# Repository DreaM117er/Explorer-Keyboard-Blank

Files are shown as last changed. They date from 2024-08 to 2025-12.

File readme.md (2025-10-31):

# Explorer Keyboard Blank 探索者3號

|4x6 v1|5x6 v1|
|--|--|
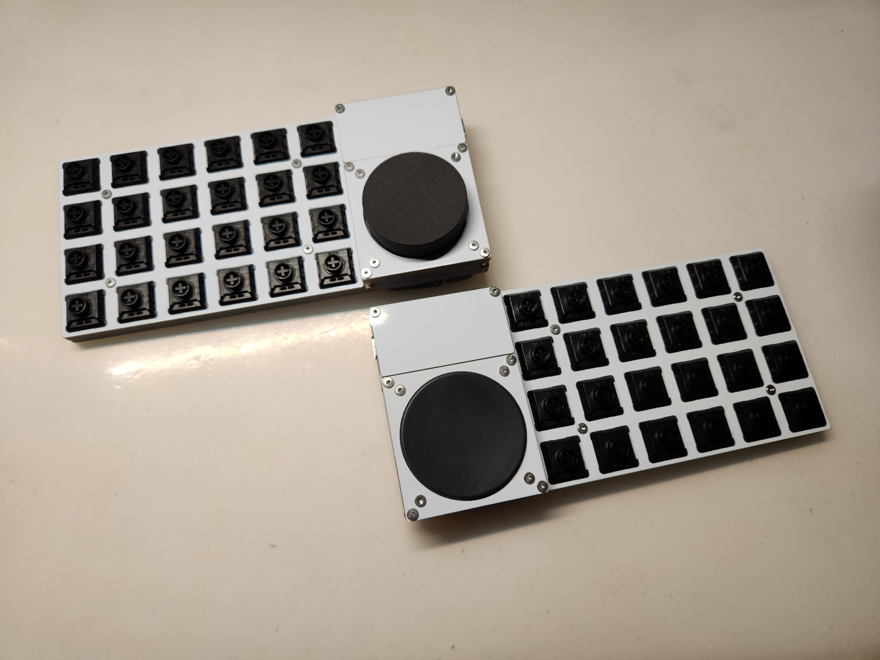
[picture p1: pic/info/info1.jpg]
info1
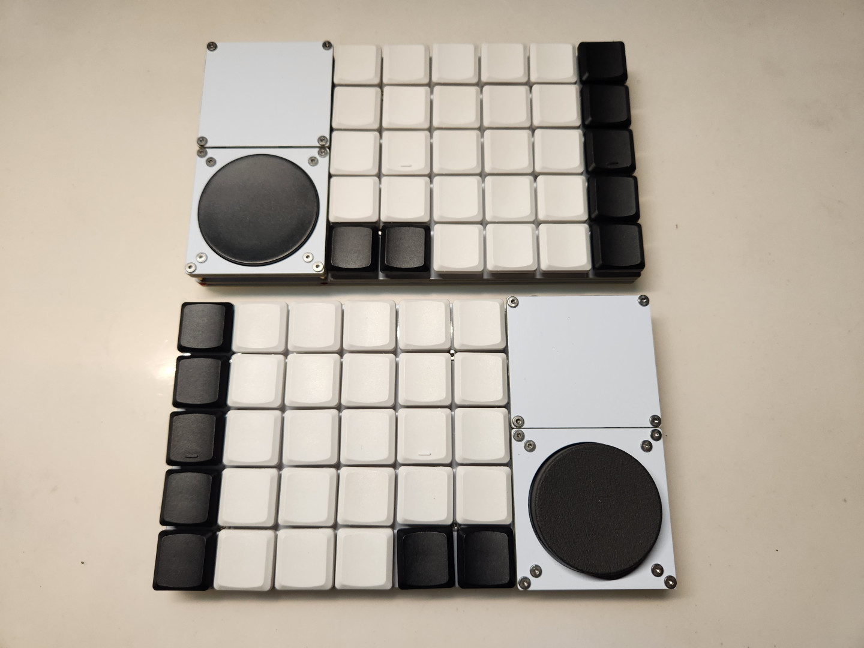
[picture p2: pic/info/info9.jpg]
info9
|||
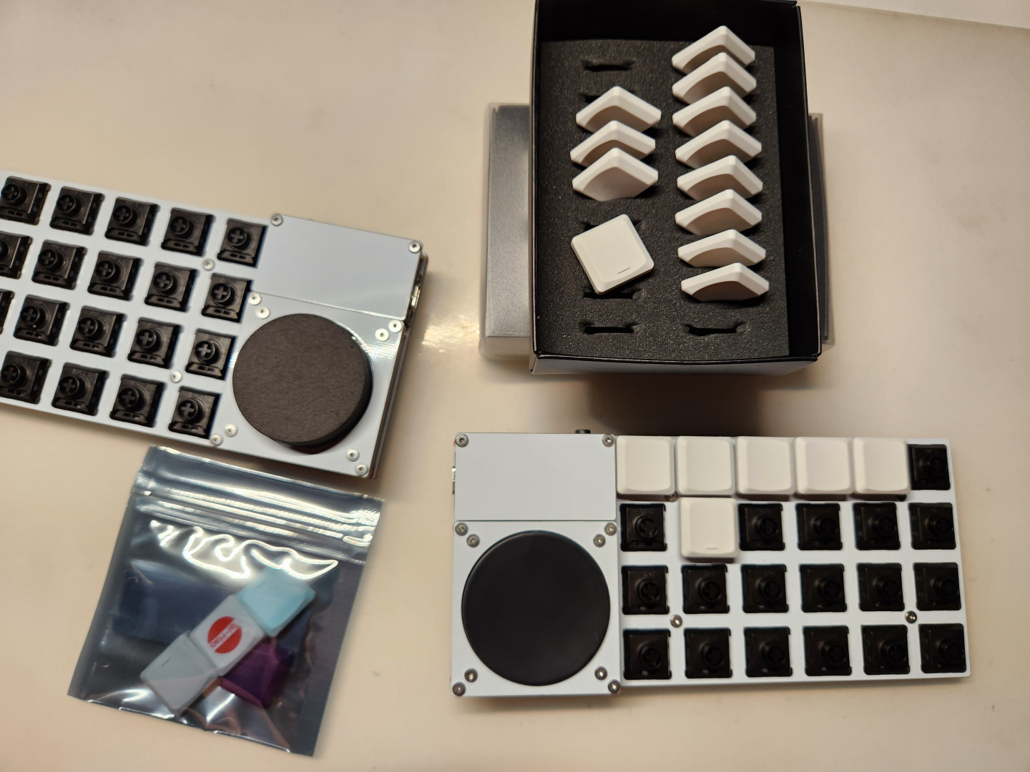
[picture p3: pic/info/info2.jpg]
info2
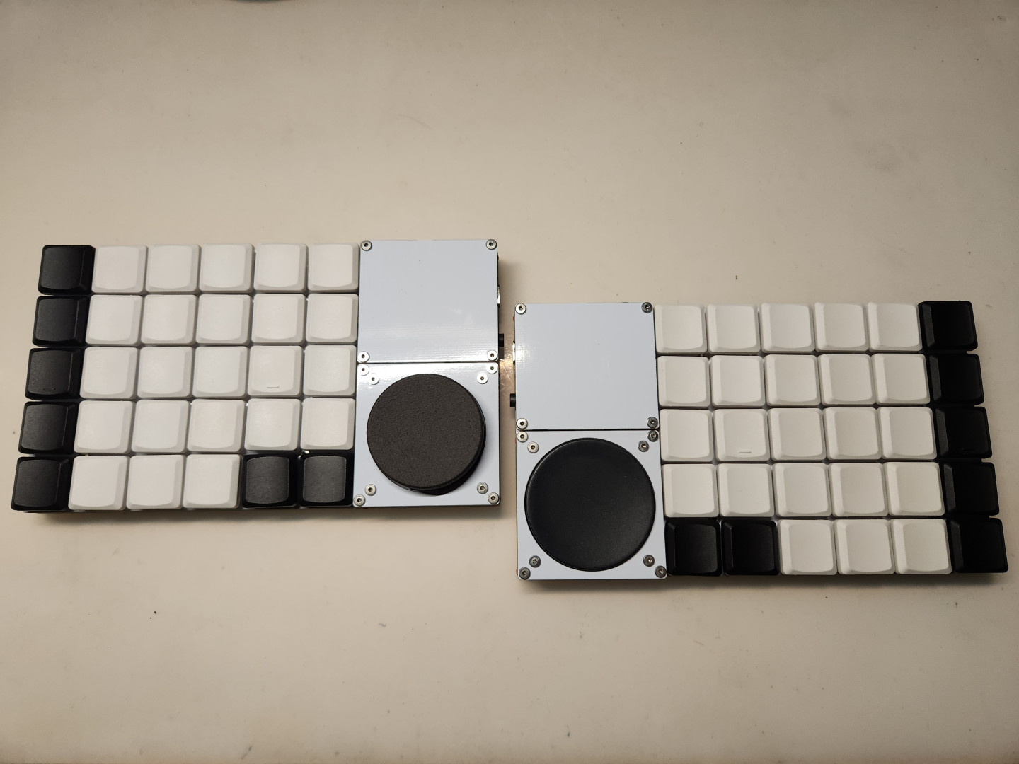
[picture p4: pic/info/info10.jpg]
info10
|||
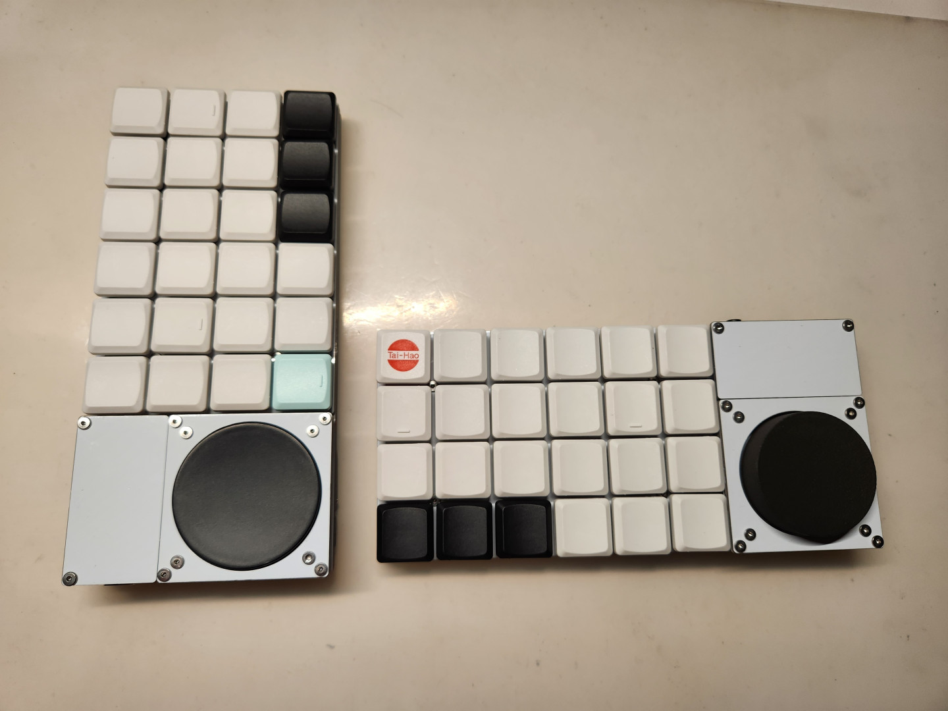
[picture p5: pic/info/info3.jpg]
info3
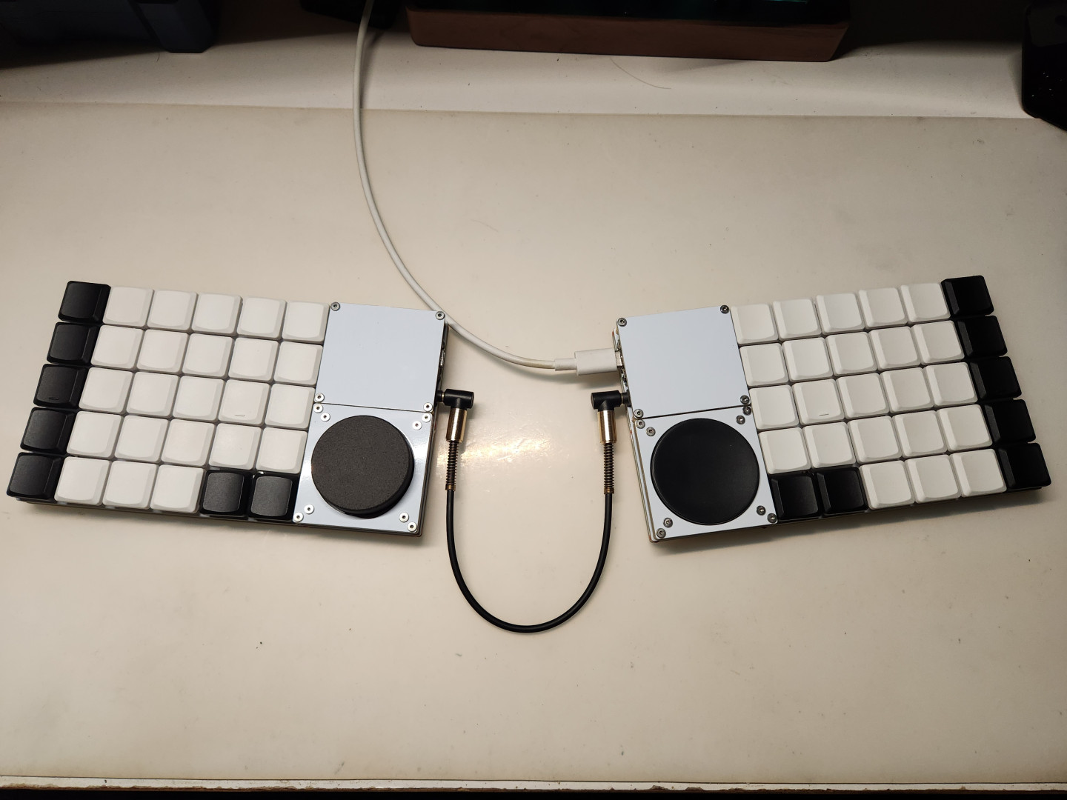
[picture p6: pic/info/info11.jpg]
info11
|||
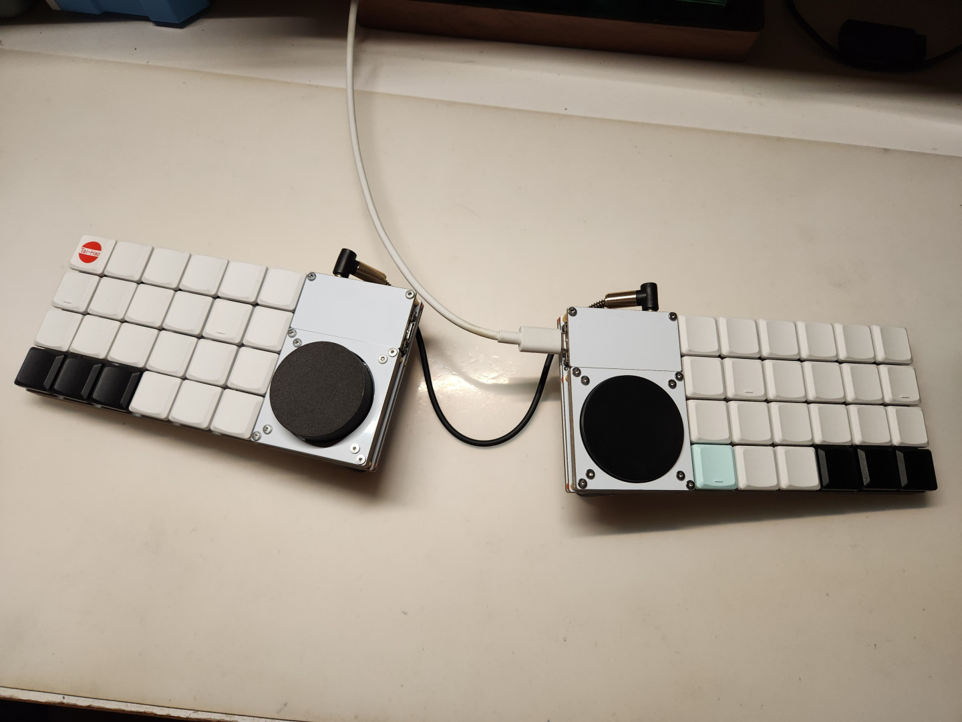
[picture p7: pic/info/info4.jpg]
info4
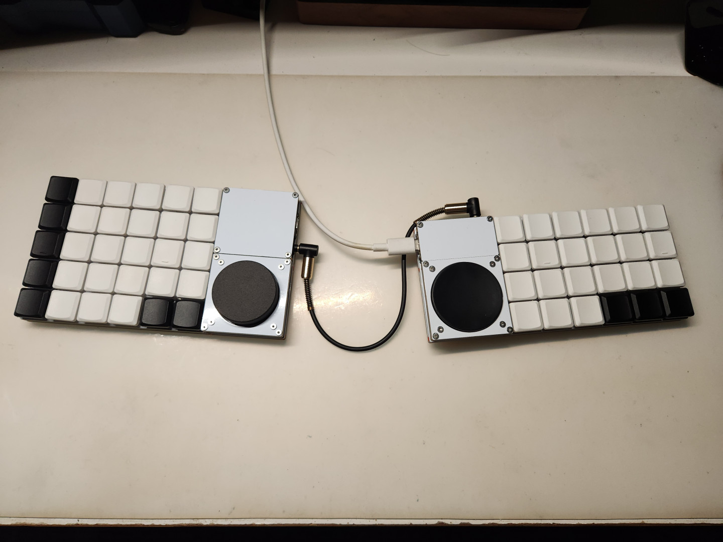
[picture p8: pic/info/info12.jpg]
info12
|||

## 開發者前言

Plank，是大部分人入坑人體工學鍵盤時最常接觸到的鍵盤，因為它方且正，許多的人體工學鍵盤的基礎都是在這個方正的鍵盤上延伸；

Blank，翻譯成中文的意思為空白。結合了Plank所需要的基礎，進而把鍵盤拓展成可分離的版本，你可以只使用單側、也可以使用兩側、可以在你需要的那一側加裝自己需要的特殊元件，也可以將元件放置在手的左或右側...

並且支援Kailh矮軸Choc v1、v2、Gateron矮軸GLP雙熱插拔，選擇自己所喜歡的按鍵軸及鍵帽——

因此將它歸為探索者系列，稱之為Blank，稱之為3號。

## 靈感來源

- 我只是想做一把簡單的鍵盤。
- 開發上一把鍵盤時發現我最多只需要2顆旋鈕。
- 不想思考太多。
- 突然想到自己曾經在beekeeb上看到Cirque 40mm的觸控板模組。
- 試試看做個能同時翻面支援的電路板好了。

如果想知道完整的開發過程，請詳細閱讀[開發日誌](log.md)中的內文。

## 前置作業

### 電路板

||4x6 v1|5x6 v1|
|--|--|--|
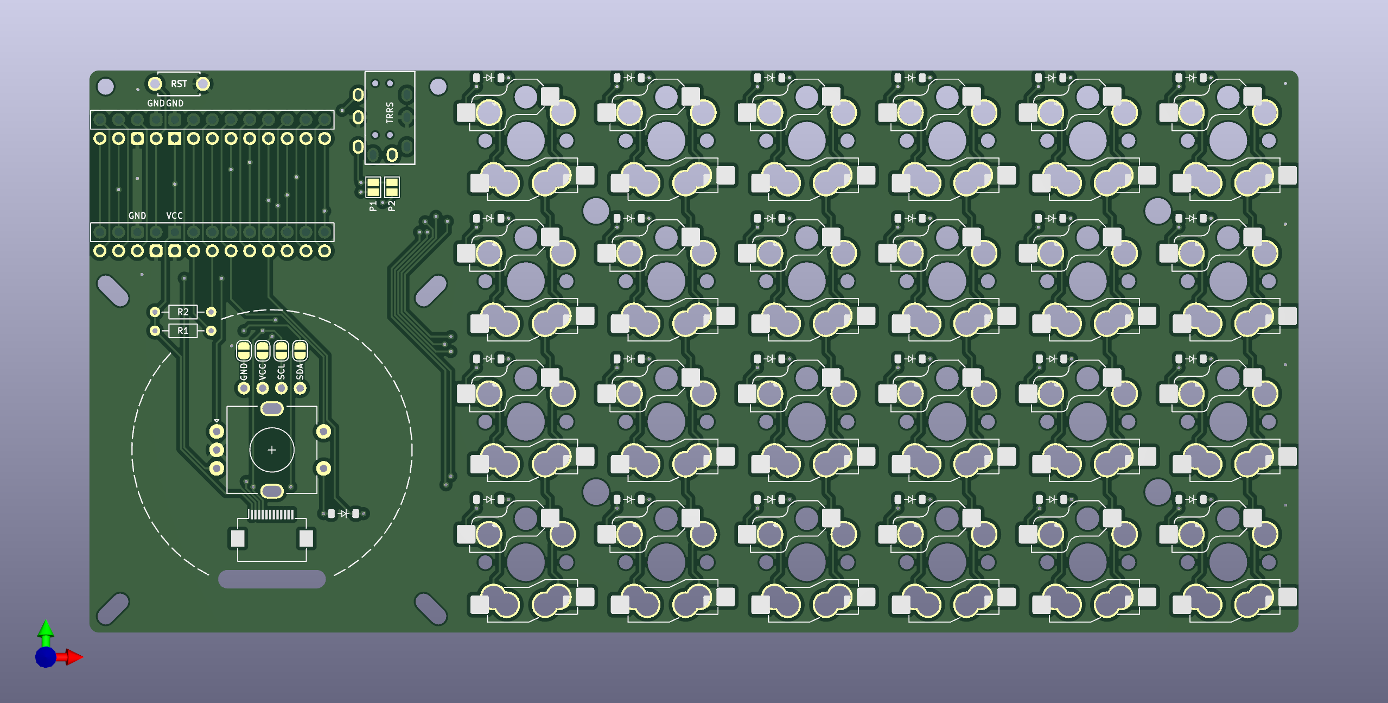
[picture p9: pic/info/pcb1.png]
pcb1
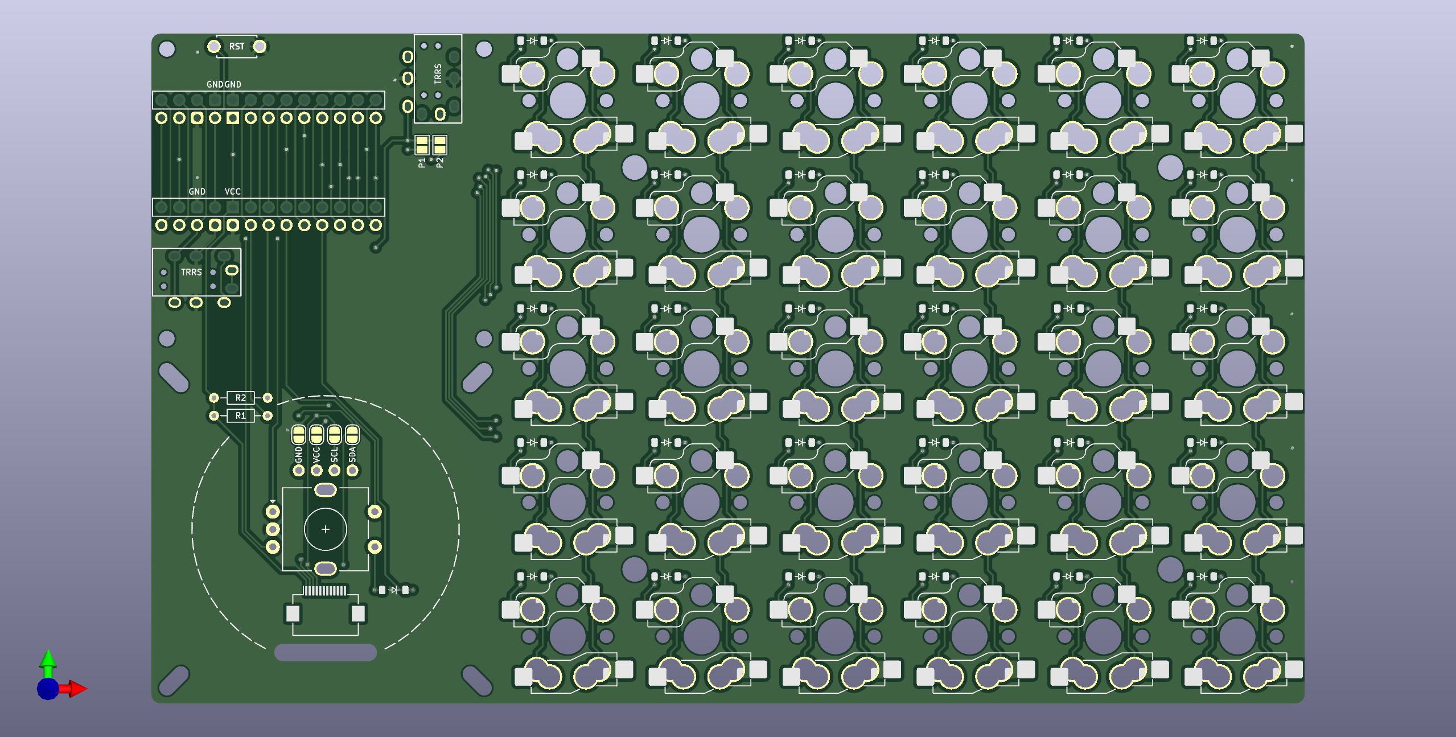
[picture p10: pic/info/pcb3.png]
pcb3
|正面|||
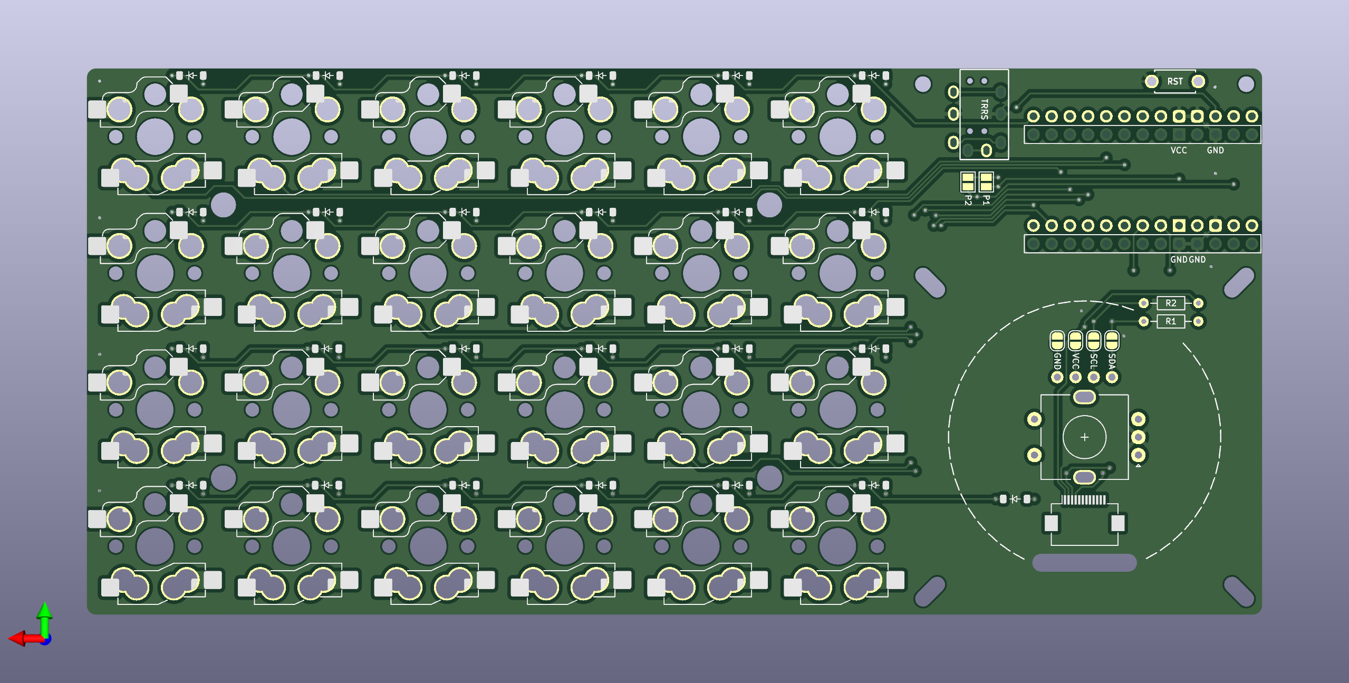
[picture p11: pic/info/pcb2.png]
pcb2
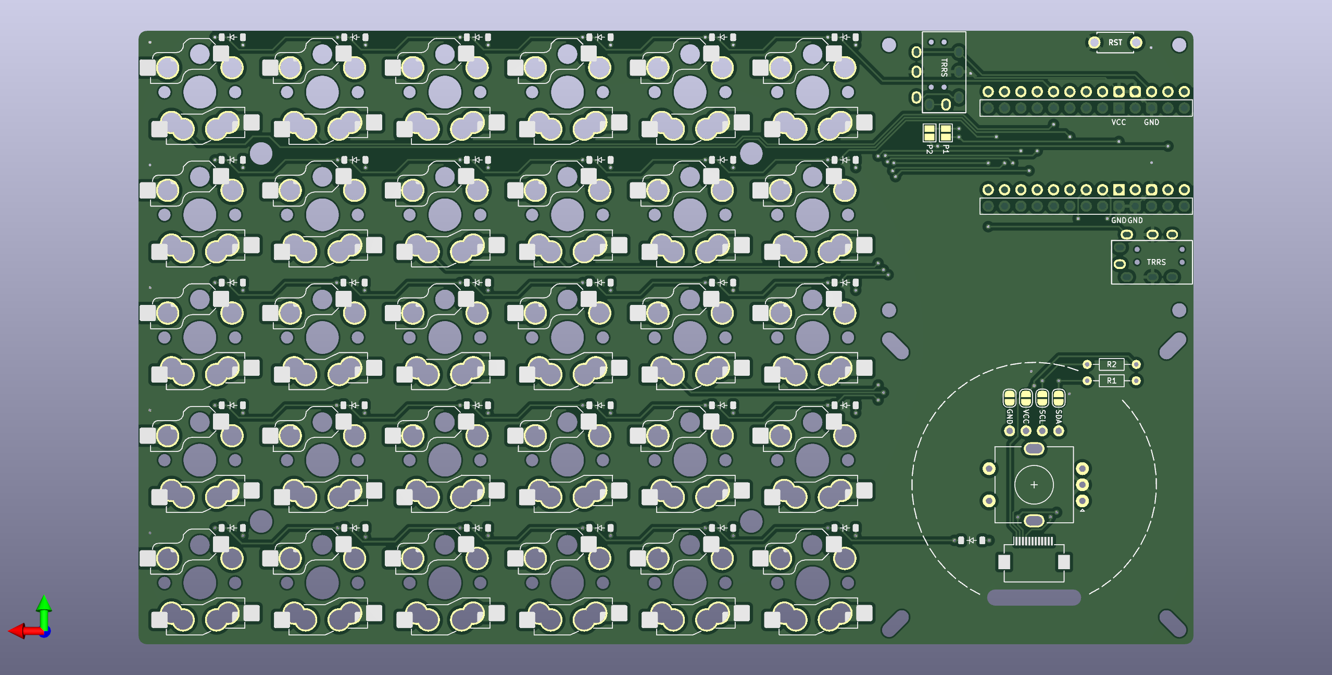
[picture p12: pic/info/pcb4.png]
pcb4
|背面|||

### 外殼

||4x6 v1|5x6 v1|
|--|--|--|
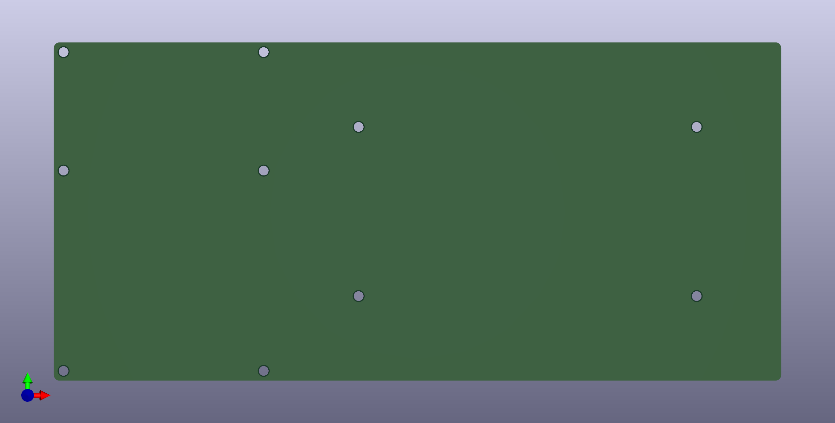
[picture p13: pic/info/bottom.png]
bottom
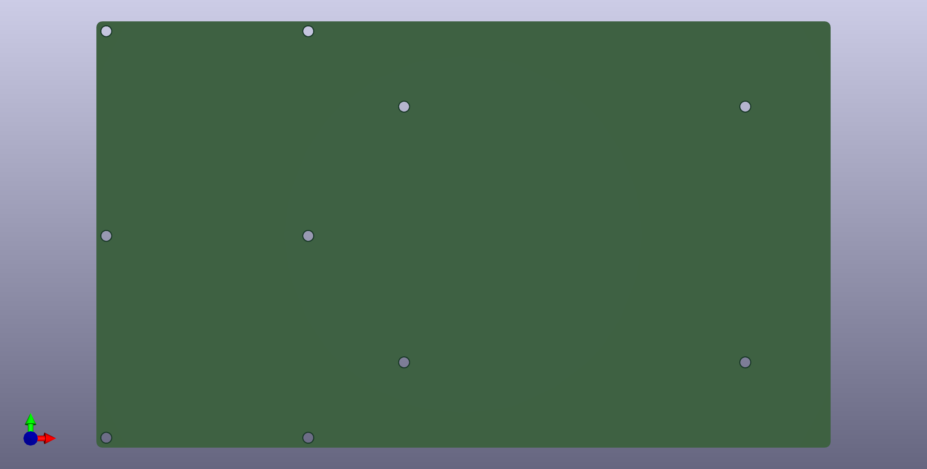
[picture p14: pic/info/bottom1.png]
bottom1
|底板|||
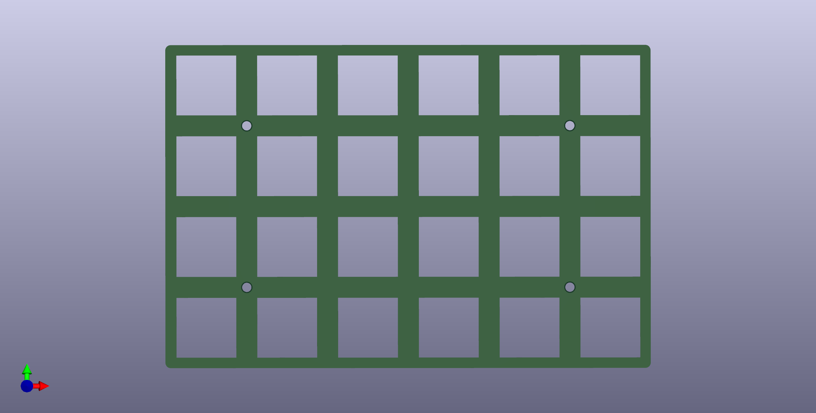
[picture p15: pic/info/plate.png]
plate
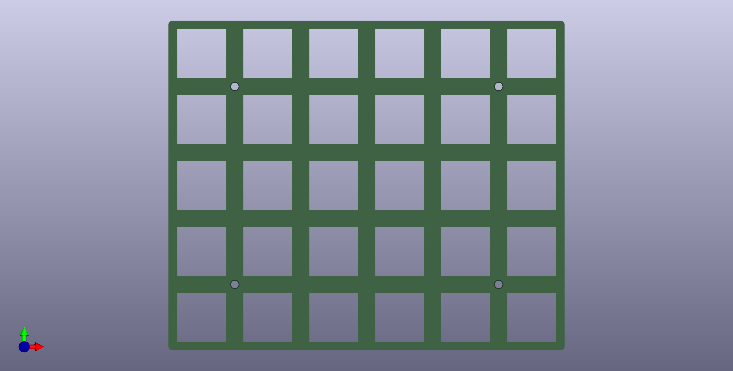
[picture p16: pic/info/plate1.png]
plate1
|定位板|||
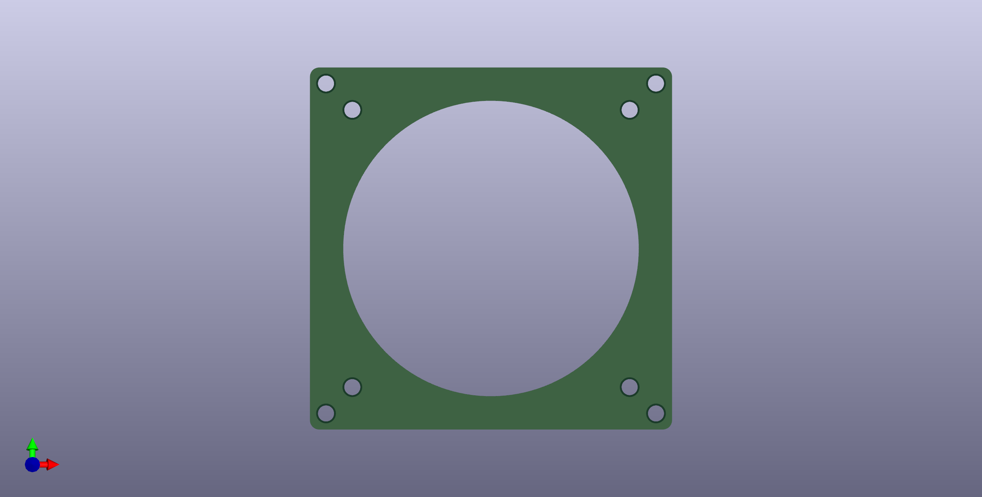
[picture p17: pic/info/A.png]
A
|擋板A||A|
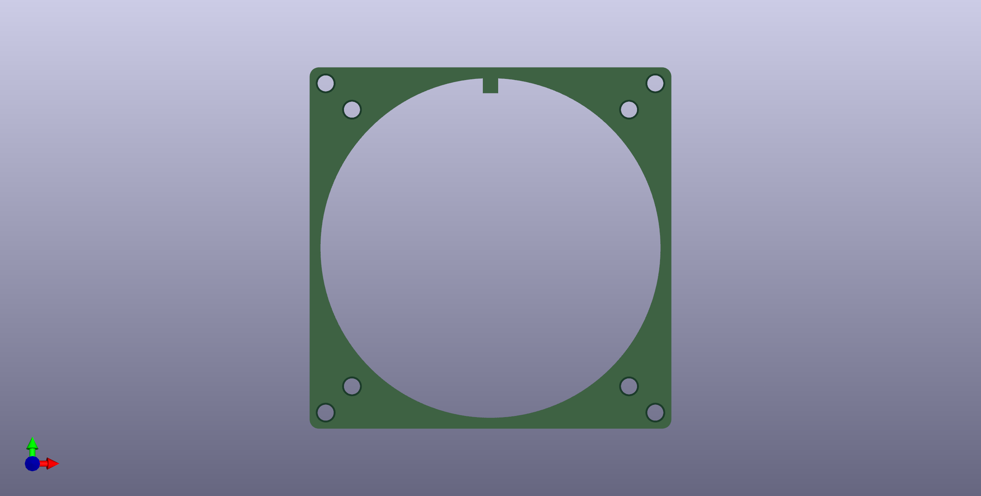
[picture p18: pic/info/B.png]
B
|擋板B||B|
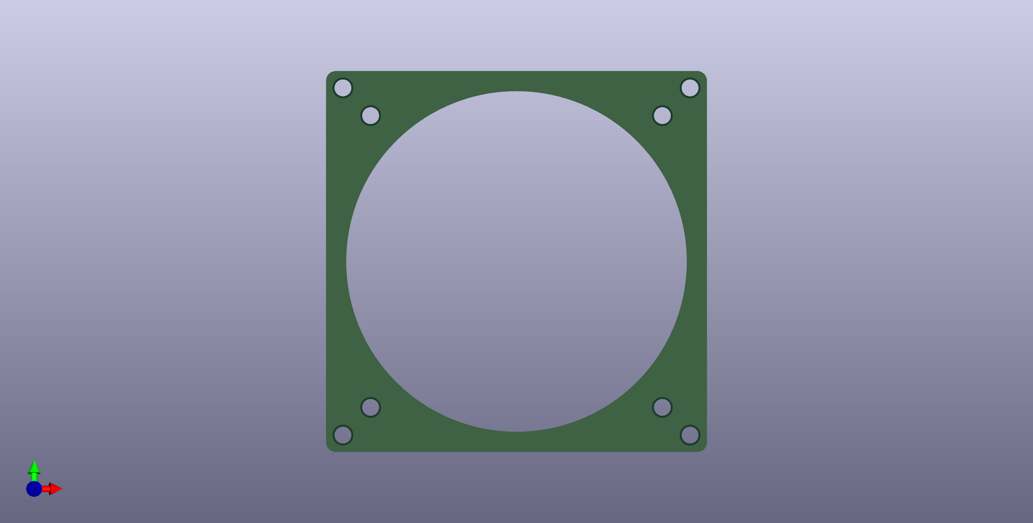
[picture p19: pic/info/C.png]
C
|擋板C||C|
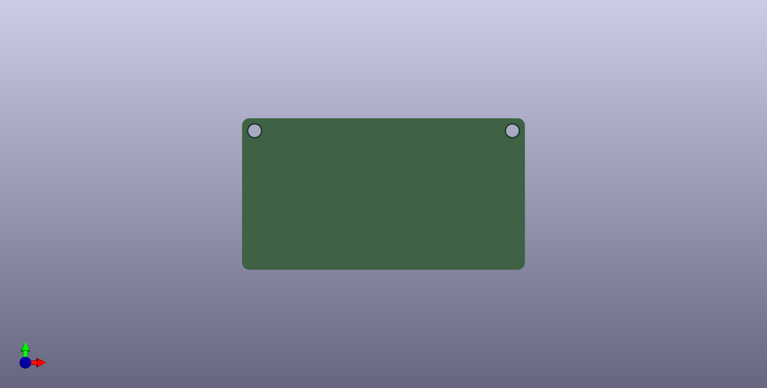
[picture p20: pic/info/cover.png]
Cover
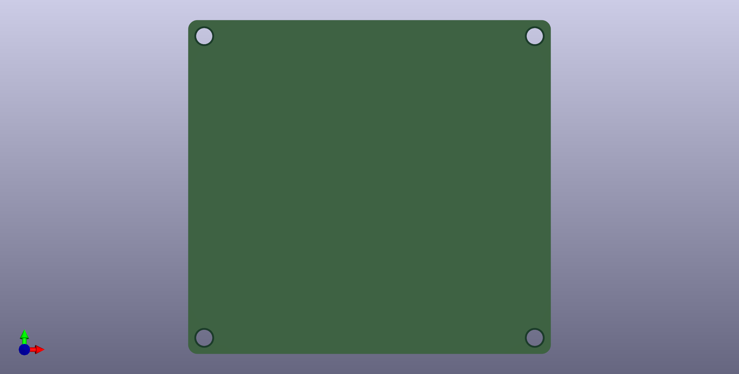
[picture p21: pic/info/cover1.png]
Cover1
|MCU擋板|||

### 會使用到的工具

|名稱|備註|詳細說明|
|--|--|--|
|電烙鐵|-|焊錫、助焊劑等相關工具組|
|防靜電鑷子|-|用於微調貼片元件使用|
|金屬鑷子|-|用於測試電路用|
|加熱台|選配|用於固定貼片元件使用|
|熱風槍|選配|用於固定貼片元件使用|

### 使用材料（單側組裝）

|4x6 v1|5x6 v1|
|--|--|
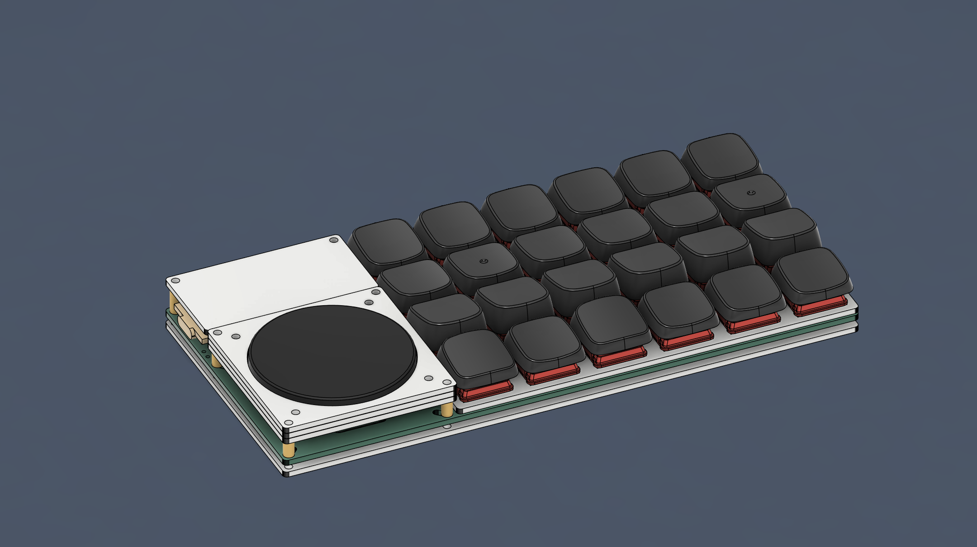
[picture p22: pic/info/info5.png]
info5
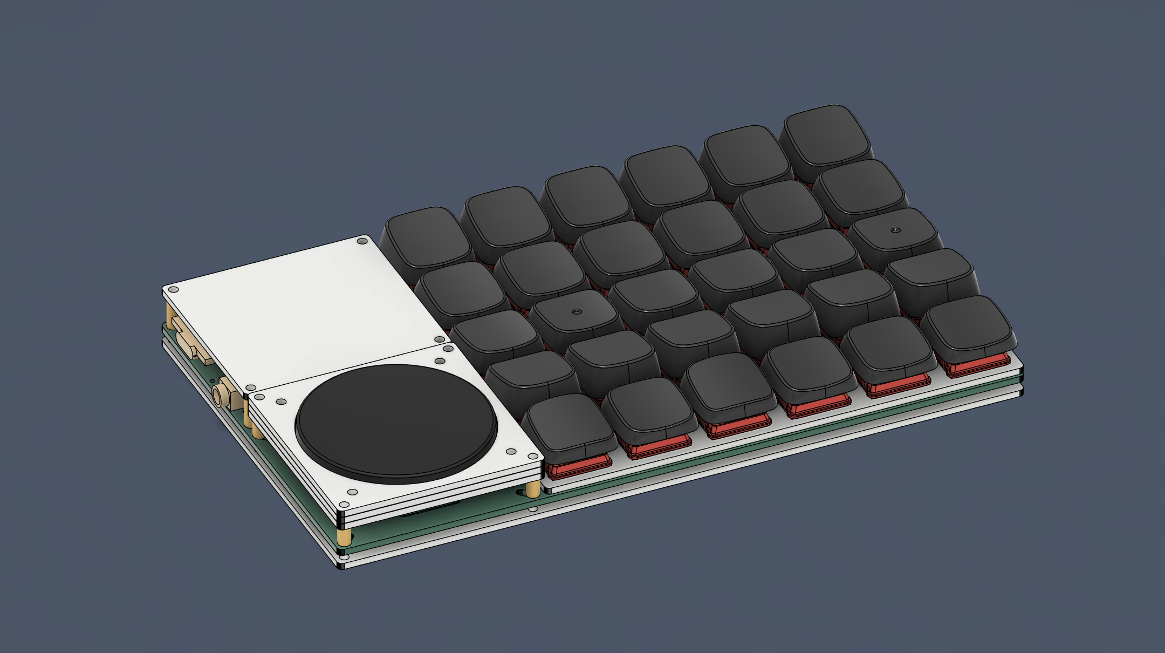
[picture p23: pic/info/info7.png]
info7
|||
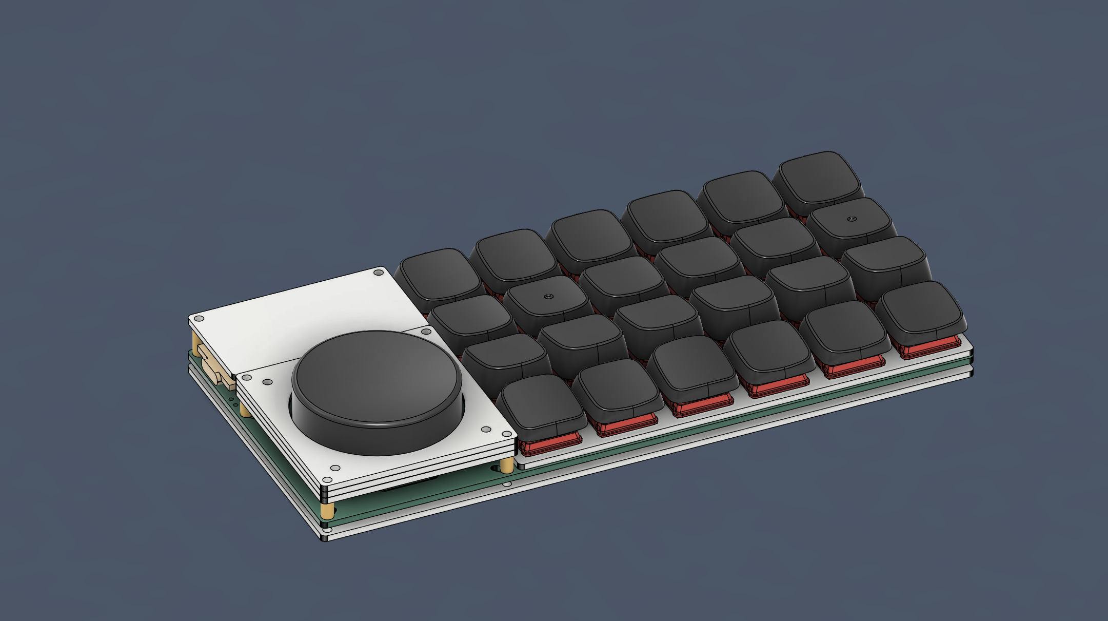
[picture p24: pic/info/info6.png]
info6
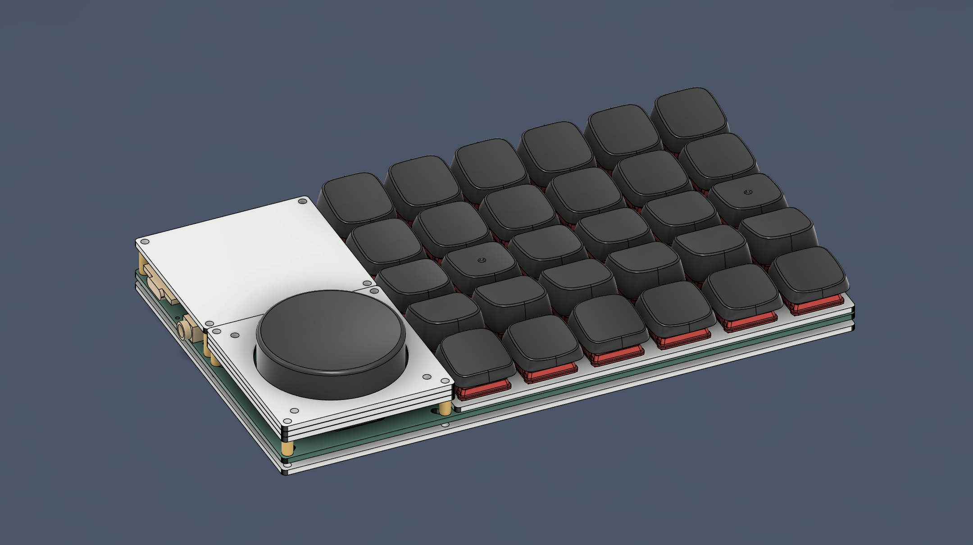
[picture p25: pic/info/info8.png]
info8
|||

|-|名稱|數量|數量|備註|詳細說明|
|--|--|--|--|--|--|
|||**4x6**|**5x6**|||
||PCB|1|-|-|雙面通用，`1.6mm`厚度|
||外殼|1|-|-|左右通用，`1.6mm`厚度|
|*|定位板|1|-|-|左右通用，`1.2mm`厚度|
|*|`ProMicro`|1|-|同腳MCU都可|推薦使用`RP2040`版本|
|*|二極體 `1N4148`|25|31|-|`SMD`貼片式|
|*|熱插拔座|24|30|`Choc`、`GLP`|二選一|
||`2pin`輕觸開關|1|-|-|-|
|*|M2螺絲墊片|6|-|-|穩固鍵盤結構使用|
||M2x`8mm` 扁頭螺絲|6|-|-|-|
||M2x`6mm` 扁頭螺絲|8|-|-|-|
||M2x`4mm` 扁頭螺絲|4|6|-|-|
||M2x`3mm` 扁頭螺絲|6|8|-|-|
||M2螺母|10|-|-|-|
||M2x`8mm` 雙通銅柱|2|4|-|-|
||M2x`5mm` 雙通銅柱|8|-|-|-|
||`ø8mm` `H1mm` 矽膠自黏腳貼|4|-|-|-|
|*|`Cirque` `40mm`觸控板|1|-|選配|推薦帶`曲面`之版本|
||`FFC` `12pin` 排線連接座|1|-|選配|如有`I2C轉接座`可不需使用|
|*|`FFC` `12pin` 軟排線|1|-|選配|`正對正接口`、`50mm`長即可|
|*|`4.7K` 上拉電阻|2|-|選配|`THT`直插式，安裝觸控板才需要使用|
|*|旋鈕編碼器|1|-|選配|`EC11`、`EC12`擇一使用；`L：10mm`、`A：4.5-5.0mm`，推薦`半軸` `D型`|
|*|旋鈕編碼器帽蓋|1|-|選配|`ø39mm`、`軸孔深4.5mm`特製版，推薦3D列印|
||`3.5mm` `TRRS`座|1|2|選配|單側安裝不需使用|

探索者3號支援各大網路商家販售的Cirque 40mm的觸控板模組拓展包，裡頭基本一應俱全，可考慮直接從通路購買：

- [40mm Cirque GlidePoint Circle Trackpad Module DIY Kit for Split Mechanical Keyboard](https://shop.beekeeb.com/product/40mm-cirque-glidepoint-circle-trackpad-module-diy-kit-for-split-mechanical-keyboard/)
- [GlidePoint Cirque Trackpad TM040040 TM035035](https://keycapsss.com/keyboard-parts/parts/211/glidepoint-cirque-trackpad-tm040040-tm035035)

### 注意事項

1. 上面表列材料表為`單片電路板安裝使用`。
2. 列表前標記`*`的材料為極度重要之零組件，請留意是否準備齊全，參照如下：

    - 二極體`1N4148`及`熱插拔座`請務必準備齊全，否則鍵盤會無法正常使用。
    - 旋鈕`編碼器`需搭配`帽蓋`一起安裝。
    - Crique 40mm`觸控板`需搭配`4.7k上拉電阻`、`12pin軟排線`安裝，缺一不可，請特別留意。
    - `M2螺絲墊片`務必準備齊全，有關鍵盤整體的`結構`，務必安裝上去。
 
3. 機械鍵軸務必跟隨熱插拔座的規格進行購買，因為`Choc跟GLP規格不相容`。
4. 使用電烙鐵時務必留意`環境通風`、`用電安全`及`燙傷預防`。
5. 在進入組裝環節之前，務必先將beekeeb及Keycapsss的組裝流程看過一輪：

    - [Cirque Trackpad i2c on Corne Keyboard Build Log](https://beekeeb.com/cirque-trackpad-i2c-on-corne-keyboard/)。
    - [GlidePoint Cirque Trackpad with Adapter PCB](https://keycapsss.com/help/cirque-trackpad/#spi-or-i2c)。

環境及材料都準備完畢之後，就可以開始進入[組裝環節](guide.md)了。

## 無私的感謝

### 工具軟體
- [KiCAD](https://www.kicad.org/) version `7.0.5`。
- [Autodesk Fusion](https://www.autodesk.com/products/fusion-360/free-trial)。
- [QMK](https://qmk.fm/)、[VIAL](https://get.vial.today/)。

### 規格書
- [TM040040 Trackpad](spc/TM040040.pdf)。
- [Resistor_THT](spc/Resistor_THT.png)。
- [molex 781271110 0.5 FPC CONN.](spc/FPC-Conn-781271110.pdf)。
- ALPS [EC11](<spc/Rotray Encoder EC11.pdf>)、[EC12E](<spc/Rotray Encoder EC12E.PDF>)。

### 商家及廠家
- [太豪股份有限公司](https://www.tai-hao.com/tw/)。
- [凱華電子有限公司](http://www.kailh.com/index.html)。
- [nuphy](https://nuphy.com/)及[Gateron](https://www.gateron.co/)。
- [beekeeb](https://shop.beekeeb.com/)。
- [Keycapsss](https://keycapsss.com/)。
- [JLCPCB](https://jlcpcb.com/)。

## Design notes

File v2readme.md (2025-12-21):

# Explorer Keyboard Blank v2 探索者3號 v2

|4x6 v2|5x6 v2|
|--|--|
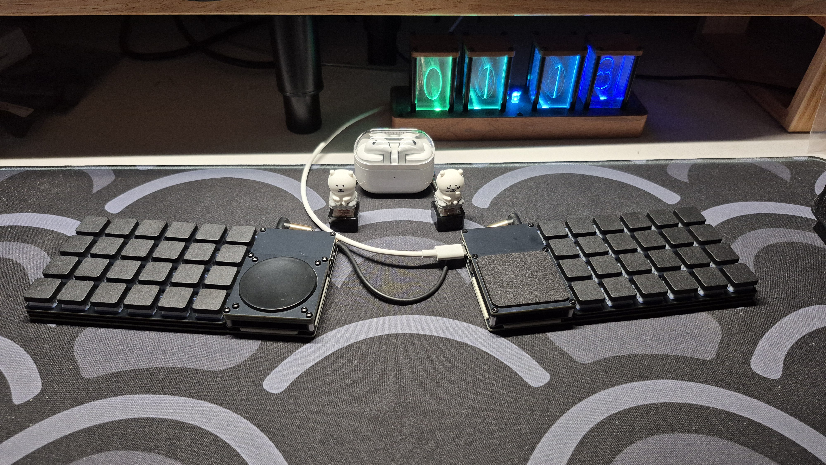
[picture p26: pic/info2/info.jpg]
4x6info
|||

## 說明 (Introduction)

這裡是探索者3號 v2 的說明，我其實也沒想到它會受到這麼多關注，這點我覺得真的要感謝**beekeeb**，我之後會慢慢打開這個市場，讓更多人認識我設計的鍵盤。

——首先，我**爲什麼**要設計Blank v2？

v1 的產生是有經過思考的成果，但我經過學習電路學，正式開始硬體設計鍵盤的時候再回頭看這把鍵盤，它還是不夠深思熟慮，有很多地方是沒有考慮到的。

——那麼，它**升級了什麼？**

我直接列表格讓大家看過之後再來比較看看我到底升級了什麼吧：

|項目|說明|v1|v2|
|--|--|--|--|
|`ProMicro`腳位開發板|`ATMEGA32U4`|&#9989;|&#9989;|
|-|`RP2040`|&#9989;|&#9989;|
|-|`NRF52840`|&#10060;|&#9989;|
|通訊方式|`Half Duplex`|&#9989;|&#9989;|
|-|`Full Duplex`|&#10060;|&#9989;|
|電源保護|針對`TRRS`座|&#10060;|&#9989;|
|配列調整|-|&#10060;|&#9989;|
|螺絲螺母|使用量|多|少|
|銅柱|最大規格支援度|ø3mm|**ø4mm**|
|觸控板模組|`TM040040`|&#9989;|&#9989;|
|-|`TPS43`|&#10060;|&#9989;|
|鍵軸開關|`MX`|&#10060;|&#9989;|
|-|`Choc v1`|&#9989;|&#9989;|
|-|`Choc v2`|&#9989;|&#9989;|
|-|`GLP1.0-2.0`|&#9989;|&#10060;|
|-|`GLP3.0`|&#10060;|&#9989;||

我覺得不用寫太多說明大家都可以理解升級的內容是什麼，會放棄`GLP1.0-2.0`矮軸也是因爲`3.0`的腳位跟MX軸相同，所以我想都沒想就決定要改腳位。

無線開發板的想法也是，我個人不喜歡無線設備，但因爲這把鍵盤關注度提升了很多，是時候要增加新的可能性讓大家去玩、去探索，這也是**探索者鍵盤系列**的終極目標，而且`ZMK`能夠支援指向裝置（Pointing Device）也是個原因之一。

——有人說我一次把鍵盤的功能升級過頭了。

思考一下，如果你哪天真的踏入了`QMK`、`ZMK`韌體的設計領域了，你想嘗試或已經更改了什麼、增加了什麼新功能，這把鍵盤的電路板上的分支路線都能夠支援，你會怎麼想呢？

反正我不在意誰怎麼說，我只在意**你探索到哪裡了？**

## A. 使用材料 (Bill of Materials)

|4x6-LP|4x6-MX|4x5-LP|4x5-MX|
|--|--|--|--|
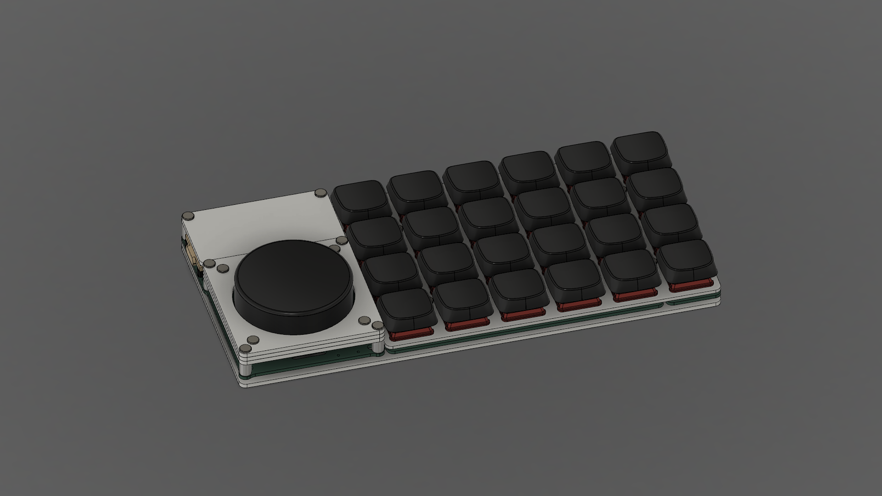
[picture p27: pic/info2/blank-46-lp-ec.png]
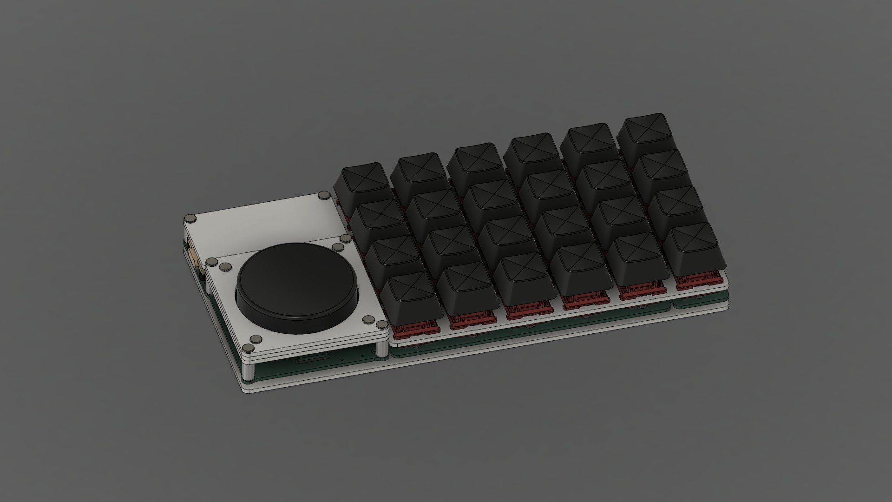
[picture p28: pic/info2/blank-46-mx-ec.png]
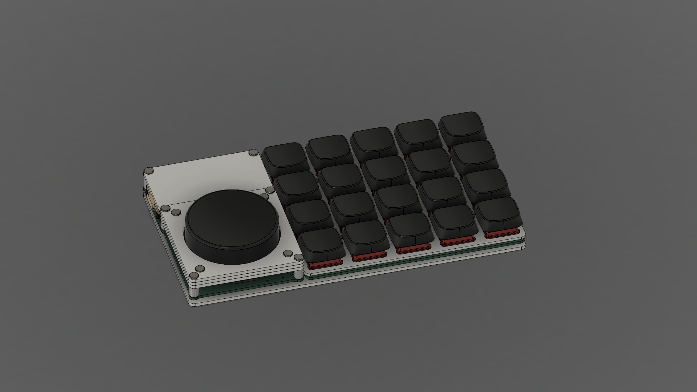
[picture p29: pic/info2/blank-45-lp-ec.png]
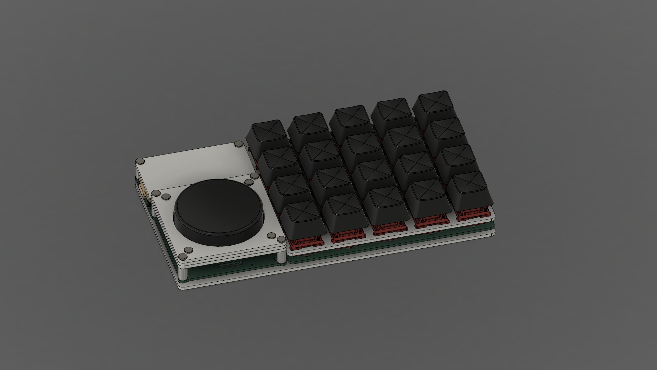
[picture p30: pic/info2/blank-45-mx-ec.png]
|||||
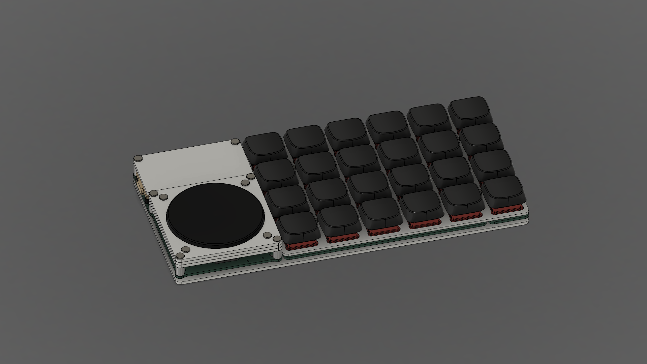
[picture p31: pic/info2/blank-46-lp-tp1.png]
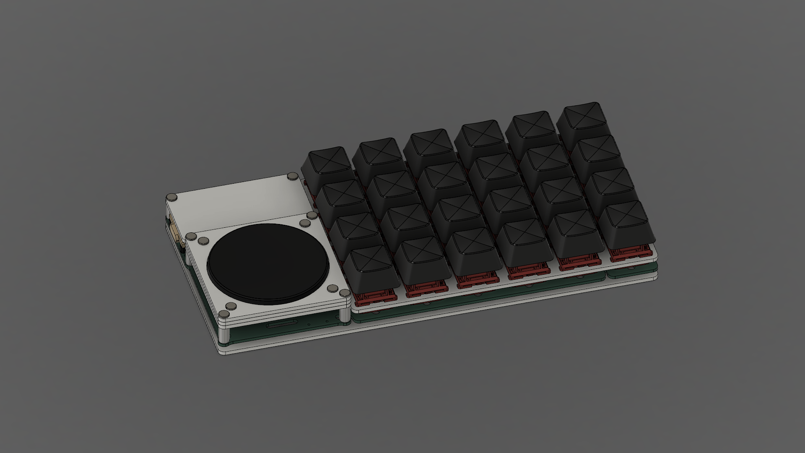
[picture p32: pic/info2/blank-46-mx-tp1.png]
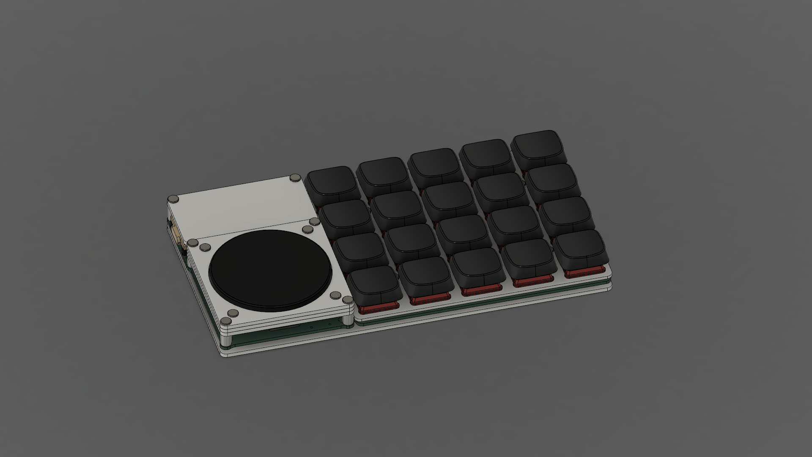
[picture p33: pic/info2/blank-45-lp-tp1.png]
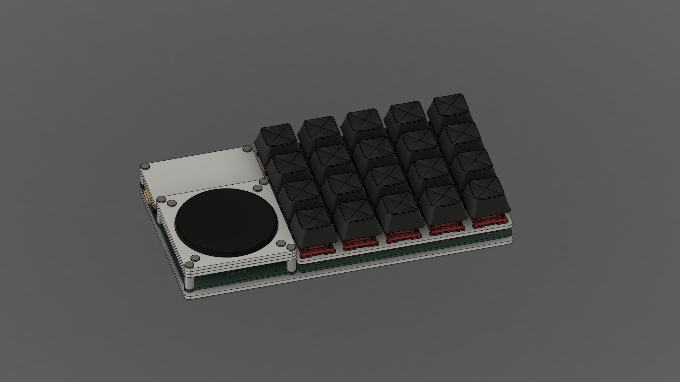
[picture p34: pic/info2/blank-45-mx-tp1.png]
|||||
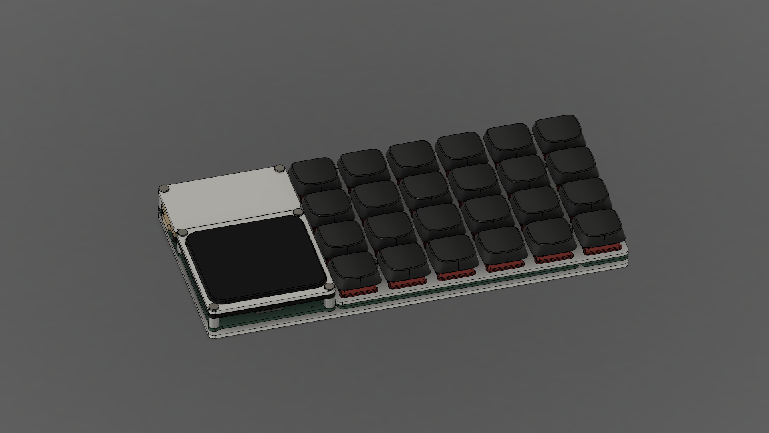
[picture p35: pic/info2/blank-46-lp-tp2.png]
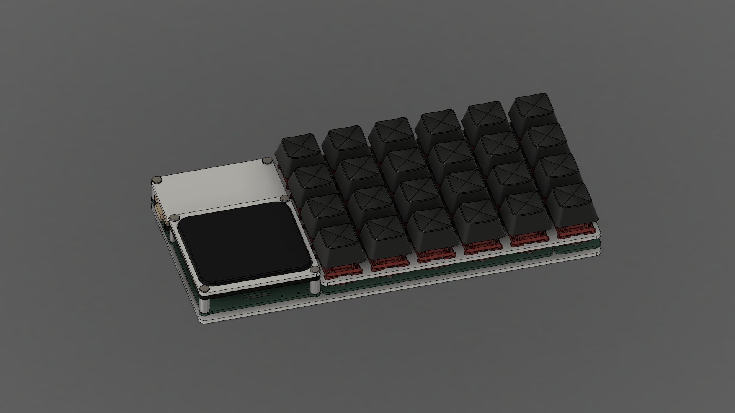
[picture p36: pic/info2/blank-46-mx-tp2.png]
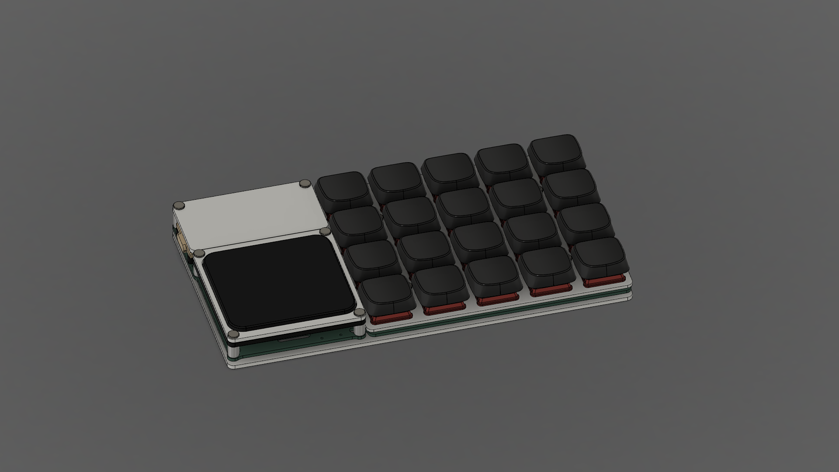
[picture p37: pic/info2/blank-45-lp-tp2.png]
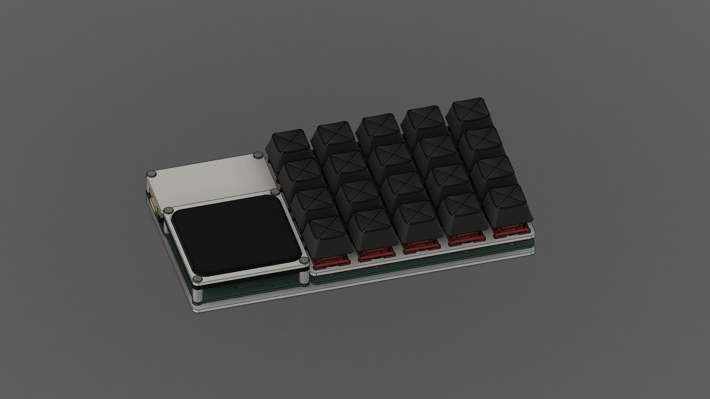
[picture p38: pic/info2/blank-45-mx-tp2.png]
|||||

|5x6-LP|5x6-MX|5x5-LP|5x5-MX|
|--|--|--|--|
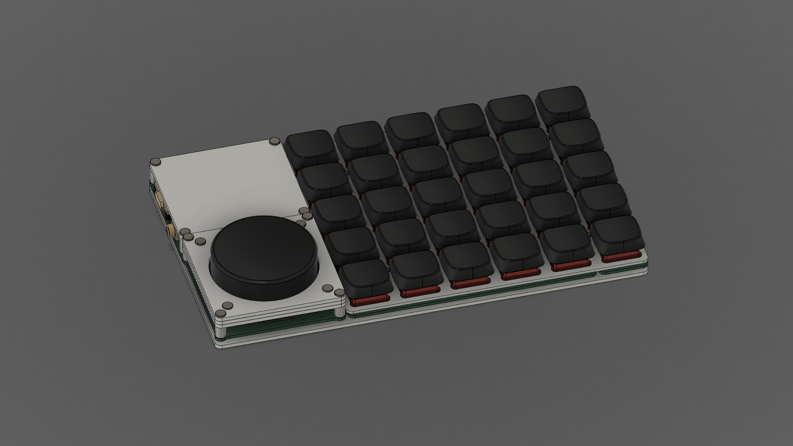
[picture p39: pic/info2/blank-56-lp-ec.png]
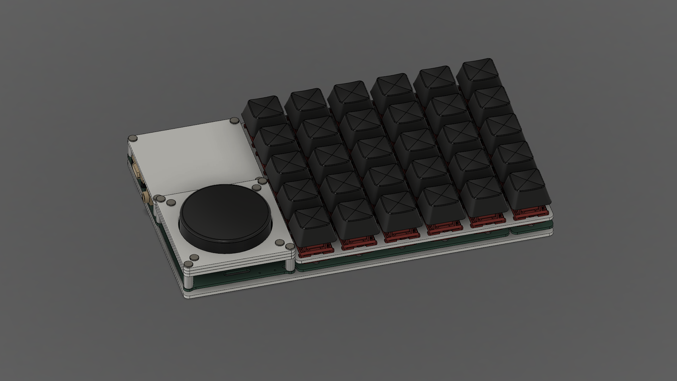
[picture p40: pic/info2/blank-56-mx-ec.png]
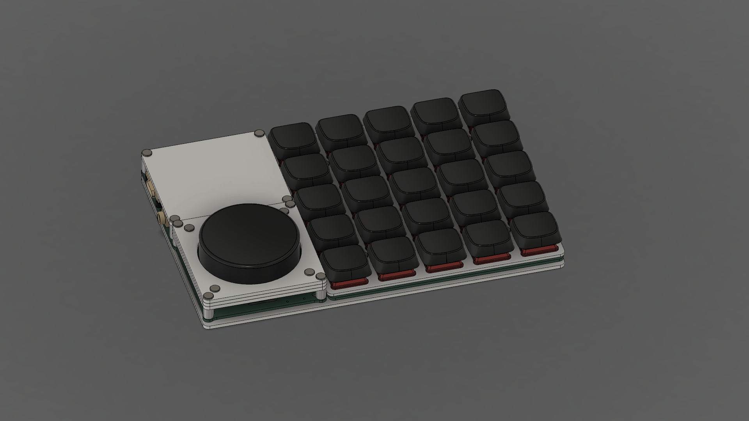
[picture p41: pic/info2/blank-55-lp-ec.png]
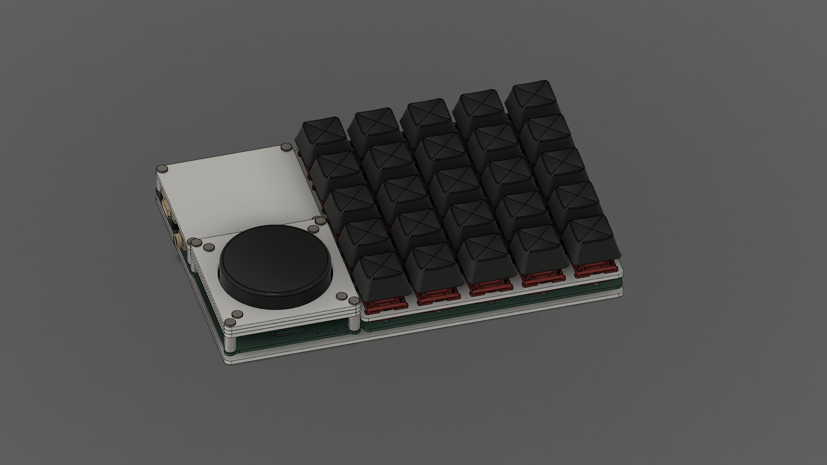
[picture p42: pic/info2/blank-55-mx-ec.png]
|||||
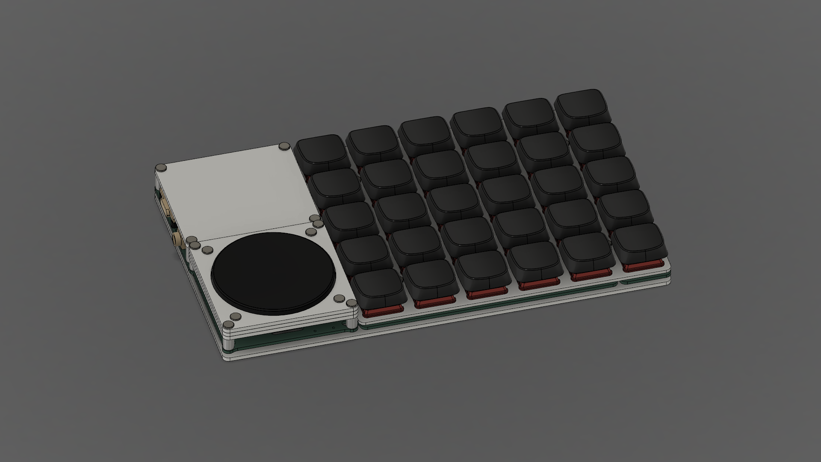
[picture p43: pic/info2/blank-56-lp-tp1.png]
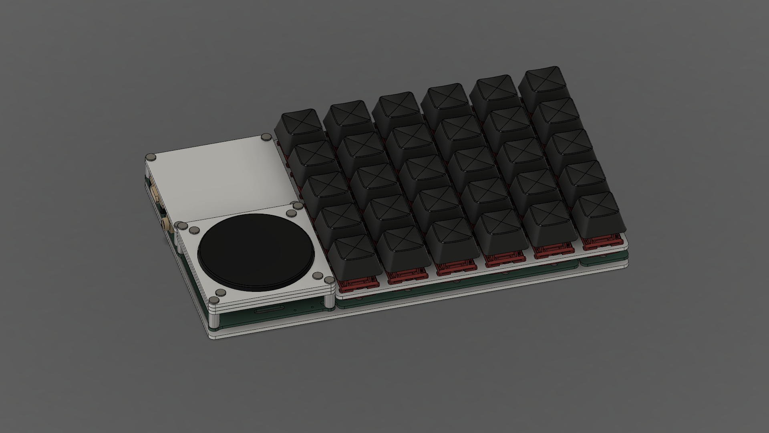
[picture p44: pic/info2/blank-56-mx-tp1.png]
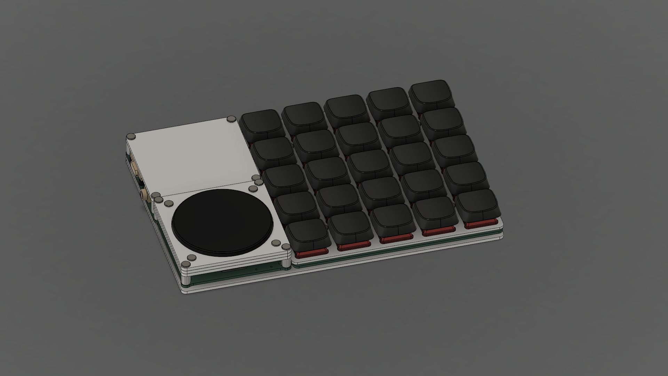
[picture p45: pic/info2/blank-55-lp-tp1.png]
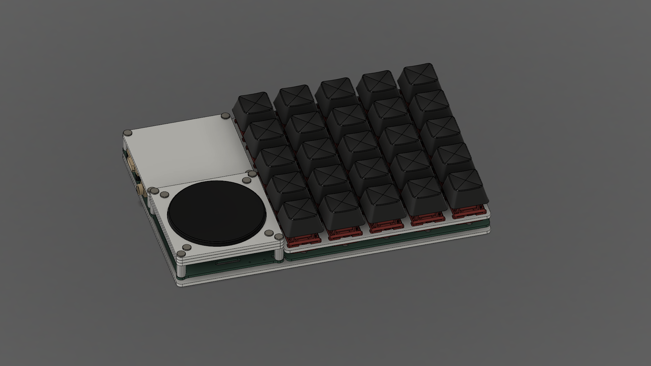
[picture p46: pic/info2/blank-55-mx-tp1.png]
|||||
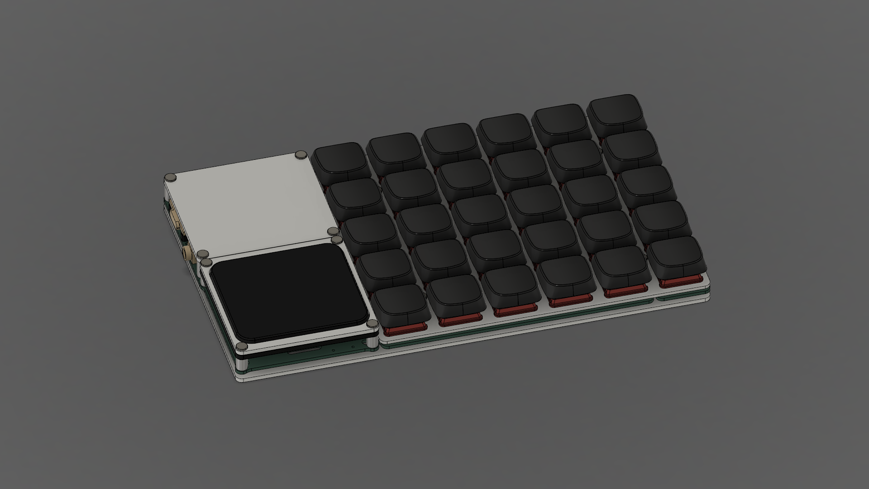
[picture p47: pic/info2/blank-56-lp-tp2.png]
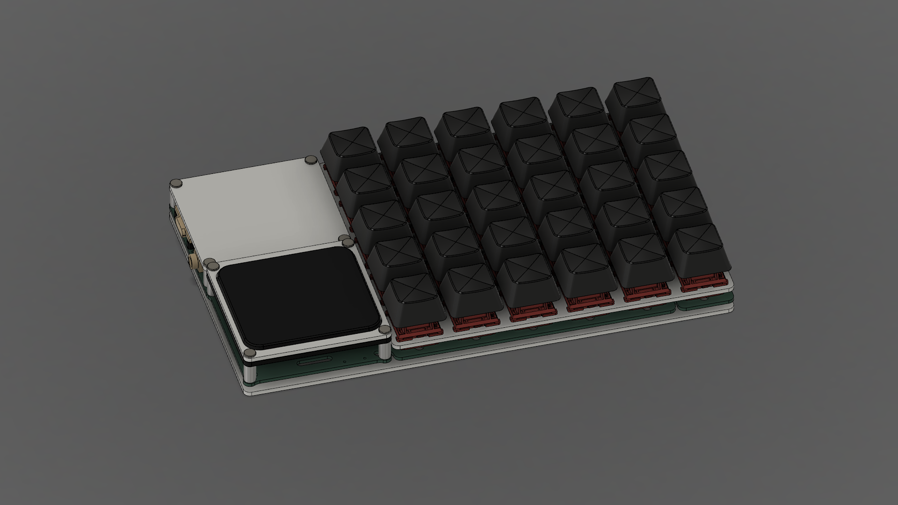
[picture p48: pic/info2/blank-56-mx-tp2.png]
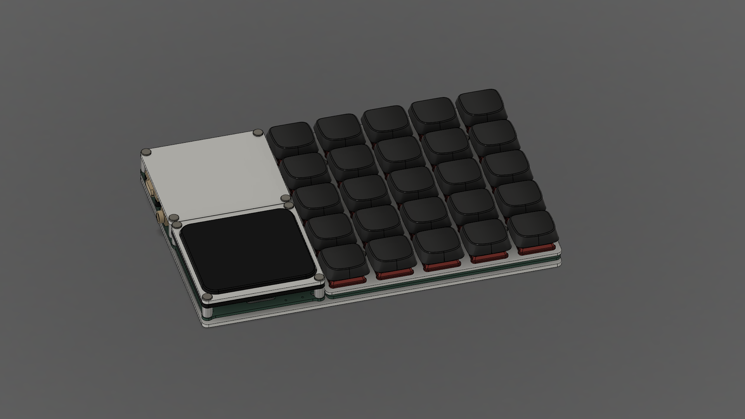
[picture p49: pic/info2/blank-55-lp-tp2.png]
||||

> 以下表格跟 v1 的說明一樣，爲組裝**單邊**鍵盤的材料數量。

> 配列後面沒有標註`MX`、`LP`，代表版本通用。

### 1. 必要電路元件 (Main Components)

|||數量|數量|數量|數量|說明|
|--|--|--|--|--|--|--|
|**項目**|**規格**|**4x6**|**5x6**|**4x5**|**5x5**|-|
|電路板|-|1|1|1|1|雙面通用，厚度`1.2mm`|
|開發板|`ProMicro`|1|1|1|1|同腳位MCU，推薦`RP2040`及`NRF52840`|
|`1N4148`|`SOD-123`|25|31|21|26|不安裝編碼器，少用1個|
|熱插拔座|`MX`, `Choc`|24|30|20|25|-|
|輕觸開關|`2 Pin`, `6x3.5x4.3mm`|1|1|1|1|`RESET`刷韌體用|

### 2. 選配元件 (Optional)

|||數量|數量|說明|
|--|--|--|--|--|
|**項目**|**規格**|**4x6 & 4x5**|**5x6 & 5x5**|-|
|`TRRS`座|`PJ-320A`, `THT`|1|2|有線分離式鍵盤用|
|`Polyfuse`|`6V-500mA`, `0805`|1|1|自恢復保險絲，強烈推薦使用|
|滑動開關|`MSKT-12D14`|1-2|1-2|主電池迴路、電量偵測模組用|
|編碼器|`EC-11`, `EC-12`|1-2|1-2|`L10mm`, `A4.5-5.0mm`|
|觸控板模組|`Cirque TM040040`|1-2|1-2|推薦曲面觸控面版本|
|觸控板模組|`Azoteq TPS43-201A-S`|1-2|1-2|-|
|電阻|`4.7K`, `1/4W`, `THT`|2|2|安裝`TM040040`必備|
|排線座|`FFC-0.5mm`, `12 Pin`|1|1|`TM040040`用|
|-|`FFC-0.5mm`, `6 Pin`|1|1|`TPS43`用|
|聚合物鋰電池|`3.7V`|1|1|容量、規格大小自己決定|
|臥貼排線母座|`PH2.0-2 Pin`, `THT`|1|1|無線開發板用|
|臥貼排線公座|`PH2.0-2 Pin`|1|1|無線開發板用，接鋰電池+-極|
|電池電量顯示模組|-|1|1|監測範圍`3.7-4.2V`|
|矽膠自黏腳貼|`ø8x1mm`|4|4|數量可因個人想法決定數量|
|鍵軸開關|`MX`、`Choc v1`、`Choc v2`、`GLP3.0`|20-24|25-30|自行決定|
|編碼器帽蓋|`ø39mm`, `L4.5mm`|1|1|有提供3D模型列印使用|

> v2 在結構上**不需**使用任何螺絲墊片或橡膠墊圈。

### 3. 機構元件 (Structure)

|||數量|數量|數量|數量|說明|
|--|--|--|--|--|--|--|
|**項目**|**規格**|**4x6-LP**|**5x6-LP**|**4x6-MX**|**5x6-MX**|-|
|外殼|-|1|1|1|1|單位爲組，`1.5mm`或`1.6mm`厚度|
|定位板|-|1|1|1|1|`LP版`爲`1.2mm`、`MX版`爲`1.6mm`|
|螺絲|`M2x3mm`|16|20|16|20|-|
|-|`M2x6mm`|8|8|8|8|-|
|六角螺母|`M2`|4|4|4|4|只需用在`Cover-A`、`B`、`C`固定|
|雙通銅柱|`ø3-4mm`, `M2x4mm`|4|4|-|-|-|
|-|`ø3-4mm`, `M2x5mm`|4|4|-|-|-|
|-|`ø3-4mm`, `M2x7mm`|2|2|10|10|-|
|自黏Poron貼條|`2mm厚度`|-|-|-|-|`重要機構一部分，必備`|

> 使用無線開發板的話，銅柱部分要自行調整高度，取決你的**電池擺放在哪裡**還有**電池厚度**。

> 相比 v1，v2 的機構元件被我省去了很多，方便收集材料及安裝。

## B. 注意事項 (Cautions)

## C. 組裝步驟 (Building Guide)

> v2 版本基本跟 v1 的安裝方式一樣，下方會列出**不一樣**的地方。

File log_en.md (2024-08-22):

# Changelog

## The Cause

I myself have been taking a break for about a year due to an eye disease, and it's been a long time since I made my last keyboard, the Prime52. In July 2024, I was chatting in the 鍵人谷 group and suddenly wanted to try my hand at a simple keyboard, so I thought of using the Plank as a model, and I didn't really think too much about it, and that's how I started this project.

Although I was still spat at: ‘ Is it really simple board?

## Dual-sided footprint

footprint

It is said to be based on Plank, but it is not a solution for me to look at the MX switches cans in front of my desk every day, because I have been using the low profile ones for a while, and I can't change them back. One day, when I started to open KiCAD to edit my personal Library and footprint database, I drew this Choc and GLP low profile double sided board support footprint.

I didn't think it would look so good, so I added it to my schematic and PCB design, and the keyboard PCB slowly took shape.

## Outlet

I've been studying the MCU and TRRS jacks to see how the direction of the jacks corresponds to the position of the device. At first I was thinking of following the popular design - MCU in between the hands, USB port facing forward, but then I saw someone in the X community (known as twitter) post a laptop configuration that made me change my mind. 

Seems like an unremarkable placement, but I thought it would be easier to have the USB ports on the outside of a laptop like this, with the TRRS jacks maintaining the front side of the cables... In other words, this is how I designed it from the beginning:



With a single right-side keyboard, the USB port is also on the right side, and the reverse is also true.

So I started the keyboard design according to the way the MCU is placed on the side, and drew my own double-sided MCU footprint on the double-sided PCB support, roughly following my own ideas. it was fine without drawing it, but after drawing it I realised that the footprint is quite perfect in terms of the wiring crossings, and that the MCU will only be moved by 2.54mm.



After designing the MCU, I found that placing it on its side would cause the keyboard to have a large area that was completely empty, so I thought about it for a while, and realised that I had an unused footprint of a Cirque 40mm touchpad in my database, and that's how the beybaord basically came into being.



## Trackpad

The first time I learnt about Cirque's trackpad was from Bastardkb's Dilemma, which also uses this 40mm trackpad, so I googled it from the Dilemma's github page, and found it on beekeeb. At that time, I only knew that this is sold here, then I really plan to buy 2 packs from here to test it with breadboard at home, here is the product after testing:



I also took measurements of the actual object and built a 3D model of it with Cirque's specification:




I really didn't expect so much attention to this humble keyboard, but I found out that it's the trackpad that's the reason. In fact, I really have no idea about this type of electronic parts, and I'm not a professional, I don't even know what type of communication method I2C and SPI are, I just know how to install it by looking at the installation method on the specification book.




Anyway, as long as you like it, and the low profile switches are slowly starting to be made by some manufacturers, and there are slowly more choices, so it's good that I've made this keyboard to share at this time.

Thank you all.

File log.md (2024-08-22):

# 開發日誌

## 起因

我本人因為眼疾的關係差不多休息了1年左右的時間，距離上一把鍵盤Prime52做好到現在也同樣過了許久。於是2024年的7月，在鍵人谷群組聊天時突然想試試手，做一把簡單的鍵盤練習，於是就想到用Plank作為範本進行製作，還真的沒有思考太多，也因為這樣，就這麼開始了這個計劃。

雖然還是被吐槽：你說簡單的鍵盤，真的很簡單嗎？

## 雙面矮軸footprint

footprint

說是以Plank為基礎，但我每天看著桌子前方的MX軸軸罐也不是辦法，因為自己用矮軸也用了一陣子，也無法切換回去，有一天我點開KiCAD整理我個人的Library跟footprint資料庫的時候，順手畫出了這個Choc及GLP矮軸雙面電路板支援的footprint。

我沒想到這個東西這麼好看，於是就這樣加在自己的原理圖及PCB設計裡，鍵盤PCB就慢慢地成型了。

## 出線口

MCU跟TRRS的出線口我一直有在研究，怎麼個出線方向對應到什麼設備的位置，一開始還是有想說要按照大眾的設計——MCU放置在雙手中間的位置、USB口朝前，但後來看到X社群（舊名twitter）中有人發佈了一個筆電的配置讓我全面改觀，它將筆電架高，分離式鍵盤分別在筆電的左右兩側。

看似毫不起眼的擺放方式，但我就覺得USB出線口要在外側比較方便類似筆電這樣的配置，TRRS座維持前方出線... 也就是說，我一開始的設計是這樣的：



單邊右側的鍵盤，USB出線口也在右側邊，反之亦然。

於是我就就根據MCU側放的方式，開始了鍵盤設計，在雙面電路板支援上大致參照了自己的想法，畫出了自己的雙面MCU footprint。沒畫還好，畫了之後才發現這個footprint在走線交錯上做的相當完美，而且MCU也只會偏移2.54mm。



MCU設計好後發現側放會導致鍵盤會出現一個佔比很大的區塊是完全空白，於是我想了一下，想到我的資料庫中有個之前畫好沒用上的Cirque 40mm觸控板的footprint，就這樣探索者3號就基本成型了。



## 觸控板

第一次認識Cirque家的觸控板是在Bastardkb家的Dilemma，它同樣也是使用這款40mm的觸控板，於是我從Dilemma的github頁用google搜尋，就這麼查到beekeeb上。當時的我只知道這裡有在賣這個，後來就真的計劃先從這裡先買2組回家來用麵包板測試，下面就是測試過後的產物：



也實際拿著到手的實體進行測量，並且搭配Cirque的規格書把它的3D模型建立起來：




我是真的沒想到會這麼多人關注這把不起眼的鍵盤，但後來得知是這塊觸控板的關係。其實我對這類型的電子零件還真的沒轍，也不是專業，我甚至不知道I2C跟SPI是什麼類型的通信方式，只知道看著規格書上的安裝方式安裝。




反正大家喜歡就好，而且矮軸也慢慢的有廠家開始做起來、選擇也慢慢多了，剛好這個節骨眼我把這把鍵盤做出來分享。

謝謝大家。

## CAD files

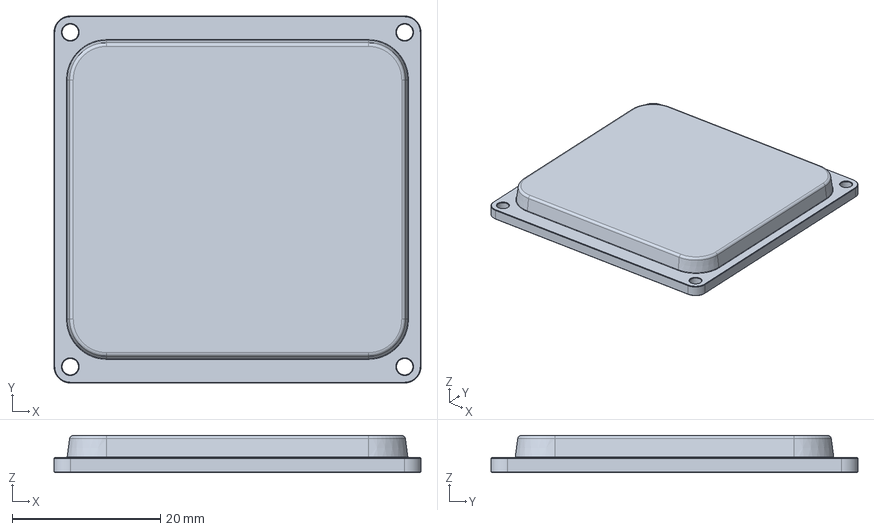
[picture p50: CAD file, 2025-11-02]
file/3d/TPS-tapcover.step
49.5 x 49.5 x 5.00 mm

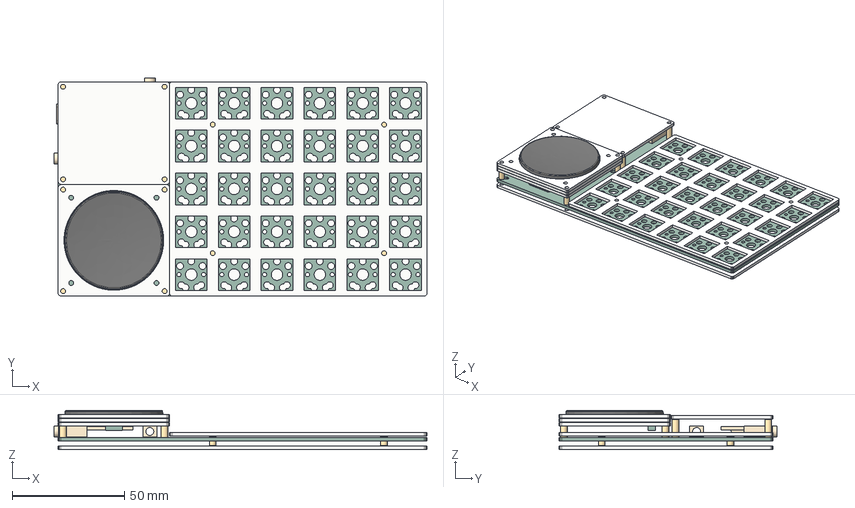
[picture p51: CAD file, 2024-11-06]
file/3d/v1/blank-p_5x6.step
165.8 x 96.9 x 17.3 mm
TPS PCB
TPS PCB_1
TPS PCB_2
TM040040
Elite-C
TRRS x 2
TPS PCB_3
TPS PCB_4
TPS PCB_5
_autosave-TPS PCB
4mm x 4
8mm x 4
5mm x 4

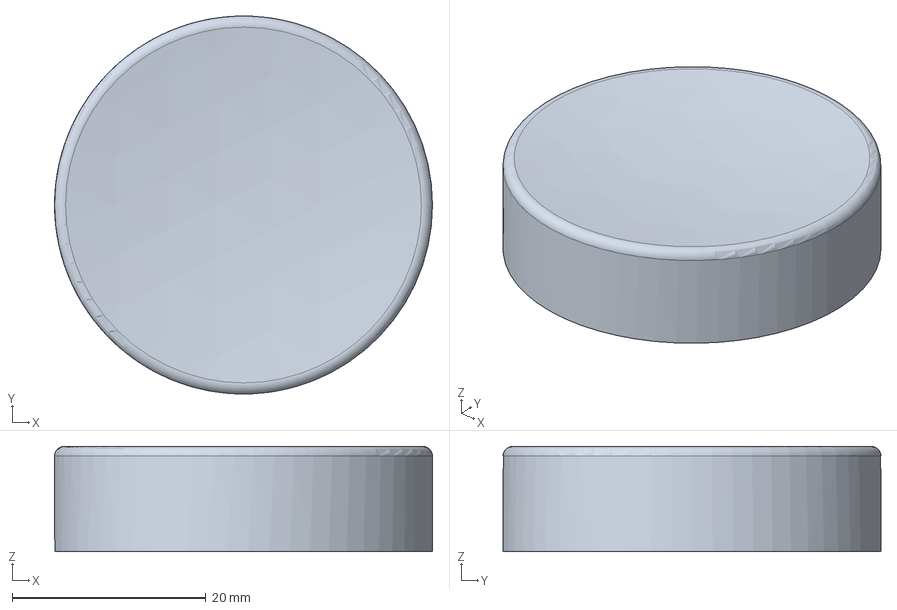
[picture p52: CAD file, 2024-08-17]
file/3d/39mm_h4.5mm_ec11_hat.step
39.0 x 39.0 x 10.8 mm

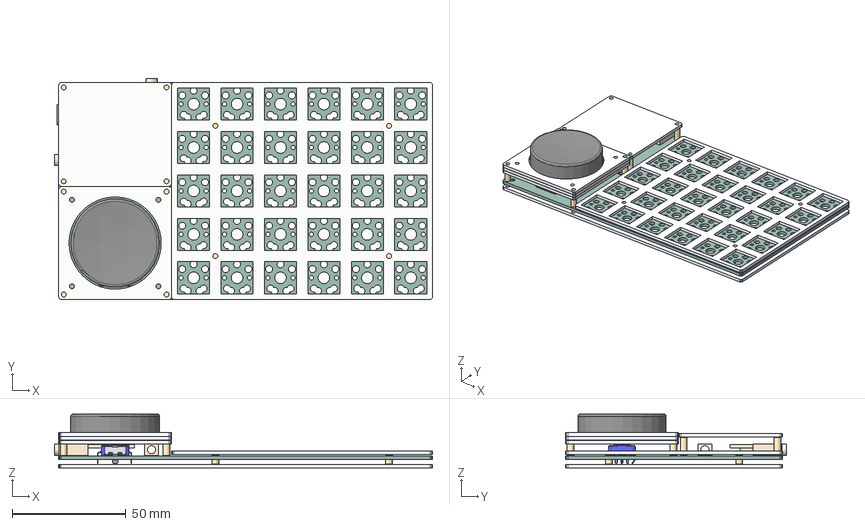
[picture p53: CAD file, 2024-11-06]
file/3d/v1/blank-e_5x6.step
165.8 x 96.9 x 23.6 mm
38mm EC-hat
TPS PCB
TPS PCB_1
TPS PCB_2
Elite-C
TRRS x 2
TPS PCB_3
TPS PCB_4
TPS PCB_5
_autosave-TPS PCB
4mm x 4
8mm x 4
5mm x 4

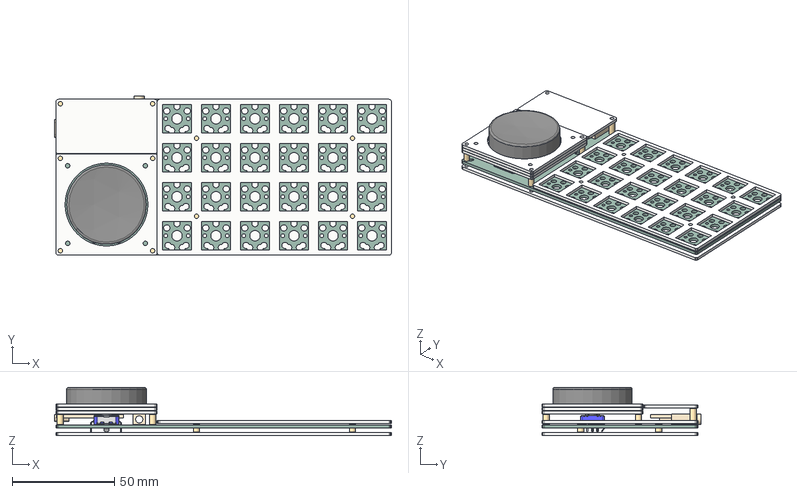
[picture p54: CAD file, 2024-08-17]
file/3d/v1/blank-e_4x6.step
164.6 x 77.9 x 23.6 mm
Elite-C
TRRS
TPS PCB
EC11/12: TH14.5-15.0mm
TPS PCB_1
TPS PCB_2
TPS PCB_3
TPS PCB_4
4mm x 4
8mm x 2
5mm x 4
TPS PCB_5
TPS PCB_6
38mm EC-hat

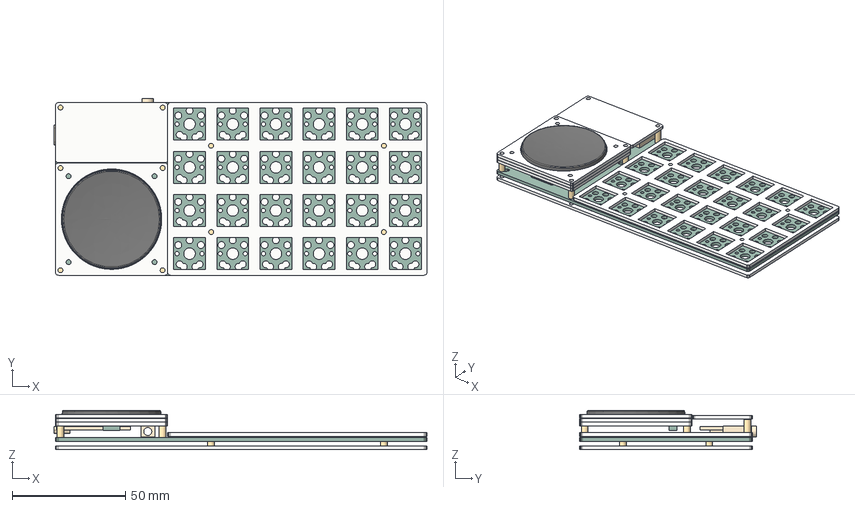
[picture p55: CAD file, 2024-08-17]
file/3d/v1/blank-p_4x6.step
164.6 x 77.9 x 17.3 mm
Elite-C
TRRS
TPS PCB
TPS PCB_1
TPS PCB_2
TPS PCB_3
TM040040
TPS PCB_4
4mm x 4
8mm x 2
5mm x 4
TPS PCB_5
TPS PCB_6

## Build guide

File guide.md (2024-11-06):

# 組裝環節

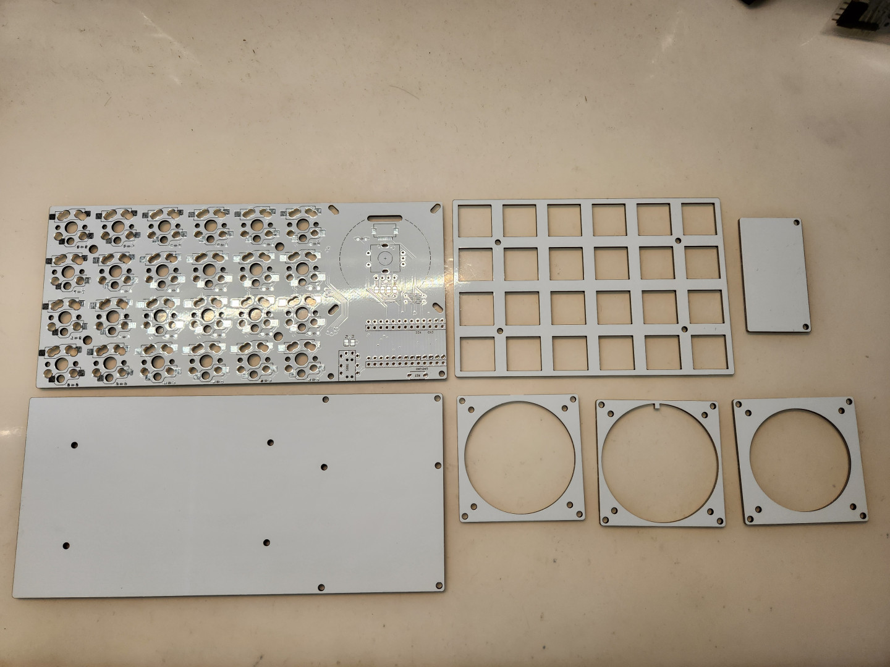
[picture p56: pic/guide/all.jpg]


## 基本安裝順序

### 二極體

1N4148是機械鍵盤上最常使用到的二極體元件，有分為`SMD`貼片式及`THT`直插式，這裡我們使用到的為貼片式，方向對應如下圖：

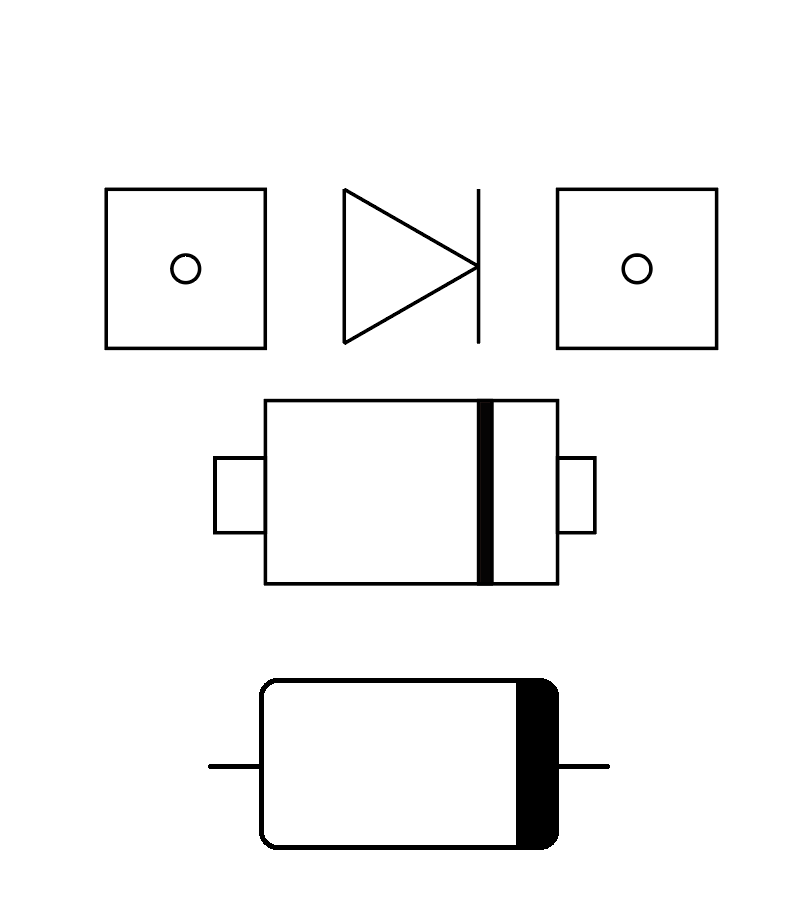
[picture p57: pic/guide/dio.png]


貼片式二極體相當的微小，需要用鑷子稍微轉動光線才會將它方向展示出來，我們首先的第一步就是將二極體安裝在鍵盤上頭合計`25個`位置上：

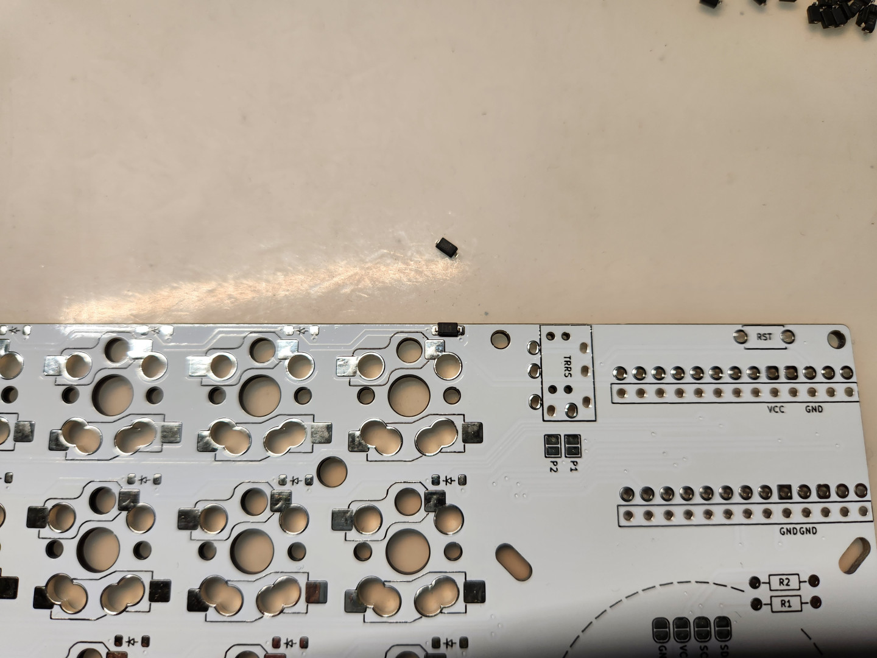
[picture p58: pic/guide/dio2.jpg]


### 熱插拔座

二極體固定完成後再來焊接固定熱插拔座：

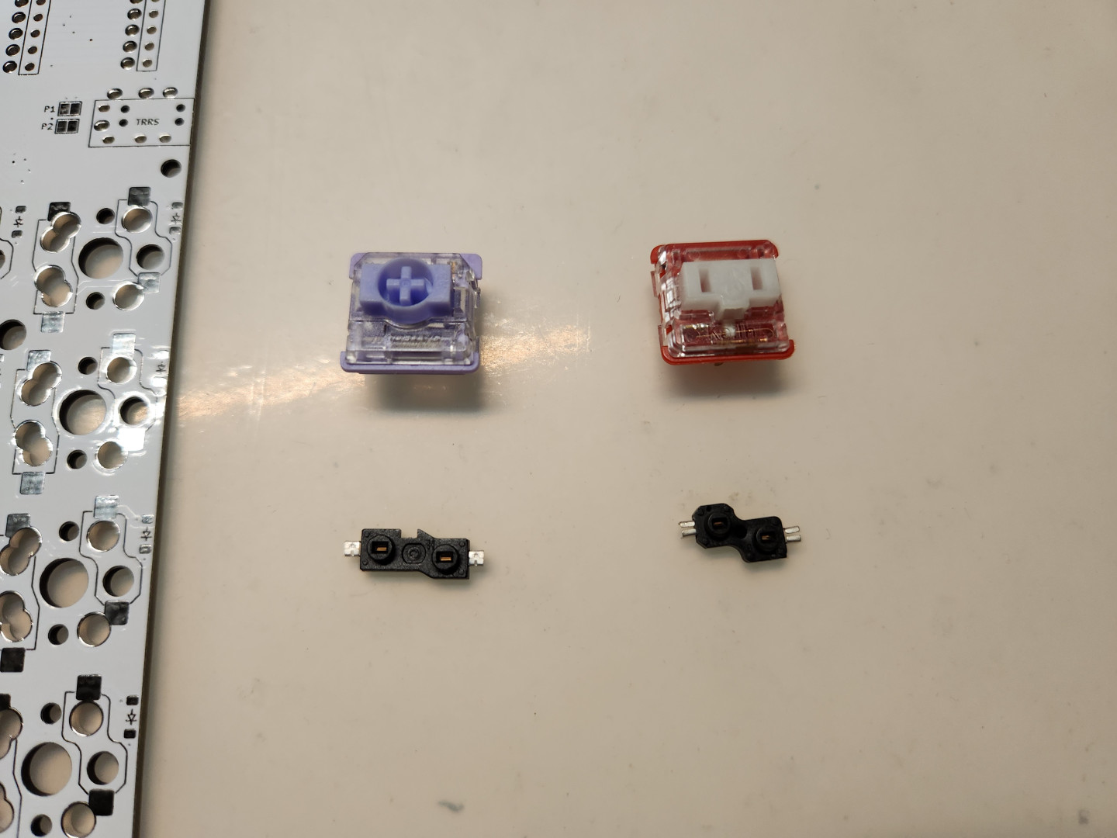
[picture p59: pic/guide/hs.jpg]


探索者3號支援的熱插拔座有`Choc`及`GLP`兩種版本，擇一安裝即可，對應的腳位如下圖：

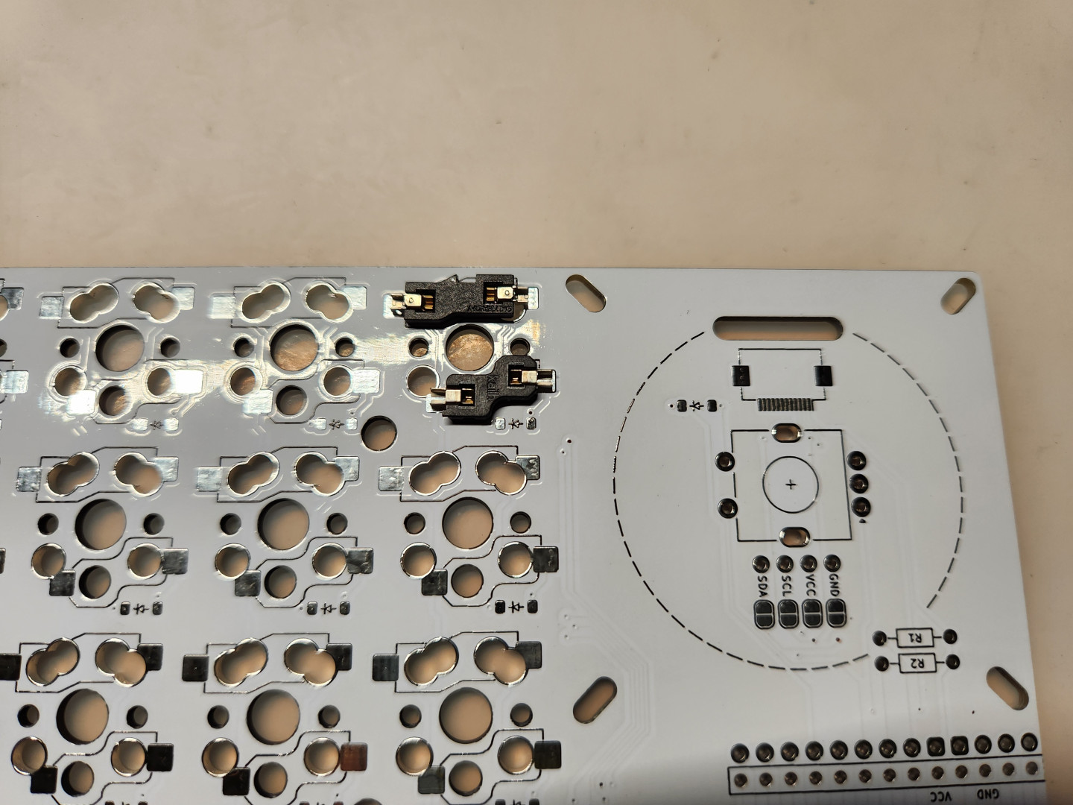
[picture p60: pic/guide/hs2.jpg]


安裝完將TRRS下方的跳線`P1`連接起來：

- `P1`為預設的TRRS的電源連接方案，ATMega32U4 ProMicro及RP2040 ProMicro基本都是使用這個方案。

> 若RP2040 ProMicro出現左右兩側鍵盤上的`通信問題`，請將`P1`上的焊錫移除後改至`P2`再做通信測試。

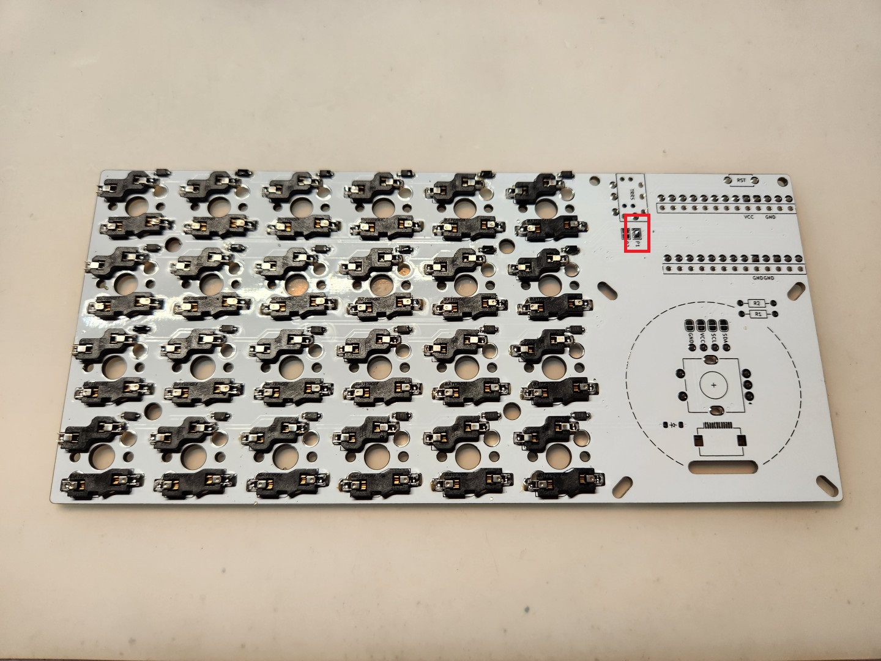
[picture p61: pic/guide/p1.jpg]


### MCU

接著將MCU依照電路板上的標示框及上頭的`VCC`、`GND`對應、晶片面朝下安裝。

> 排針可選擇直插式或可插拔的款式，為了方便測試因此照片示意圖會是可插拔的版本，大家參考一下即可。

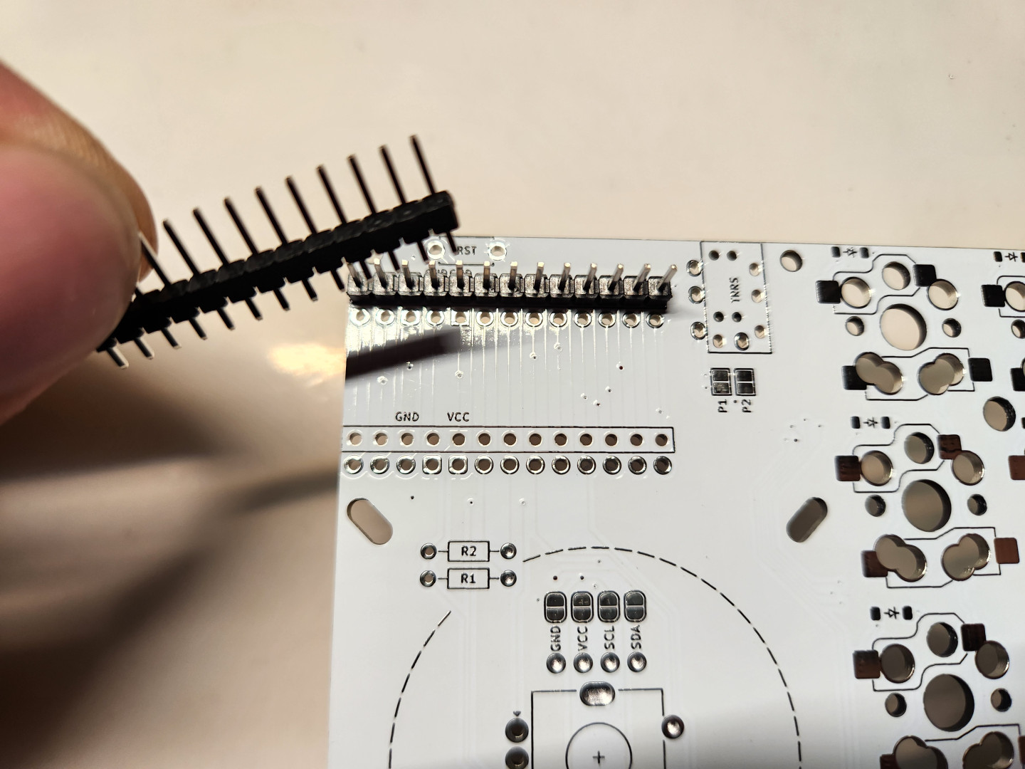
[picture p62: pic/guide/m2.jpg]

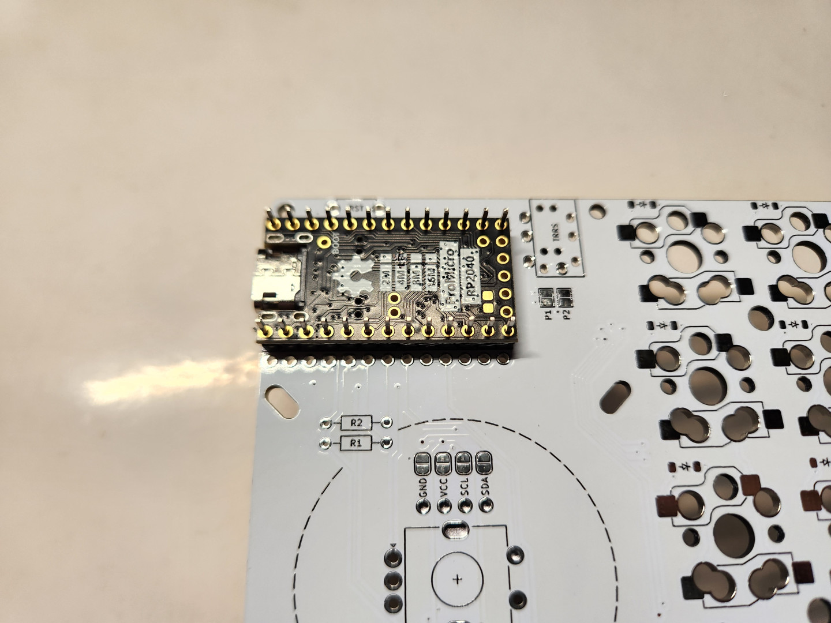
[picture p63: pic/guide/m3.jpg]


> 可插拔排針母座安裝示意圖。

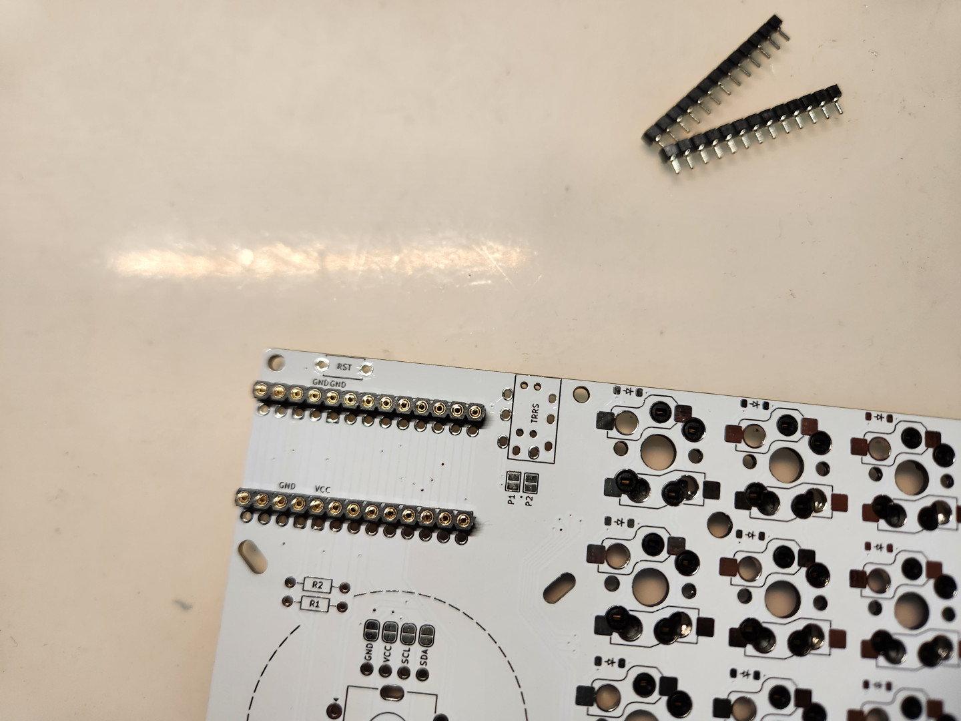
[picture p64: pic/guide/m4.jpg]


下一步將`TRRS座`及`2pin輕觸開關`安裝上去（只需安裝單邊鍵盤的話不用安裝TRRS座）。

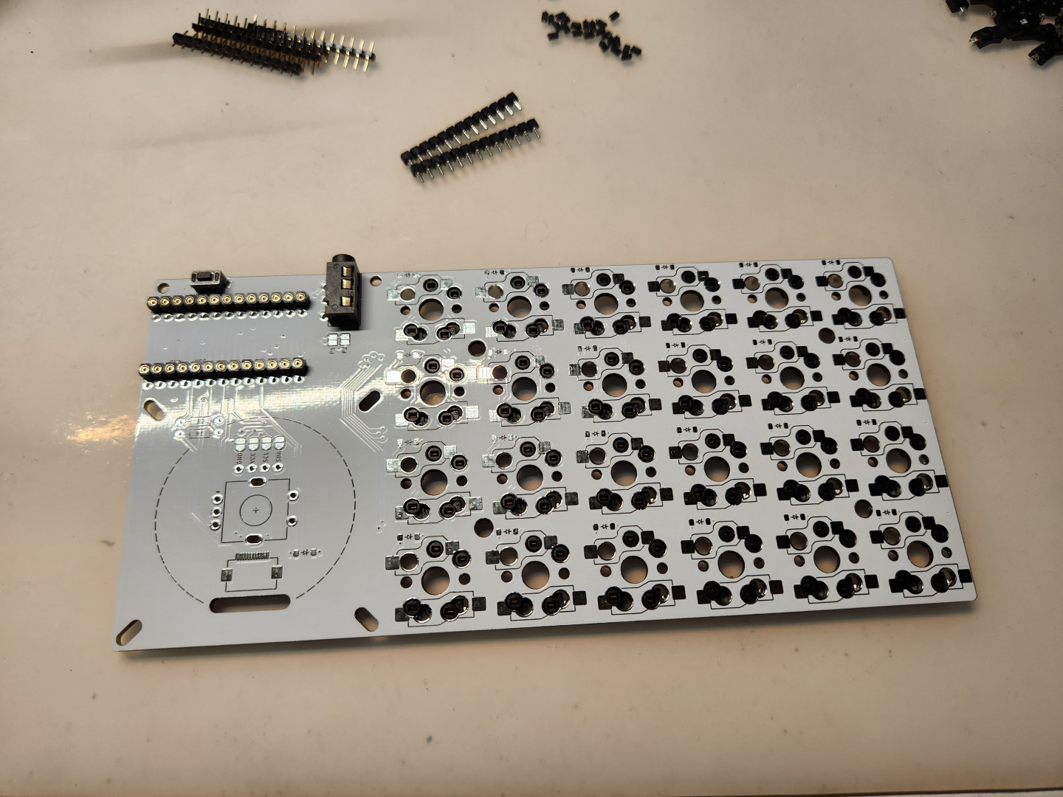
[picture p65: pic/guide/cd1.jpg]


## Cirque 40mm觸控板模組

- 請務必將beekeeb及Keycapsss的組裝流程看過一輪，下面會統合兩篇文章的資訊：

    - [Cirque Trackpad i2c on Corne Keyboard Build Log](https://beekeeb.com/cirque-trackpad-i2c-on-corne-keyboard/)。
    - [GlidePoint Cirque Trackpad with Adapter PCB](https://keycapsss.com/help/cirque-trackpad/#spi-or-i2c)。

為了設計這把鍵盤我才會從網路通路上購入觸控板模組的拓展包來使用，接著再額外購入FFC連接座來安裝鍵盤。

- 鍵盤的結構參考beekeeb及bastardkb鍵盤[Dilemma](https://docs.bastardkb.com/bg_dilemma/v2.html)設計，FFC連接座會固定在電路板背面，跟熱插拔座在同一面（請看下圖照片對比）。
- 使用上面提及的兩篇文章來安裝拓展模組，使用銅柱長度會需要調整。
- 探索者3號使用`I2C`模式連接觸控板。

> 結構安裝照片來自beekeeb：



> 鍵盤安裝完成後側面的結構：

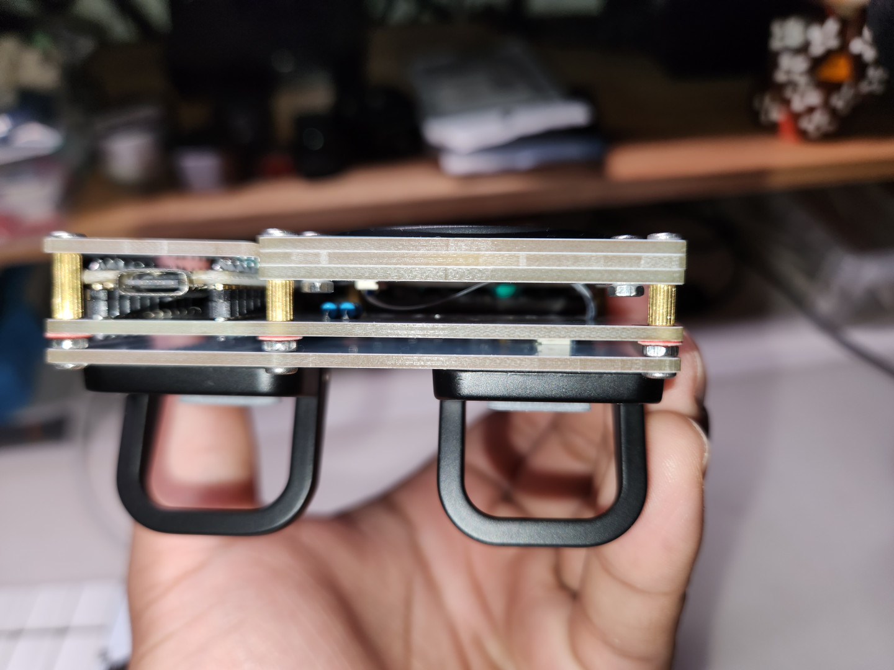
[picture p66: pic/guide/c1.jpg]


以下是beekeeb及Keypasss兩篇拓展板文章的統合資訊：

- `I2C`模式下需要更動的觸控板元件及需要安裝的元件：

|MCU|IC|VCC|R1電阻|R7電阻|R8電阻|4.7K上拉電阻|
|--|--|--|--|--|--|--|
|ProMicro|ATMega32U4|5V|移除|移除|移除|加裝|
|ProMicro|RP2040|3V3|移除|-|-|加裝|

> 觸控板照片來自Keycapsss：



### 加裝FFC連接座

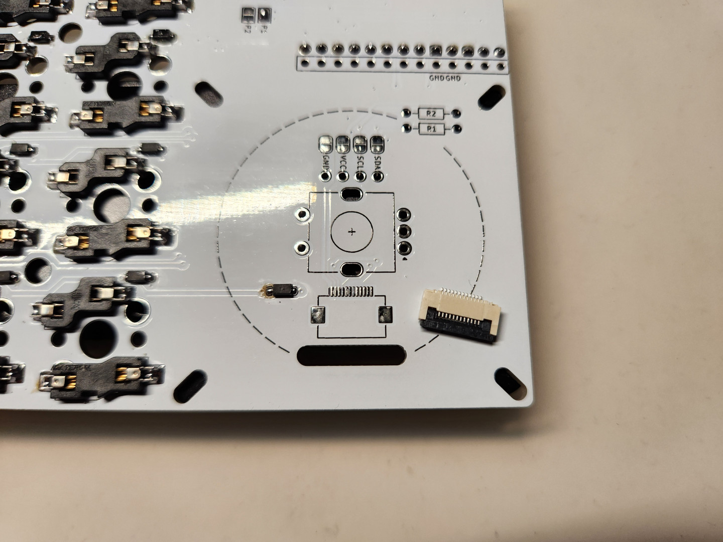
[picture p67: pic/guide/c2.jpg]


使用電烙鐵焊接軟排線連接座相當困難，這裡會推薦使用加熱台或熱風槍將其用焊錫、錫漿固定在電路板上。

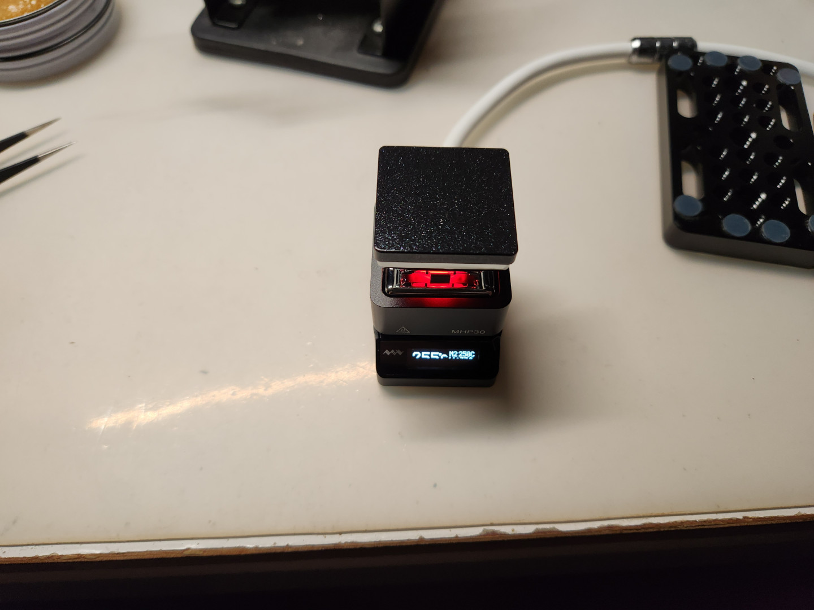
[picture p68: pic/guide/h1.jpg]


> 這裡特別留意會需要刷上一定量的`助焊劑`給加熱台做使用。

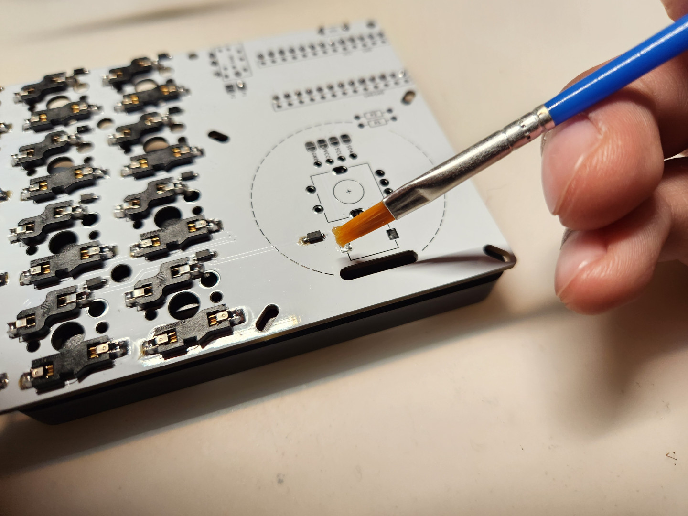
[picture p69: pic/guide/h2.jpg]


FFC連接座完成固定後，再將軟排線安裝固定上去。

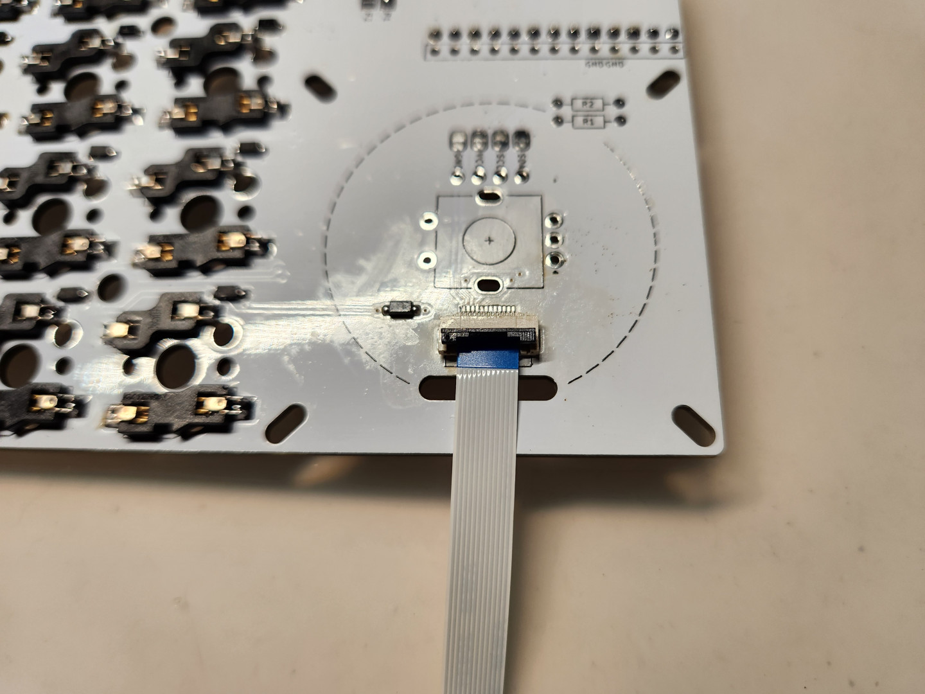
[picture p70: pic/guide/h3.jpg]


卡榫固定好後將排線穿過下方的洞口至另一側。

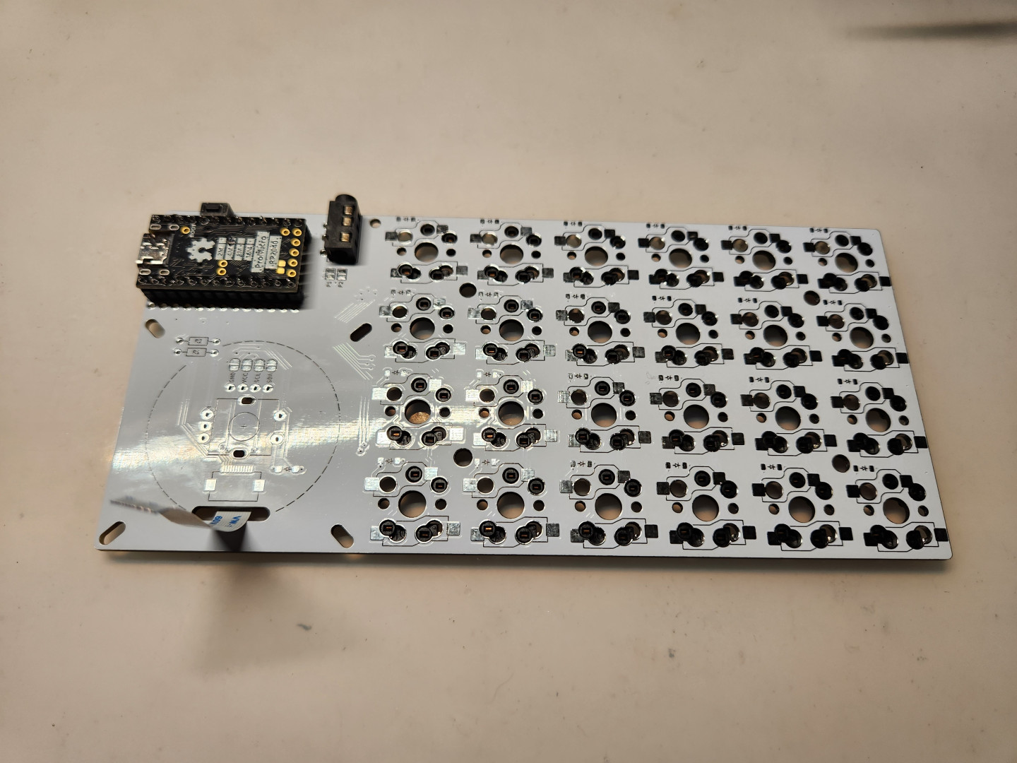
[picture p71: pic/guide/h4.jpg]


### 上拉電阻

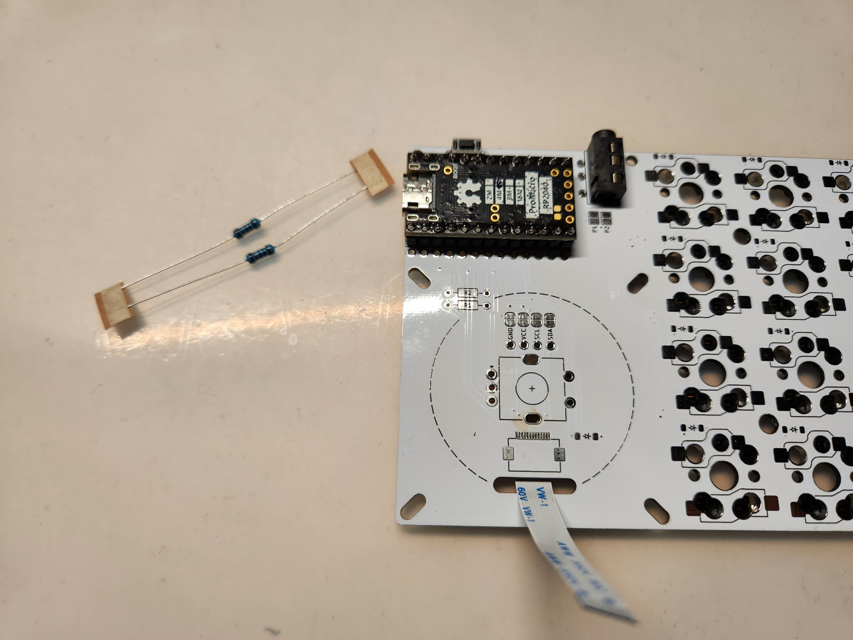
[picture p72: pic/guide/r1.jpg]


上拉電阻的部分很簡單，把針腳稍微彎折一下，插入R1、R2上對應的焊盤孔中，用焊錫固定好，多餘的針腳移除掉即可。

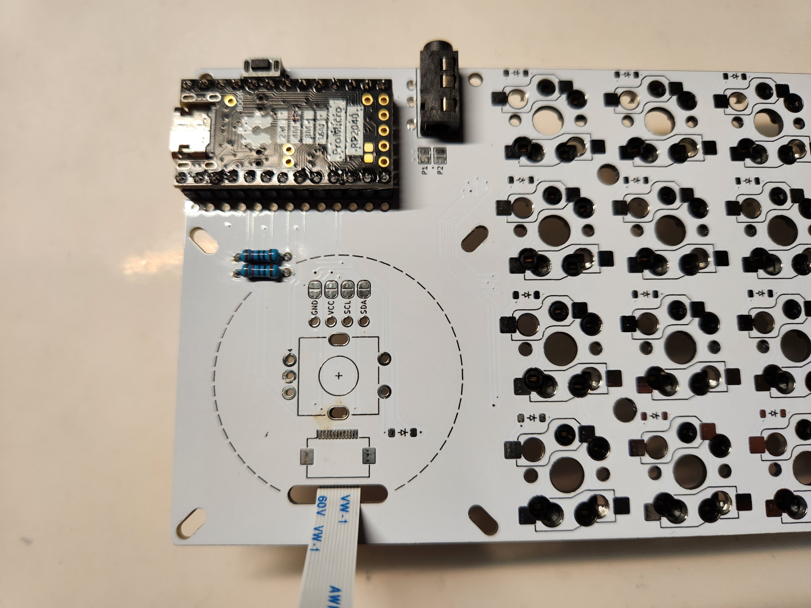
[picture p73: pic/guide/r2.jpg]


### FFC連接座拓展板

- 安裝拓展板時的注意事項：

    - 安裝前需將鍵盤電路板正面的I2C`跳線`都接通才可正常使用（下圖所示）。
    - FFC連接座拓展板為網路通路商所開發讓使用者自由安裝的插件模組，安裝方式參照該通路商的安裝說明文章。
    - 使用拓展板會增加該安裝位置的厚度，因此需要自行調整`銅柱的高度`。

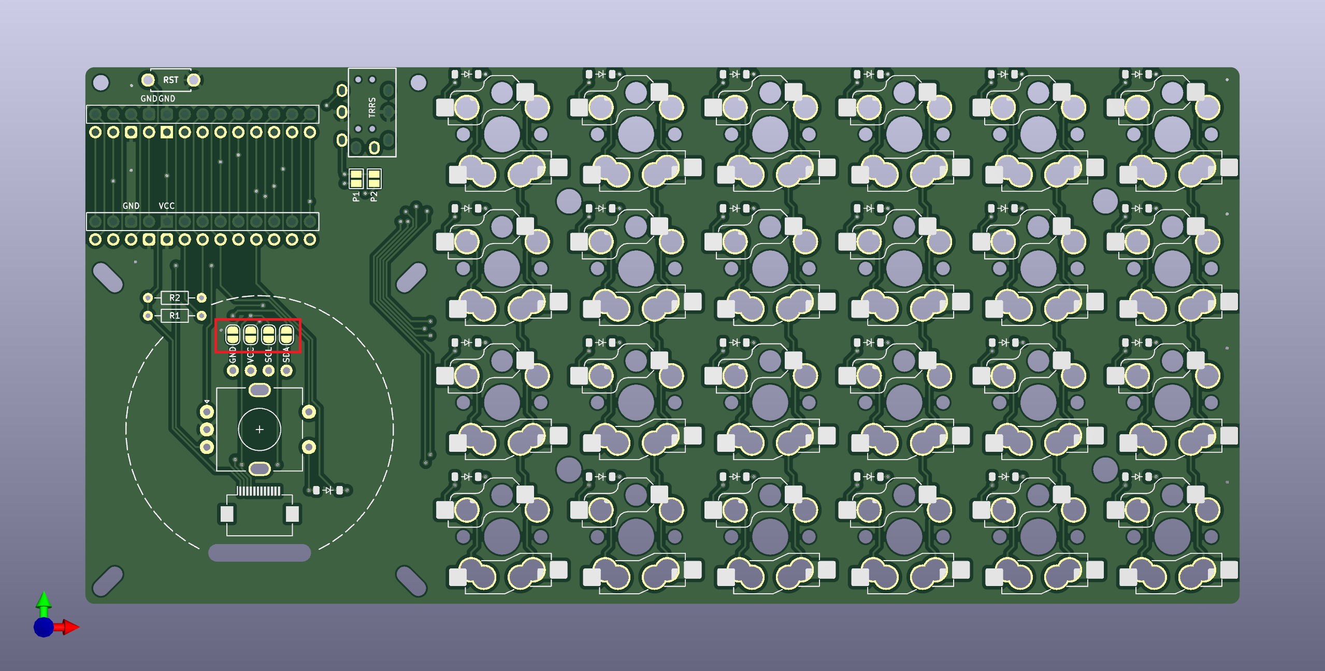
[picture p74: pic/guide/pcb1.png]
pcb1


### 擋板組合

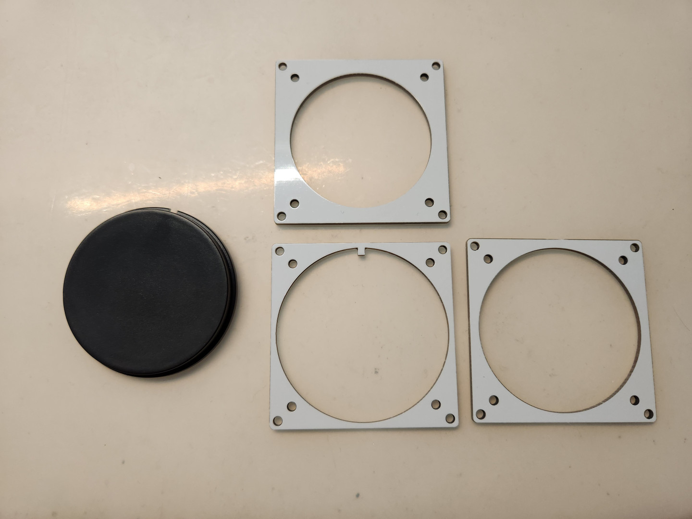
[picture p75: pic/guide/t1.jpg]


觸控板上的電阻移除後，將觸控板本體及3片擋板組合在一起。首先，擋板`A`、`C`的洞口直徑不太一樣，視安裝的元件不同，擋板上下的順序也不同。

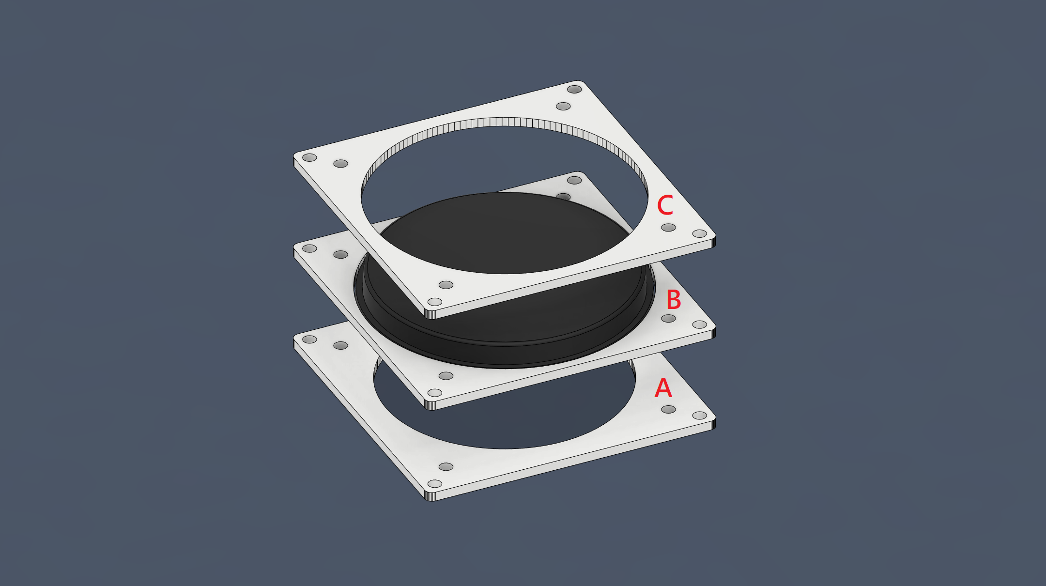
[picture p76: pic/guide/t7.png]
t7


接著將`A`、`B`兩者對齊平放。

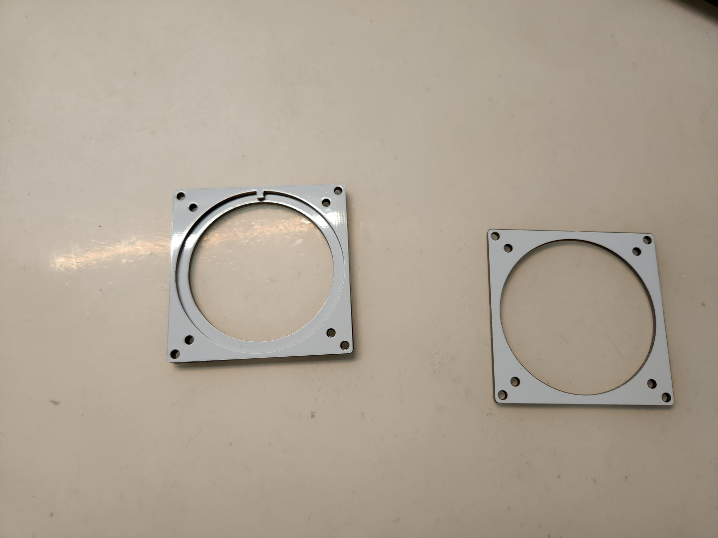
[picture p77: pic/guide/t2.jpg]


再來將觸控板本體放在中間，有防呆卡榫，不用擔心安裝失誤。

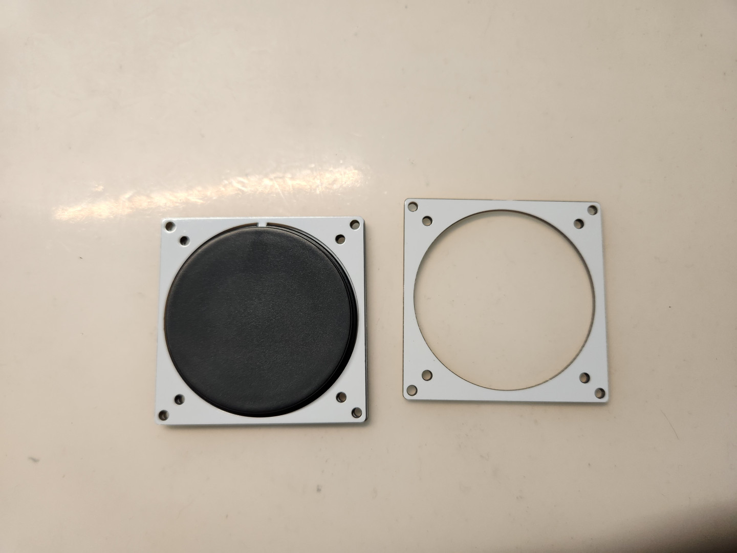
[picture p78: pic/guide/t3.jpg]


然後將`C`板疊在一起。

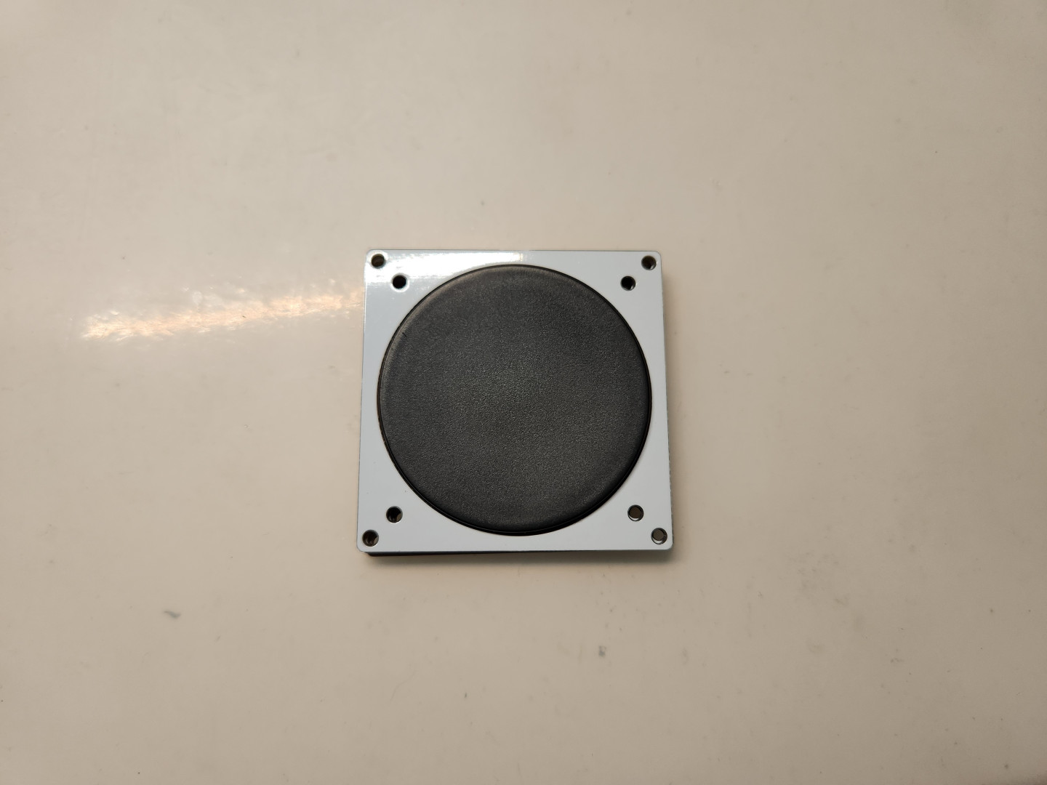
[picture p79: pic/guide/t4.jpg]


最後再用`6mm螺絲`跟`螺母`將板子固定起來。

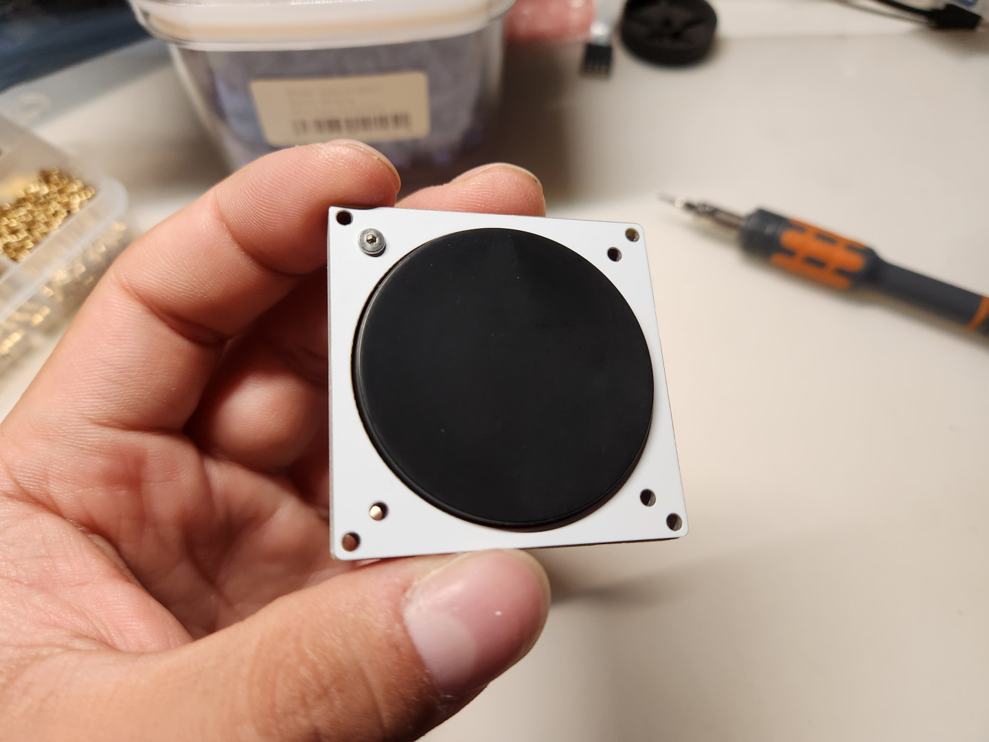
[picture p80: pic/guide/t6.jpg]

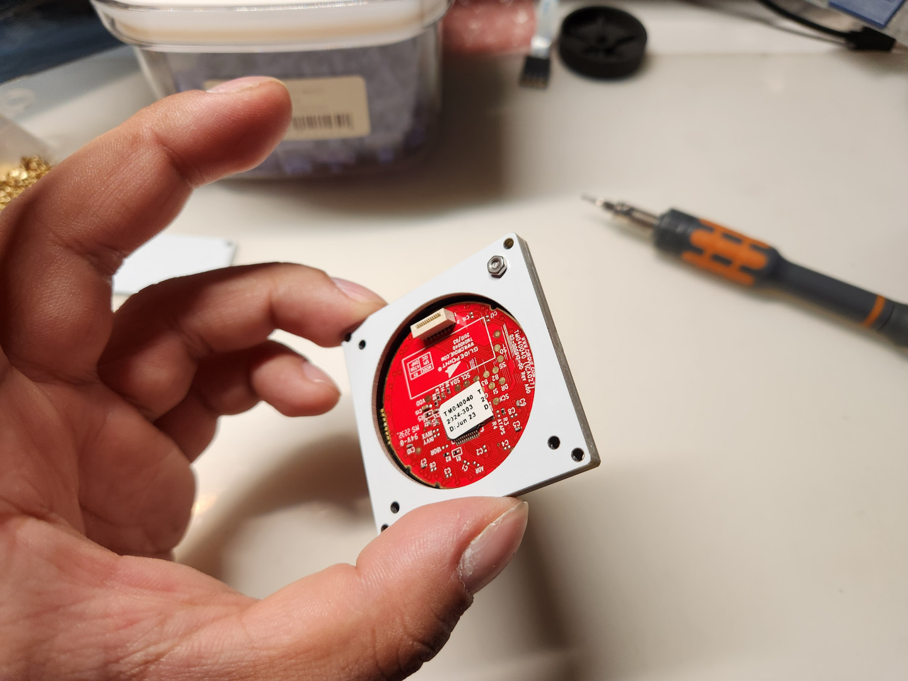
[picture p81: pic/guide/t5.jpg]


## 旋鈕編碼器

旋鈕編碼器的部分安裝相對簡單，按照對應的針腳位置安裝上去、再用焊錫固定起來即可。

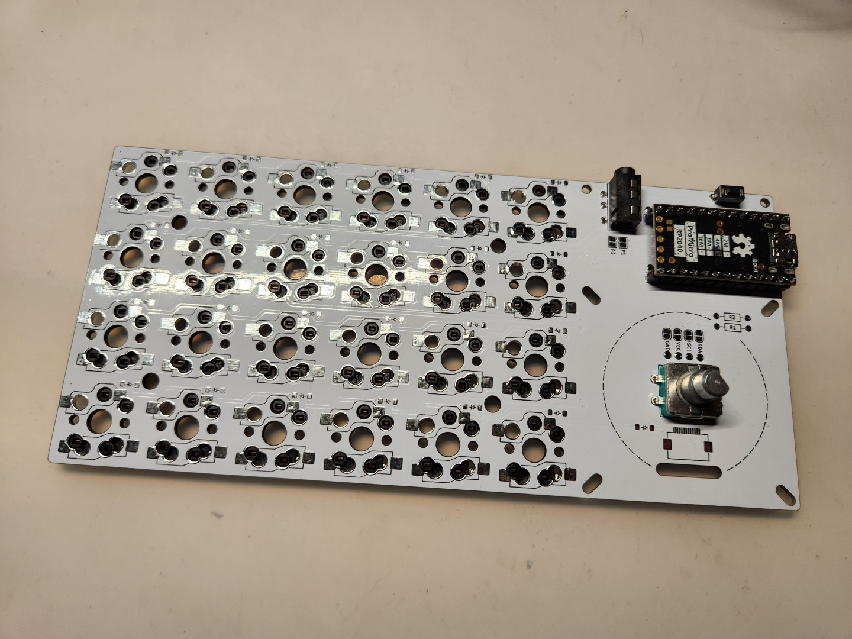
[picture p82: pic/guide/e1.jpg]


## 外殼

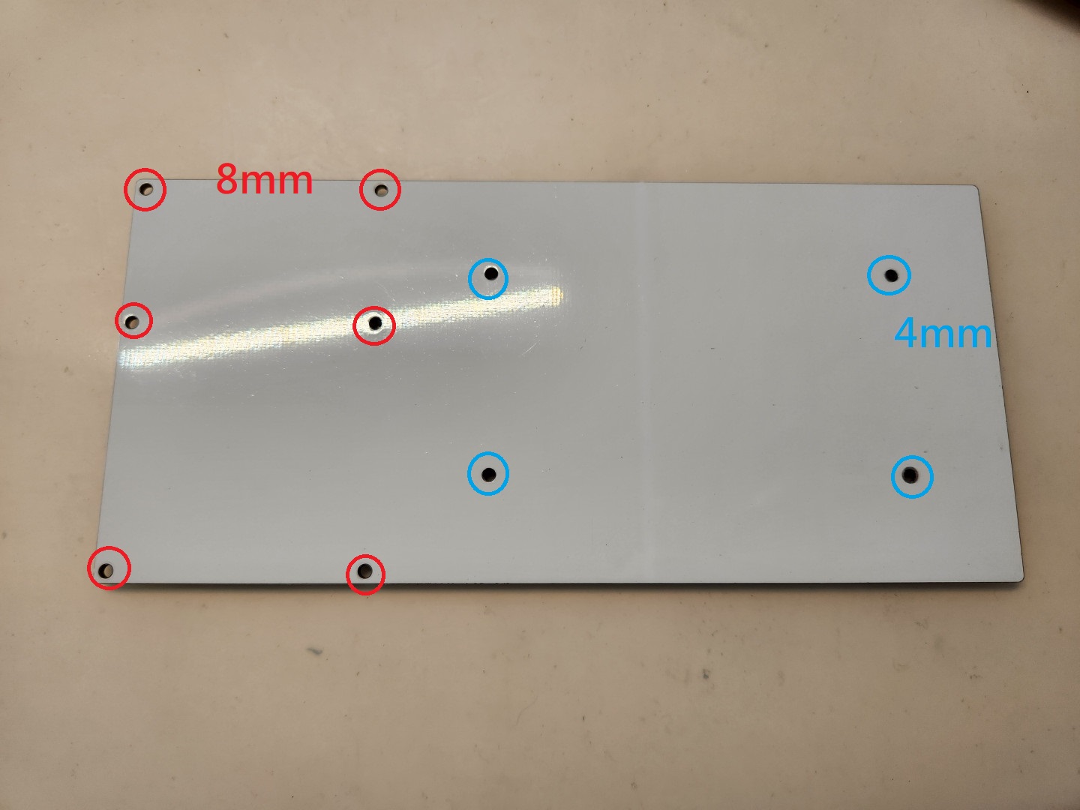
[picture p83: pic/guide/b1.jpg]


底板的部分會按照圖中標示的位置使用上相應長度的螺絲，安裝順序接著會來說明。

首先8mm螺絲的部分會使用螺母先固定好。

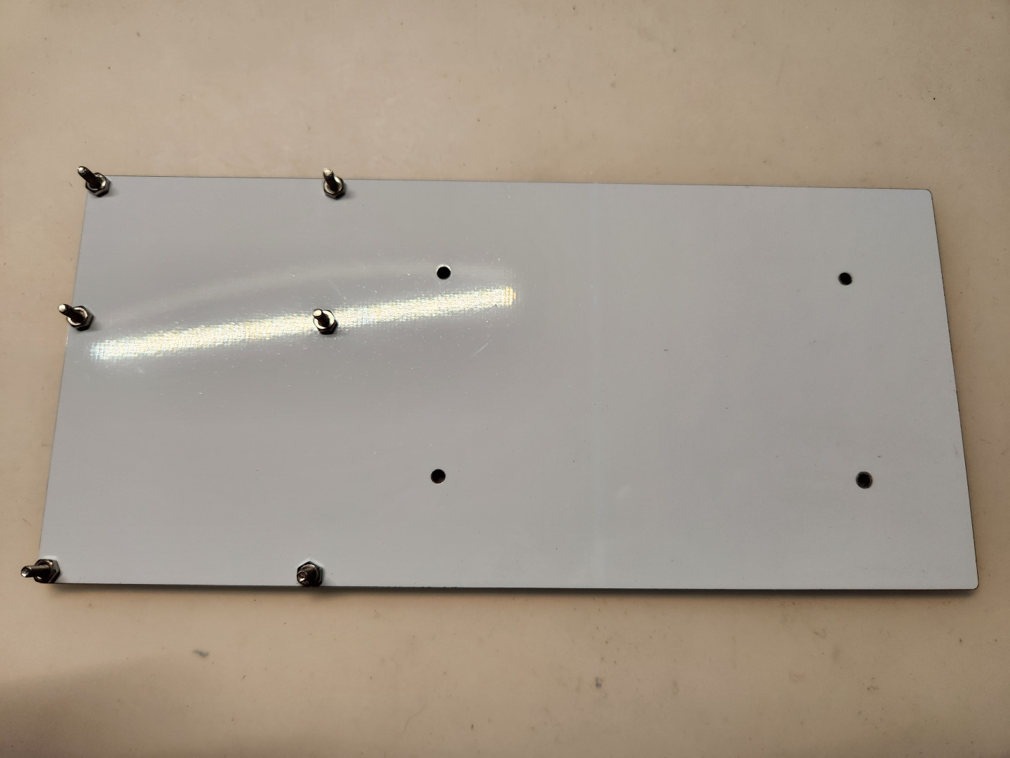
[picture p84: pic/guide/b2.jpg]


`4mm螺絲`跟`5mm銅柱`固定在一起。

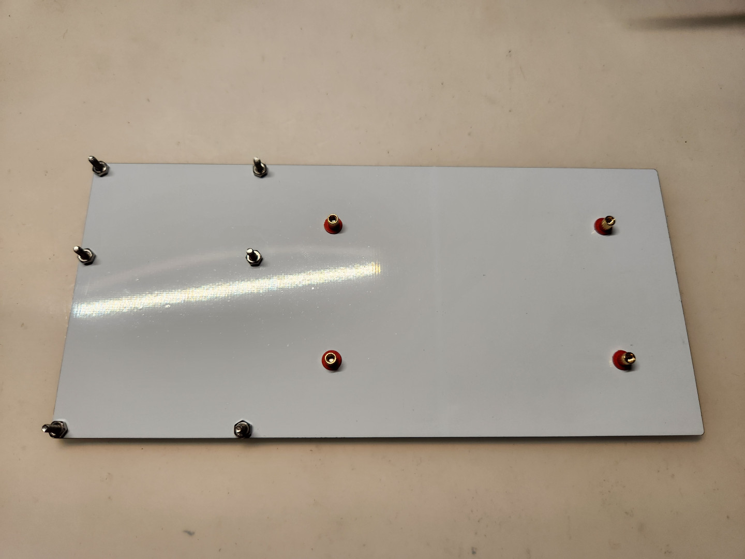
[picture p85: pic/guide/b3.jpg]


接著在螺絲上頭安裝墊片後，暫且放置在一邊，待會會用到。

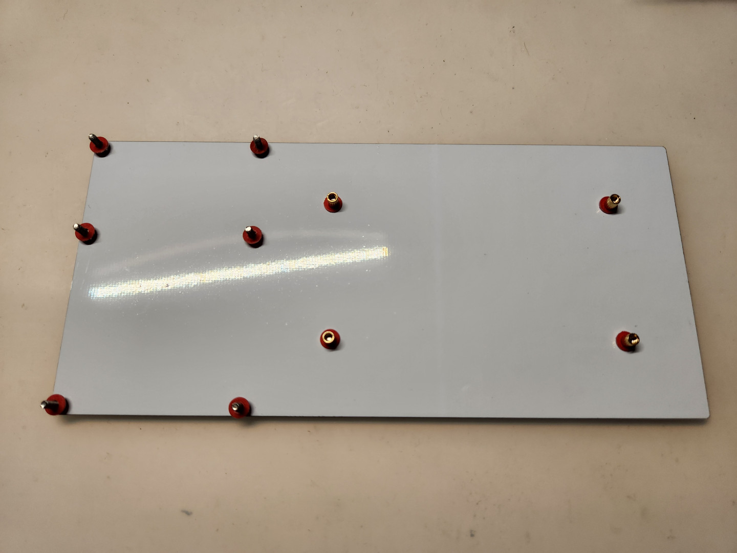
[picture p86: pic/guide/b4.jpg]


## 最後組裝

不管選配的部分為觸控板還是旋鈕編碼器，最後的安裝方式基本一樣。

### 觸控板

首先是搭載觸控板的部分，將電路板對應底板輕放上去，並依照圖中標示安裝對應長度的銅柱。

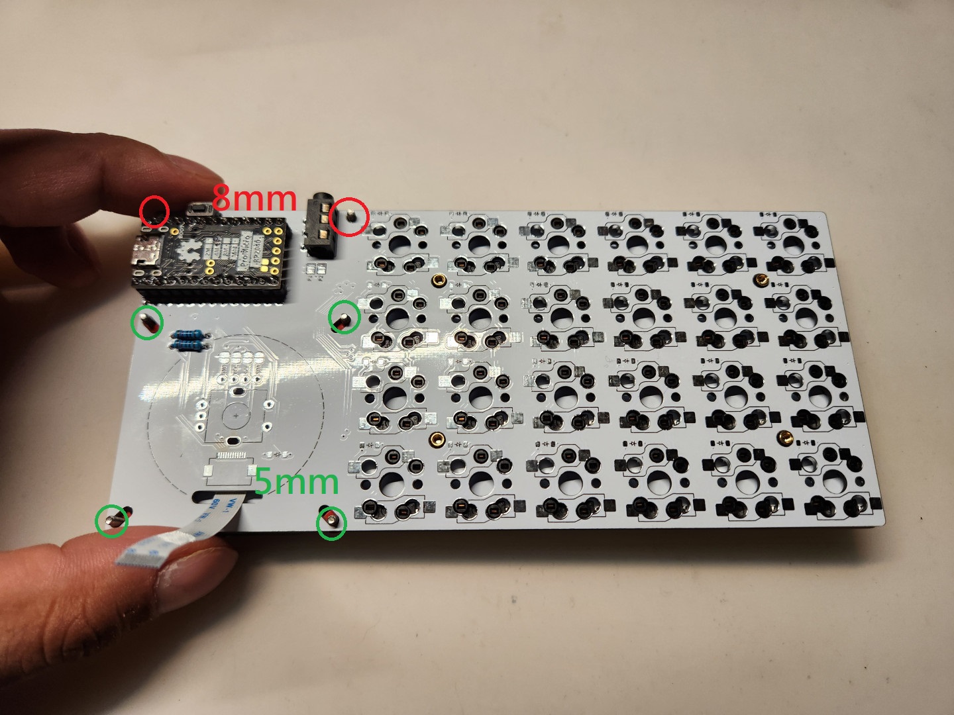
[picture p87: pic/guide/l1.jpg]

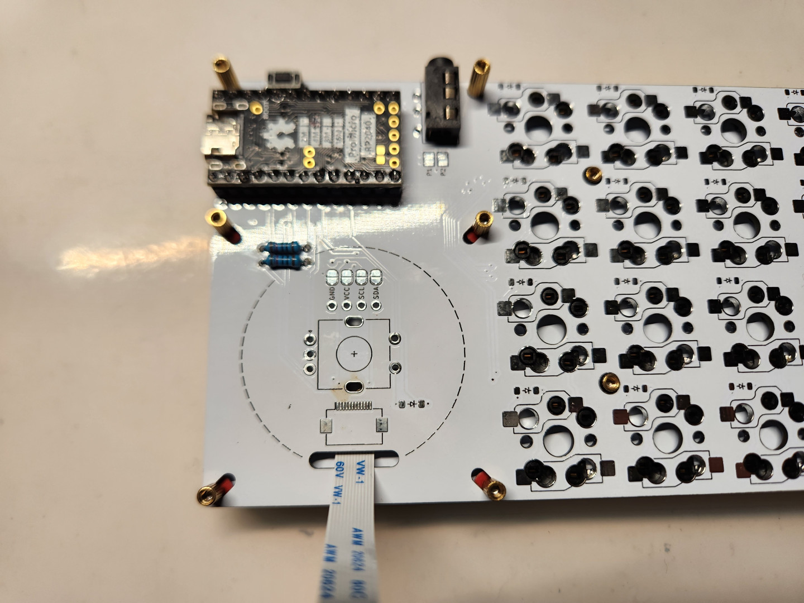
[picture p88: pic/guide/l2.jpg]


接著將軟排線接在觸控板上的FFC插槽內，並順著排線方向將擋板對好螺絲孔，用`6mm螺絲`固定起來。

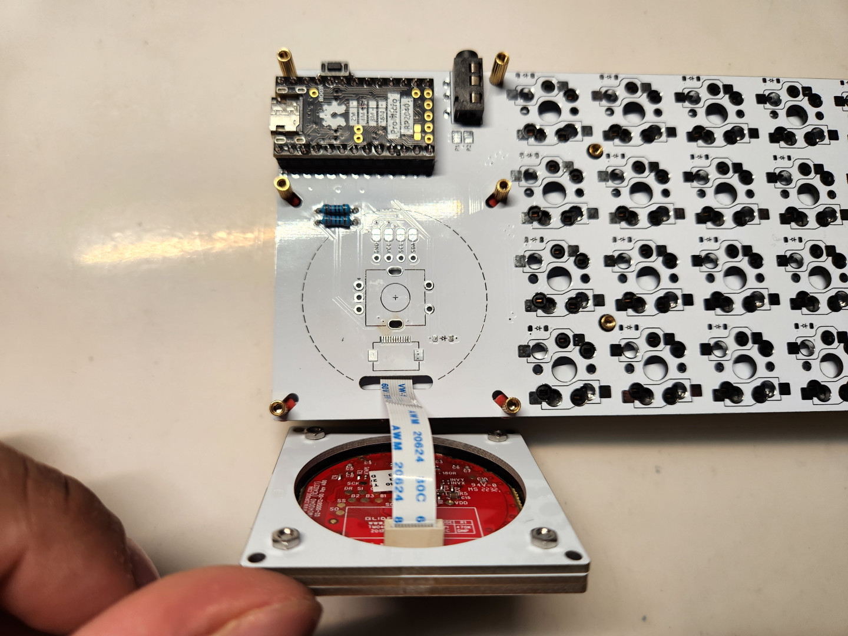
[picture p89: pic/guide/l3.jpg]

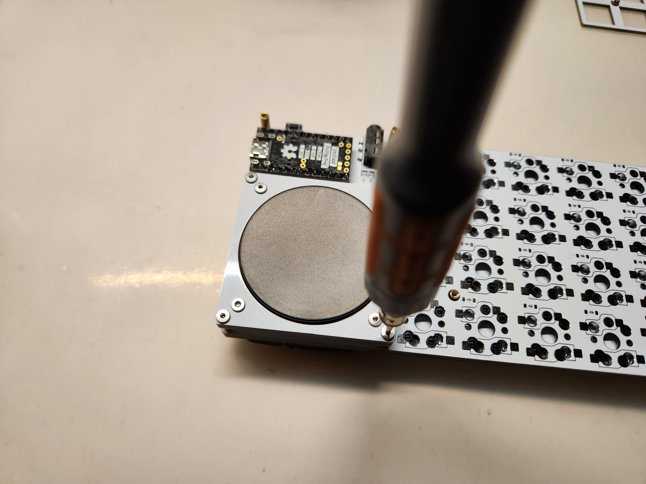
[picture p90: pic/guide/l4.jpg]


最後依序將定位板、MCU擋板用`3mm螺絲`鎖上。

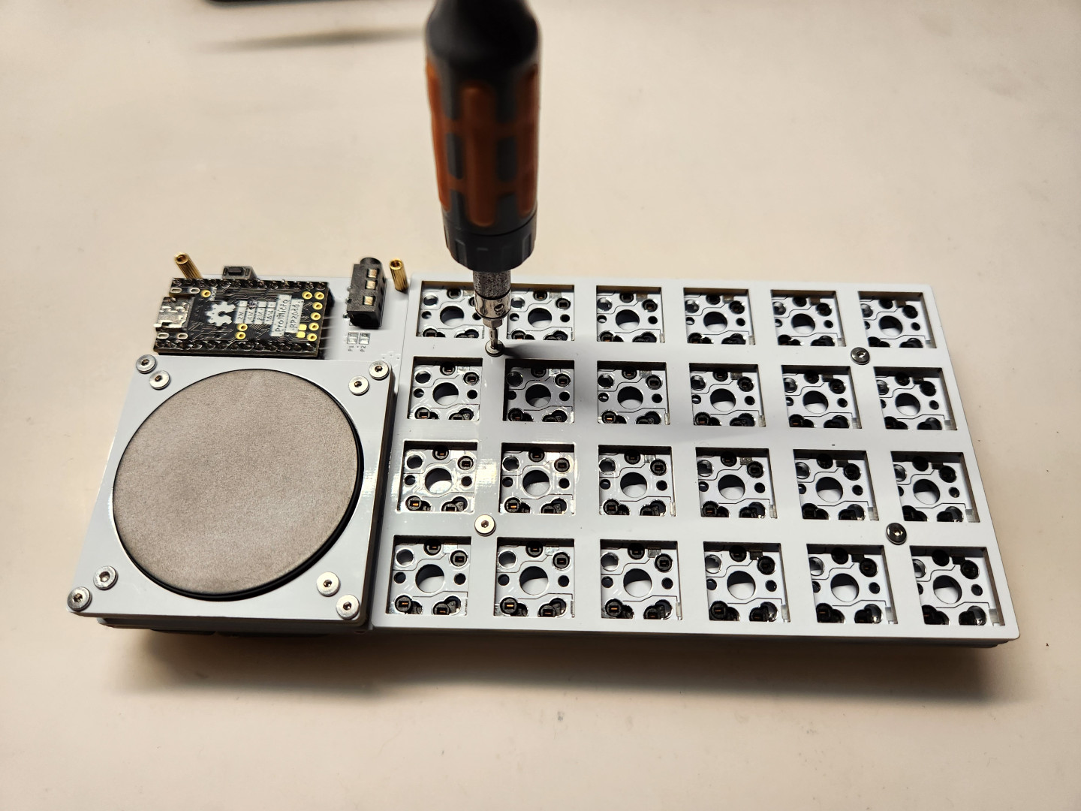
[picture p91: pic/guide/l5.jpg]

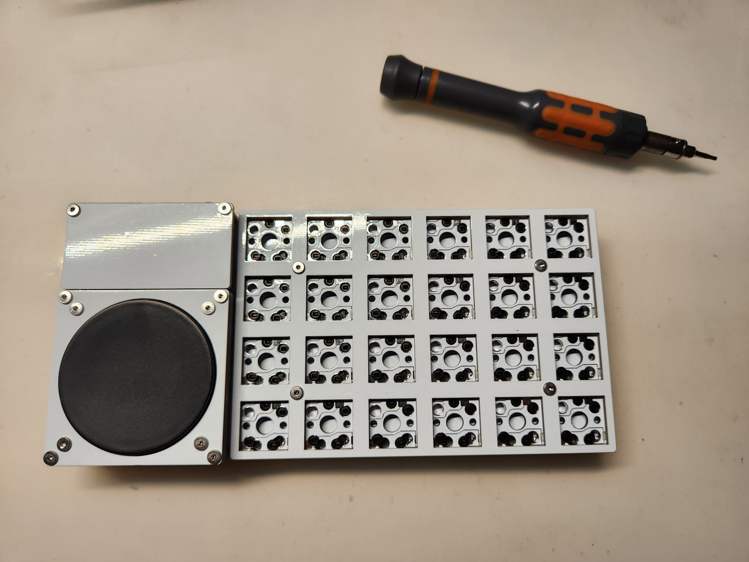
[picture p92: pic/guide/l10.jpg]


### 旋鈕編碼器

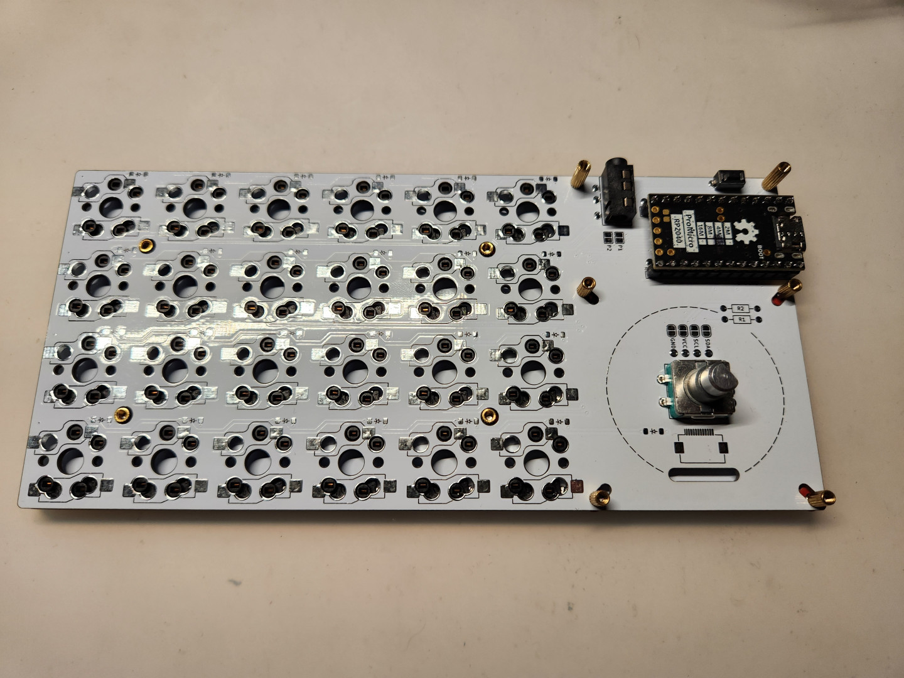
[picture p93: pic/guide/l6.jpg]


編碼器的部分也是一樣，將電路板放在底板上，並安裝好對應長度的銅柱。

接著再將旋鈕帽蓋安裝上去。

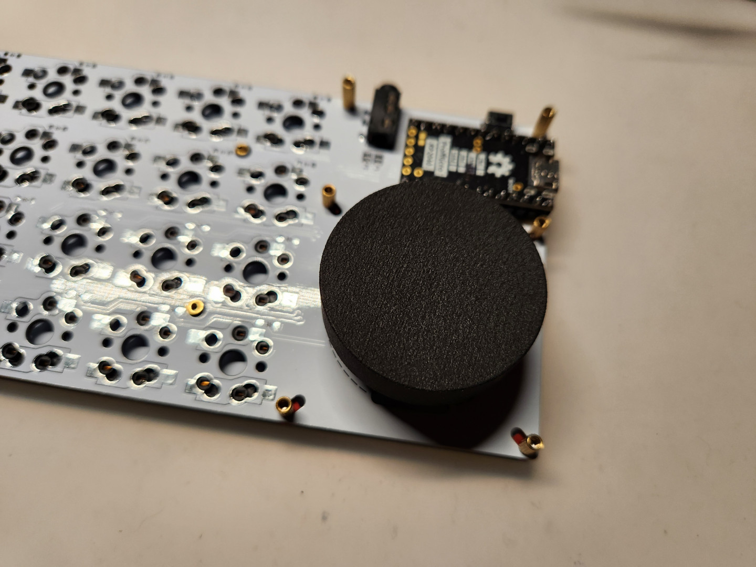
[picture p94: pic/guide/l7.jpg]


編碼器這裡的擋板部分堆疊順序會跟觸控板相反，將擋板用螺絲螺帽固定好之後，就可以直接安裝了。

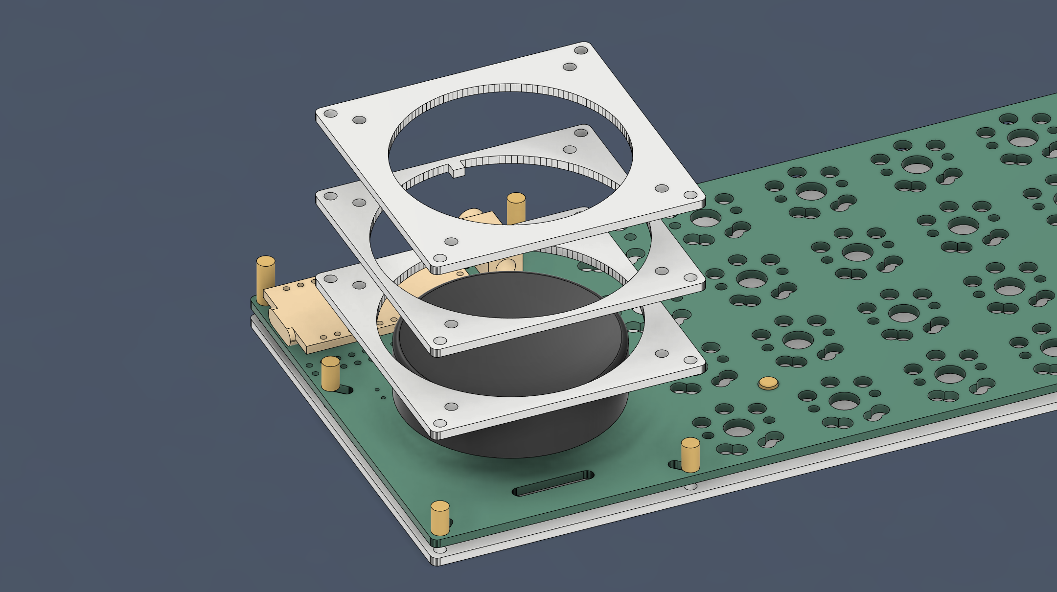
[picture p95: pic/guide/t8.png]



最後將鍵盤翻至背面，貼上`腳貼`就完成了。



## 安裝軸帽

鍵軸及鍵帽可以最後再安裝，看個人選擇，這裡安裝使用的是凱華Choc v2黑雲軸。



鍵帽使用的是太豪THT，十字矮軸、無刻的版本。



完成！



### 韌體燒錄

> 韌體安裝順序可不同，若要在組裝鍵盤之前先燒錄的話，請對應使用的MCU，使用對應的燒錄方式。

- 組裝鍵盤前：

    - ATMega32U4 ProMicro：可使用`QMK Toolbox`及`QMK MSYS`進行燒錄。
    - RP2040 ProMicro：啟動`RP_BOOT`模式，將`.uf2`韌體燒進硬碟裡即可。

> `RP_BOOT`模式有兩種方式可以啟動：
> 1. 將MCU上的`BOOT`按鈕按住後接入電腦後啟動。
> 2. 接入電腦後按住`BOOT`按鈕1秒後再按`RESET`按鈕後啟動。

- 組裝鍵盤後：

    - ATMega32U4 ProMicro：可使用`QMK Toolbox`及`QMK MSYS`進行燒錄，`RESET`按鈕壓一下就可啟動燒錄模式。
    - RP2040 ProMicro：電路板上的`RESET`輕觸開關`按2下之後1秒放開`，會啟動`RP_BOOT`模式，將`.uf2`韌體燒進硬碟裡即可。

> MCU的背面也有對應的`RESET`及`BOOT`孔可以用鑷子觸發，不用擔心燒錄問題。

### 硬體除錯測試

> RP2040 ProMicro的`通信問題`，請將電路板上的`P1`跳線移除後改至`P2`連接再做測試。

> 鍵盤按鍵部分，請將`VIAL`打開進入`Matrix Tester`，若已經插入鍵軸就把所有按鍵都按過一輪，若沒有請用鑷子測試每顆按鍵上的熱插拔座`焊盤`或`針腳`。



> 若要測試旋鈕編碼器上頭的按鍵，對應`Layout`的部分，將開關打開再進行`Matrix Tester`測試。



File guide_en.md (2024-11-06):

# Building Gudie



## Basic Install Process

### Diodes

1N4148 is the most commonly used diode in mechanical keyboards, there are `SMD` type and `THT` type, here we use the SMD type, the direction corresponds to the following picture:



SMD diodes are quite tiny and require a little twisting of the light with tweezers to bring out their direction, so our first step is to mount the diodes in a total of `25 places` on the top of the keyboard:



### Hot-swap Sockets

After mounting the diode, solder the hot-swap sockets:



Blank supports both `Choc` and `GLP` hot-swap socket, you can choose one to install, the pin layout is as shown below:



Connect the jumper `P1` under the TRRS after installation:

- `P1` is the default power connection protocol for TRRS, which is basically used by ATMega32U4 ProMicro and RP2040 ProMicro.

> If the RP2040 ProMicro shows `Communication Problems` on the left and right side, please remove the solder on `P1` and change to `P2` and do the communication test again.



### MCU

Then install the MCU according to the place on the board and the `VCC` and `GND` on the top, with the chip side facing down.

> The pins are available in either THT or plug-in versions. For testing reasons, the photo shows the plug-in version, so please refer to it.




> The plug-in pin header installation.



Next install the `TRRS jack` and the `2pin tactile switch` (you don't need to install the TRRS jack if you only need to install a single-side keyboard).



## Cirque 40mm Trackpad Module

- Please be sure to read through the gudie of beekeeb and Keycapsss, the information in both guides will be combined in below:

    - [Cirque Trackpad i2c on Corne Keyboard Build Log](https://beekeeb.com/cirque-trackpad-i2c-on-corne-keyboard/)。
    - [GlidePoint Cirque Trackpad with Adapter PCB](https://keycapsss.com/help/cirque-trackpad/#spi-or-i2c)。

In order to design this keyboard I ordered the trackpad module kit from the web store, and then bought an FFC connector to build the keyboard on.

- The structure of the keyboard takes reference from beekeeb and bastardkb [Dilemma](https://docs.bastardkb.com/bg_dilemma/v2.html) design, the FFC connector will be installed on the back side of the board, on the same side as the hot-swap sockets (please see the photo below for comparison).
- Use the two guides to install the module kit, the length of the spacers posts will need to be adjusted.
- Blank uses `I2C` mode to drive the trackpad.

> The photo is from beekeeb:



> After finishing the Blank:



Below is a combined information of two trackpad module kit guides from beekeeb and Keypasss:

- The `I2C` mode requires to remove some components on the trackpad PCB and add ones that need to be installed:

|MCU|IC|VCC|Resistor R1|Resistor R7|Resistor R8|4.7K pull-up resistor|
|--|--|--|--|--|--|--|
|ProMicro|ATMega32U4|5V|Remove|Remove|Remove|Needed|
|ProMicro|RP2040|3V3|Remove|-|-|Needed|

> The trackpad photo is from Keycapsss：



### FFC Socket



It is difficult to solder the FFC connector with a soldering iron, so it is recommended to use a hot plate or a heat gun to solder it to the PCB.



> It is important to note that a certain amount of `flux` will need to be brushed onto the hot plate.



After the FFC connector is mounted, attach the cable to it.



After attaching the cable, go the cable through the holes on the underside to the other side.



### Pull-up Resistor



The pull-up resistor part is very simple, bend the pins slightly, insert them into the pad holes on R1 and R2, solder them, and remove the unnecessary parts.



### FFC Adapter (I2C Adapter)

- Attention when installing the adapter:

    - Before installation, all I2C `jumper`s on the front side of the PCB must be connected for normal use (check the picture below).
    - The FFC connector adapter is a module developed by the store to allow users to install it freely, and the installation method should be referred to the guides of the store.
    - The use of the adapter will increase the thickness of the mounting position, so you need to adjust the height of the `spacer' by yourself.

pcb1

### Covers



After removing the resistors from the trackpad, assemble the trackpad body and the 3 covers together. First of all, the diameter of the holes in the cover `A` and `C` are not the same, and the order of the cover up and down is different depending on the components installed.

t7

Then place cover `A` and `B` in pairs and lay them flat.



The trackpad is placed in the middle, and don't worry about installation errors.



Then stack the cover `C` plates on top of each other.



Finally screw together with `6mm screws` and `nuts`.




## Rotray Encoder (Knob)

Installation of the rotary encoder part is quite simple, just follow the correct pin layout and solder it.



## Case



The bottom plate will be fitted with screws of the correct length for the places shown in the photo, and the installation process will be explained later.

Firstly, the `8mm screws` will be screwed in place with `nuts`.



The `4mm screw` part will be held in place with the `5mm` spacers.



After putting the washers on the screws, set them aside for now until you can use them.



## Last Step

No matter whether the optional part is a trackpad or a rotray encoder, the final installation is basically the same.

### Trackpad

The first part is to build up the trackpad, place the PCB against the bottom plate and install the correct length of spacers as shown in the photo.




Then connect the FFC cable to the connector on the trackpad, follow the direction of the cable and put the plate into the screw holes, and screw it up with `6mm screws`.




Lastly, screw the plate and the MCU cover with `3mm screws` in order.




### Rotray Encoder (Knob)



The same is done for the rotray encoder part, place the PCB on the bottom plate and install the spacers with the correct length.

Then install the cap.



The covers at the encoder will be stacked in the reverse direction of the trackpad, so you can install the rotray encoder directly after screwing.




Finally, turn the keyboard over to the back and put on the `cushion rubber` and you're done.



## Switches and Keycaps

Keyswitches and keycaps can be installed at the end, depending on your choice. Here, we used Kailh Choc v2 Black Cloud.



The keycaps used are Tai-hao THT low profile, blank version.



DONE!



### Firmware

> The firmware installation process can be different. If you want to flash before building the keyboard, please use the correct method for the MCU you want to use.

- Before building:

    - ATMega32U4 ProMicro: can use `QMK Toolbox` or `QMK MSYS` to flash the firmware.
    - RP2040 ProMicro: drive `RP_BOOT` mode, then put the `.uf2` firmware to the hard-disk。

> It have 2 methods to drive the `RP_BOOT` mode:
> 1. Press the `BOOT` button on the MCU then plug in to your device.
> 2. After plugging into the device, press the `BOOT` botton about 1 second, then press the botton `RESET`.

- After building:

    - ATMega32U4 ProMicro: can use `QMK Toolbox` or `QMK MSYS` to flash the firmware, one press the `RESET` botton to drive the flash mode。
    - RP2040 ProMicro: press twice the `tactile switch` (`RESET`) on the PCB side and hold 1 second, then it will drive the `RP_BOOT` mode, put the `.uf2` firmware to the hard-disk to flash.

> There are also having `RESET` and `BOOT` holes on the back of the MCU that can be triggered by tweezers, so you don't have to worry about flashing issue.

### Debug

> RP2040 ProMicro `Communication problem`, please remove the `P1` jumper on the board and change it to `P2` connection and test again.

> For the keyboard keyswitches section, turn on `VIAL` and go to `Matrix Tester`, if you have to tap keyswitches go through all of them, if not use tweezers to test for `solder pads` or `pins` on each key.



> To test the keys on the top of the rotary encoder, open the switch against the `Layout` section and test with the `Matrix Tester`.



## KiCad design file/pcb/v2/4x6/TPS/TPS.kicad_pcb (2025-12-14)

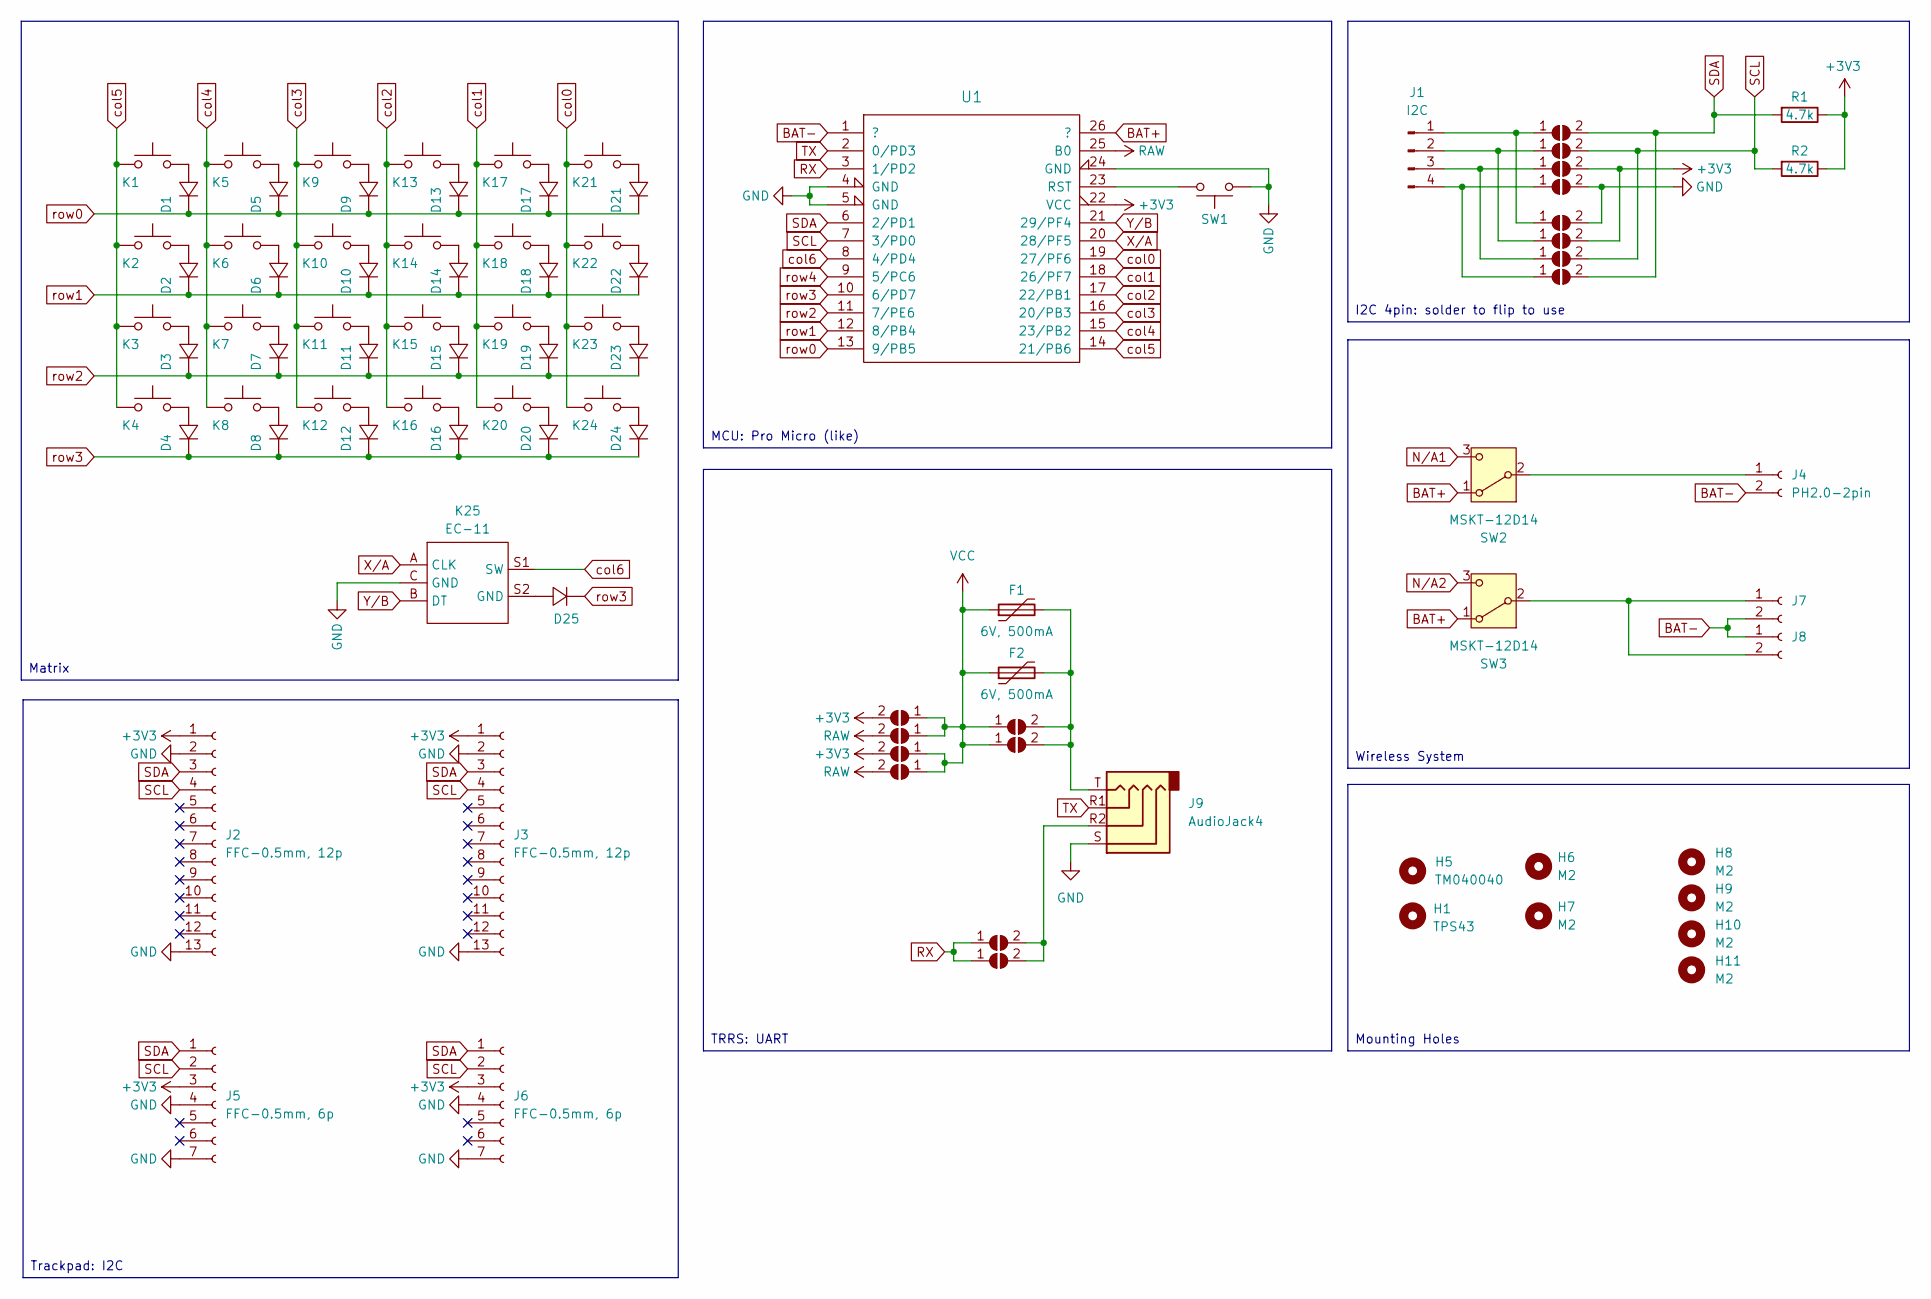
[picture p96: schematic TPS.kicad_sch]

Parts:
D1, D2, D3, D4, D5, D6, D7, D8, D9, D10, D11, D12, D13, D14, D15, D16, D17, D18, D19, D20, D21, D22, D23, D24, D25: 1N4148_SMD; D_SOD-123_handsolder_dual
F1, F2: 6V, 500mA; Fuse_0805_2012Metric
H1: TPS43; Azoteq_TPS43_201A_S
H5: TM040040; Trackpad_Cirque_TM040040
H6, H7, H8, H9, H10, H11: M2; MountingHole_2.2mm_M2
J1: I2C; PinHeader_1x04_P2.54mm_Vertical
J2, J3: FFC-0.5mm, 12p; Hirose_FH12-12S-0.5SH_1x12-1MP_P0.50mm_Horizontal
J4: PH2.0-2pin; JST_PH_S2B-PH-K_1x02_P2.00mm_Horizontal_dual
J5, J6: FFC-0.5mm, 6p; Hirose_FH12-6S-0.5SH_1x06-1MP_P0.50mm_Horizontal
J7, J8: PinHeader_1x02_P2.54mm_Vertical
J9: AudioJack4; TRRS-PJ-320A, dual side x2_3rd
JP1, JP2, JP3, JP4: PWR1; SolderJumper-2_P1.3mm_Open_Pad1.0x1.5mm
JP5, JP6, JP7, JP8, JP9, JP10, JP11, JP12: PWR1; SolderJumper-2_P1.3mm_Open_RoundedPad1.0x1.5mm
JP13, JP14: RX; SolderJumper-2_P1.3mm_Open_RoundedPad1.0x1.5mm
JP15, JP16: VCC; SolderJumper-2_P1.3mm_Open_Pad1.0x1.5mm
K1, K2, K3, K4, K5, K6, K7, K8, K9, K10, K11, K12, K13, K14, K15, K16, K17, K18, K19, K20, K21, K22, K23, K24: SW_Push; SW_Hotswap_KLP12_GLP3.0_MX_Plated_1.00u_Dualside
K25: EC-11; RotaryEncoder_EC11
R1, R2: 4.7k; R_Axial_DIN0204_L3.6mm_D1.6mm_P7.62mm_Horizontal
SW1: SW_Push; ResetSW_1side
SW2, SW3: MSKT-12D14; SW_SPDT_MSKT-12D14_SMD_dual
U1: MCU_ProMicro_13p; MCU_ProMicro_13p_dual

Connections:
+3V3: J2.1, J3.1, J5.3, J6.3, JP1.2 (B), JP3.2 (B), JP7.2 (B), JP10.2 (B), R1.1, R2.1, U1.22 (VCC)
BAT+: SW2.1 (A), SW3.1 (A), U1.26 (?)
BAT-: J4.2, J7.2, J8.1, U1.1 (?)
GND: J2.2, J2.13, J3.2, J3.13, J5.4, J5.7, J6.4, J6.7, J9.S, JP8.2 (B), JP9.2 (B), K25.C (GND), SW1.1, U1.4 (GND), U1.5 (GND), U1.24 (GND)
unnamed: D1.2, K1.2
unnamed: D2.2, K2.2
unnamed: D3.2, K3.2
unnamed: D4.2, K4.2
unnamed: D5.2, K5.2
unnamed: D6.2, K6.2
unnamed: D7.2, K7.2
unnamed: D8.2, K8.2
unnamed: D9.2, K9.2
unnamed: D10.2, K10.2
unnamed: D11.2, K11.2
unnamed: D12.2, K12.2
unnamed: D13.2, K13.2
unnamed: D14.2, K14.2
unnamed: D15.2, K15.2
unnamed: D16.2, K16.2
unnamed: D17.2, K17.2
unnamed: D18.2, K18.2
unnamed: D19.2, K19.2
unnamed: D20.2, K20.2
unnamed: D21.2, K21.2
unnamed: D22.2, K22.2
unnamed: D23.2, K23.2
unnamed: D24.2, K24.2
unnamed: D25.2, K25.S2 (GND)
unnamed: J1.1, JP5.1 (A), JP9.1 (A)
unnamed: J1.2, JP6.1 (A), JP10.1 (A)
unnamed: J1.3, JP7.1 (A), JP11.1 (A)
unnamed: J1.4, JP8.1 (A), JP12.1 (A)
unnamed: J4.1, SW2.2 (B)
unnamed: J7.1, J8.2, SW3.2 (B)
unnamed: J9.R2, JP13.2 (B), JP14.2 (B)
unnamed: F1.2, F2.2, J9.T, JP15.2 (B), JP16.2 (B)
unnamed: SW1.2, U1.23 (RST)
N/A1: SW2.3 (C)
N/A2: SW3.3 (C)
RAW: JP2.2 (B), JP4.2 (B), U1.25 (B0)
RX: JP13.1 (A), JP14.1 (A), U1.3 (1/PD2)
SCL: J2.4, J3.4, J5.2, J6.2, JP6.2 (B), JP11.2 (B), R2.2, U1.7 (3/PD0)
SDA: J2.3, J3.3, J5.1, J6.1, JP5.2 (B), JP12.2 (B), R1.2, U1.6 (2/PD1)
TX: J9.R1, U1.2 (0/PD3)
VCC: F1.1, F2.1, JP1.1 (A), JP2.1 (A), JP3.1 (A), JP4.1 (A), JP15.1 (A), JP16.1 (A)
X/A: K25.A (CLK), U1.20 (28/PF5)
Y/B: K25.B (DT), U1.21 (29/PF4)
col0: K21.1, K22.1, K23.1, K24.1, U1.19 (27/PF6)
col1: K17.1, K18.1, K19.1, K20.1, U1.18 (26/PF7)
col2: K13.1, K14.1, K15.1, K16.1, U1.17 (22/PB1)
col3: K9.1, K10.1, K11.1, K12.1, U1.16 (20/PB3)
col4: K5.1, K6.1, K7.1, K8.1, U1.15 (23/PB2)
col5: K1.1, K2.1, K3.1, K4.1, U1.14 (21/PB6)
col6: K25.S1 (SW), U1.8 (4/PD4)
row0: D1.1, D5.1, D9.1, D13.1, D17.1, D21.1, U1.13 (9/PB5)
row1: D2.1, D6.1, D10.1, D14.1, D18.1, D22.1, U1.12 (8/PB4)
row2: D3.1, D7.1, D11.1, D15.1, D19.1, D23.1, U1.11 (7/PE6)
row3: D4.1, D8.1, D12.1, D16.1, D20.1, D24.1, D25.1, U1.10 (6/PD7)
row4: U1.9 (5/PC6)

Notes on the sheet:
I2C 4pin: solder to flip to use
Trackpad: I2C
Mounting Holes
TRRS: UART
Wireless System
MCU: Pro Micro (like)
Matrix

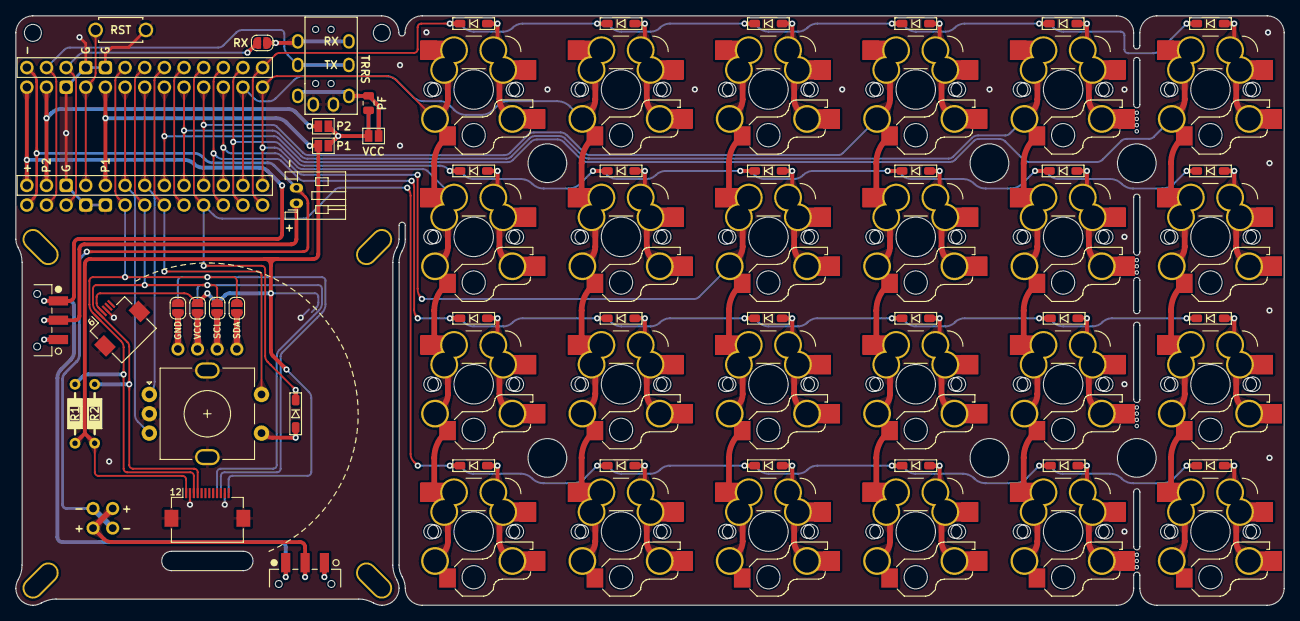
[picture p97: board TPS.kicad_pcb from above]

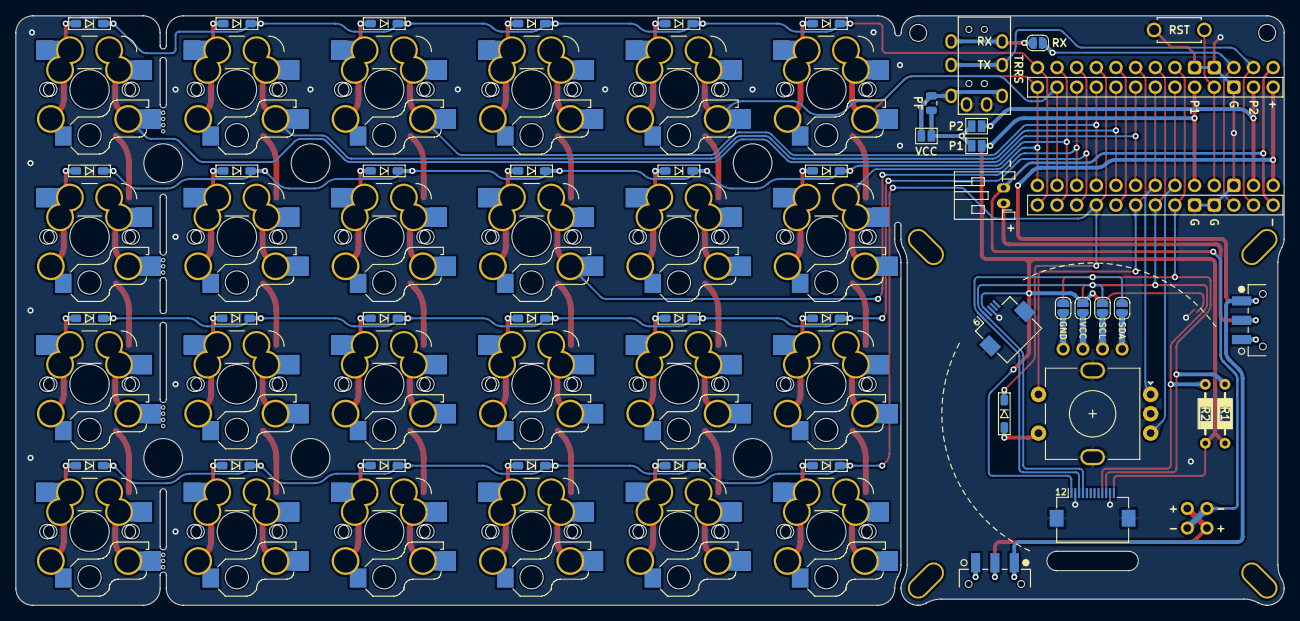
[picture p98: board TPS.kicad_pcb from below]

Board: 2 copper layers, 164.0 x 76.2 mm, 95 parts (12 on the bottom side), 57 nets.

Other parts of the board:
H14, H15, H16, H17: edge; Breakaway_Tabs_2

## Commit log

2024-08-17 update pcb&step
    [39mm_h4.5mm_ec11_hat.step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]
2024-11-06 fix thickness of the plate
2024-11-06 update v1 5x6 version
    [TPS-B_Cu.gbr, TPS-B_Mask.gbr, TPS-B_Paste.gbr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]
2025-01-26 update blank-kc rgb pcb
    [LED-Layout-4x6.xlsx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]
2025-01-28 remove blankrgb pcb files
    [LED-Layout-4x6.xlsx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]
2025-10-31 clean file and upload v2
    [TPS-B_Cu.gbr, TPS-B_Mask.gbr, TPS-B_Paste.gbr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]
2025-10-31 upload v2
    [TPS-B_Cu.gbr, TPS-B_Mask.gbr, TPS-B_Paste.gbr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]
2025-10-31 fix v2 bottom case
    [TPS-B_Cu.gbr, TPS-B_Mask.gbr, TPS-B_Paste.gbr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]
2025-11-01 fix v2 bom list
2025-11-02 add TPS43 module
    [TPS-B_Cu.gbr, TPS-B_Mask.gbr, TPS-B_Paste.gbr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]
2025-11-02 upload v2 3d files
    [TPS-tapcover.step]
2025-11-03 upload 5x6 case
    [TPS-B_Cu.gbr, TPS-B_Mask.gbr, TPS-B_Paste.gbr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]
2025-11-04 fix 5x6 PCB
    [TPS-B_Cu.gbr, TPS-B_Mask.gbr, TPS-B_Paste.gbr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]
2025-11-04 fix 5x6 Plate
    [TPS-B_Cu.gbr, TPS-B_Mask.gbr, TPS-B_Paste.gbr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]
2025-11-04 fix plate
    [TPS.kicad_pcb]
2025-11-20 fix TRRS TX/RX pins
    [TPS-B_Cu.gbr, TPS-B_Mask.gbr, TPS-B_Paste.gbr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]
2025-12-14 fix main PCB file UI
    [TPS-B_Cu.gbr, TPS-B_Mask.gbr, TPS-B_Paste.gbr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]
